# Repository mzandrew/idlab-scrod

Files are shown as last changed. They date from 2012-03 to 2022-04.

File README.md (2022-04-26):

# idlab-scrod
FPGA firmware + PC software to control and readout waveform sampling ASICs for high-energy physics experiments

This repository archives the firmware (etc) for an electronics module for Belle II bPID readout.
It consists of 128 channels of 2.7GSa/s @ 12bits per sample Wilkinson ADC readout (via 16 waveform sampling ASICs), controlled by FPGAs with data streaming out over a 2.544Gbit/s LC-LC duplex fiber optic link.
An array of 16-anode micro-channel plate photomultiplier tubes (MCP-PMTs) will be mounted to detect single photoelectrons, creating an image plane with a resolution of 64*16 pixels.
Four of these modules will be mated to a highly polished quartz bar and expansion volume.
The system is able to discern the difference between high momentum kaons and pions traveling through the bar (via a folded Cherenkov image projected on the PMTs).

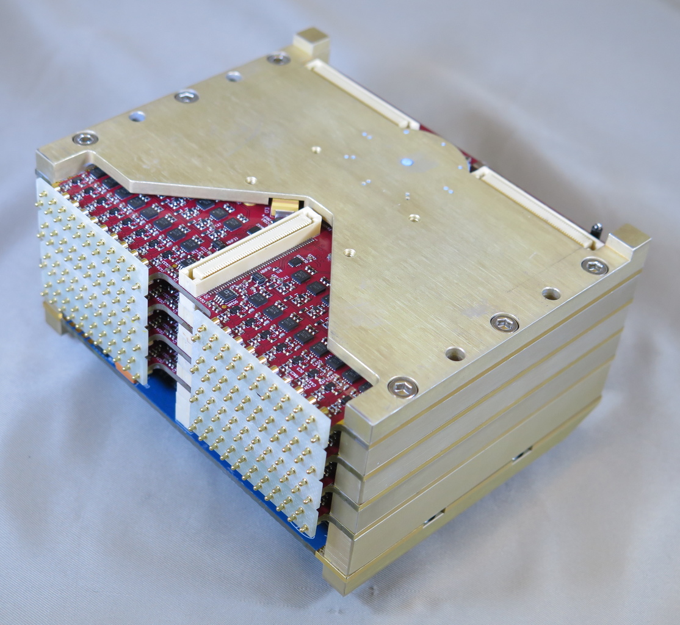
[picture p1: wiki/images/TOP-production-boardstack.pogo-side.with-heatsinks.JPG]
an electronics module for Belle II bPID readout


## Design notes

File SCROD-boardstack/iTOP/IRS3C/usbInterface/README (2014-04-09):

Installing USB interface (Linux only)

1) Install libusb:
Ubuntu: sudo apt-get install libusb-1.0-0-dev
Alternatively: 
-download stable version of libusb-1.0.x from http://www.libusb.org/ (currently libusb-1.0.9)
-follow installation instructions

2) Install ROOT:
-see http://root.cern.ch/ (tested with 5.34/03)

3) Compile code:
-go to usbInterface directory: cd usbInterface/
-compile: make

Using USB interface:

1) Attach USB cable before powering on frontend boards
-USB interface only tested with local clock, distributed FTSW clock should work but not tested

2) Check that the Cypress USB interface controller is detected:
-use lsusb to get a list of USB devices, should return: Bus ### Device ###: ID 04b4:1004 Cypress Semiconductor Corp.
-if Cypress device is not found try power cycling the board
-if Cypress firmware is not "04b4:1004", check that fw.hex file is present then reprogram firmware: 
Command: ./load_cypress_firmware
-alternatively, program the eeprom following the instructions here:
http://www.triplespark.net/elec/periph/USB-FX2/eeprom/
Software: http://www.triplespark.net/elec/periph/USB-FX2/eeprom/fxload-full-2008_10_13-ww3.tar.gz
Command: fxload -D /dev/bus/usb/002/016 -I fw.hex -c 0x01 -s Vend_Ax.hex -t fx2

3) Program FPGA (tested with bit file scrod_top_intermediatedIRS3C_20140401.bit included in top directory)

4) Initialize frontend + ASICs: ./bin/irs3BControl_initialize

5) Try reading a generial i/o register #0: ./bin/irs3BControl_readReg 0
-if there is a "Permission denied." error, give the USB interface the required permissions eg: sudo chmod a+rw /dev/bus/usb/<bus #>/<device #>

5) Try taking data: ./bin/irs3BControl_takeData
-hardcode to route calibration input to ASIC row 0 col 2 ch 2, does software triggered forced readouts on this channel
-this should display sampled waveforms one at a time

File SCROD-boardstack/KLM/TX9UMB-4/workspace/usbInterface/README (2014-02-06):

Installing USB interface (Linux only)

1) Install libusb:
Ubuntu: sudo apt-get install libusb-1.0-0-dev
Alternatively: 
-download stable version of libusb-1.0.x from http://www.libusb.org/ (currently libusb-1.0.9)
-follow installation instructions

2) Install ROOT:
-see http://root.cern.ch/ (tested with 5.34/03)

3) Compile code:
-go to usbInterface directory: cd usbInterface/
-compile: make

Using USB interface

1) Attach USB cable before powering on frontend boards
2) Program FPGA (tested on SPARTAN6 with bit file scrod_top.bit included in directory)
3) Check that the Cypress USB interface controller is detected:
-use lsusb to get a list of USB devices, should return: Bus ### Device ###: ID 04b4:1004 Cypress Semiconductor Corp.
-if Cypress device is not found try power cycling the board
-if Cypress firmware is not "04b4:1004", check that fw.hex file is present then reprogram firmware: ./load_cypress_firmware
4) Try reading a generial i/o register #0: ./bin/target6Control_readReg 0
-if there is a "Permission denied." error, give the USB interface the required permissions eg: sudo chmod a+rw /dev/bus/usb/002/005

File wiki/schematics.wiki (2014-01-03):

#summary schematics for front-end board stacks, including SCROD
#labels Deprecated

= Introduction =

This page has all the latest schematics, PCB layout files and gerbers for all front-end boards that the IDLAB has made.

== SCROD ==

[http://idlab-scrod.googlecode.com/files/2011-01-10.SCROD.revA.sch SCROD rev A schematic] ([http://idlab-scrod.googlecode.com/files/2011-01-10.SCROD.revA.schematic.pdf schematic pdf])

[http://idlab-scrod.googlecode.com/files/2011-01-10.SCROD.revA.pcb SCROD rev A batch 1 layout] ([http://idlab-scrod.googlecode.com/files/2011-01-10.SCROD.revA.layout.pdf rev A batch 1 layout pdf]) (rev A batch 1 gerbers)

[http://idlab-scrod.googlecode.com/files/2011-06-09.SCROD.revA.batch2.pcb SCROD rev A batch 2 layout] ([http://idlab-scrod.googlecode.com/files/2011-06-09.SCROD.revA.batch2.layout.pdf rev A batch 2 layout pdf]) ([http://idlab-scrod.googlecode.com/files/2011-06-09.SCROD.revA.batch2.gerbers.zip rev A batch 2 gerbers]) ([http://idlab-scrod.googlecode.com/files/2011-06-21.SCROD.revA-batch2.assembly-files.zip rev A batch 2 assembly files, including BOM])

note:  The batch 1 layout/gerbers are only different from the batch 2 layout/gerbers on the silkscreen layer.

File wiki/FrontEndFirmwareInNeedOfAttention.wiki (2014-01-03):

#summary A list of front-end firmware tasks that currently need attention:
#labels Deprecated

  * ASIC trigger width output feedback - ensure that the trigger bits out of the ASIC remain high for long enough for us to see them in the following two items.
  * Scaler rate monitors for all trigger bits - count the number of trigger edges seen.  Counter is reset by an external signal, probably a software command.
  * Trigger data stream implementation - a running "waveform" of trigger bits, see documentation page 12 ( http://www.phys.hawaii.edu/~kurtisn/documentation/bPID_electronics/2011-09-01.BelleII-bPID.electronics-documentation.pdf )
  * Merge Xiao-Wen's temperature sensor readout into main code
  * Merge Xiao-Wen's EEPROM code to set/get SCROD ID into main code.

2011-09-15 firmware block diagram (click image to download full size version):

[http://idlab-scrod.googlecode.com/files/2011-09-15.SCROD-beam-test-firmware-block-diagram.whiteboard.jpeg http://idlab-scrod.googlecode.com/files/2011-09-15.SCROD-beam-test-firmware-block-diagram.whiteboard.lowres.jpeg]

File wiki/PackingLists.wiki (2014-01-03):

#summary Items to bring to various integration tests
#labels Deprecated

The following are a list of items to bring for the following tests:

= 2011 December Fermilab beamtest =

== big things: ==

  * 350MHz scope
  * 8 cat6 cables
  * 80MHz signal generator
  * power supply (off the shelf)
  * power supply (Matt's)
  * 1 power cable bundle
  * cPCI crate + DSP_cPCI
  * SciFi (2 * eKLM_MB + 2 * budboxes)

travel toolkit with:
  * soldering irons
  * solder
  * soldering tools

== little things: ==

  * 4 * 15m fiber optic cables
  * 3 complete board stacks (1 Kurtis; 2 ??)
  * 3 populated SL10_HV rev A3 boards
  * NIM pocket pulser + spare batteries
  * voltmeter + ez-hook / sharp leads
  * loupe
  * FTSW (well packed)
  * CAMAC crate controller
  * "AMPs"
  * attenuators
  * SMA, BNC, LEMO adaptors kit
  * 2mm-SMA adaptor
  * "lots of blk & cu tape"
  * all IRS2_DC revB boards
  * tygon tubing
  * USB/cat5 cable adaptor

calibration sources:
  * 100MHz and 500 MHz oscillators
  * VCO

the following spare discrete components:
  * temperature sensors
  * IRS2_DC signal path components (AMPs, diodes, caps)
  * HV res/cap
  * 0 Ohm resistors

== things we are skipping ==
3GHz sine wave generator
fast pulser

= September 2011 - Second Nagoya Integration Trip =

  * Minimum of the following boards, debugged for shorts and opens:
    * 3x SCROD 
    * 3x Interconnect
    * 3x ASIC carrier level 0 (silkscreen not labeled with a number)
    * 4x ASIC carrier level 1 (silkscreen labeled "1")
      * (2x?) Extra temperature sensors 
    * 4x ASIC carrier level 2 (silkscreen labeled "2")
    * 4x ASIC carrier level 3 (silkscreen labeled "4")
    * 41x IRS2 Daughter cards, rev B
      * 1000x 0-ohm resistors to set DAC addresses (if not done before departure)
      * 100x Fair-rites
    * 5x Front-front boards
    * 4x Front-back boards
    * 5x HV boards
    * 1x Front-middle
  * 2x mini-USB cables
  * 2x Xilinx programmers
  * JTAG programmer with flying leads
  * 5x long (15 m) fiberoptic cables
  * Wifi router
  * HV panel (soldered to HV boards)
  * CAT-5 cable bundle
  * RJ45 crimp ends
  * RJ45 crimper
  * 32 HV cables (SHV - SHV)
  * 4x LV cables
  * Mechanical enclosure
  * Set screws
  * Screwdriver
  * Loc-tite
  * 4x fiberoptic transceivers
  * 1-2x USB hubs
  * SMA connectors
  * Vector board

= August 2011 - First Nagoya Integration Trip =

  * Mixed signal oscilloscope and probes(?)
  * Minimum of the following boards, debugged for shorts and opens:
    * 2x SCROD 
    * 2x Interconnect
    * 2x ASIC carrier level 0 (silkscreen not labeled with a number)
    * 2x ASIC carrier level 1 (silkscreen labeled "1")
    * 2x ASIC carrier level 2 (silkscreen labeled "2")
    * 2x ASIC carrier level 3 (silkscreen labeled "4")
    * 4x IRS2 Daughter cards (with or without all amplifiers TBD)
    * 1x IRS2 on BLAB3A daughter card ("golden child")
    * 2x Front-front boards
    * 2x Front-back boards
    * 2x HV boards
    * 1x Front-middle
    * 2x CLK_FIN (FIN_CLK)?
    * 1x cPCI_FIN
    * 1x FIN_USB
  * 2x mini-USB cables
  * 2x Xilinx programmers
  * JTAG programmer with flying leads
  * 1x cPCI crate
  * 2x DSP_cPCI
  * 4x short fiberoptic cables
  * 2x long fiberoptic cables
  * 1x cPCI CPU and hard drive cards
  * RJ-45 related:
    * Crimper
    * Cable (CAT-5 or CAT-6)
  * Wiener CAMAC controller
  * Power supplies??
  * High voltage supplies??

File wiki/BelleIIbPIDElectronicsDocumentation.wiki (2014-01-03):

#summary Documentation for (cosmic / beam test version as well as final version) of Belle II bPID Electronics
#labels Deprecated

=introduction=

The following is a revision history of documentation for the Belle II barrel particle identification system.  Information will change rapidly, so all documentation should be considered preliminary, unless otherwise noted.

=current version=

  * [http://www.phys.hawaii.edu/~kurtisn/doku.php?id=documentation 2012-09-24 preliminary documentation for final version of iTOP system documentation] - pre-final iTOP version

  * [http://idlab-scrod.googlecode.com/files/2011-10-16.BelleII-bPID.electronics-documentation.pdf 2011-10-16 Belle II bPID electronics documentation] - "beam-test" version - Minor development of some data packet formats.

=previous versions=

  * [http://idlab-scrod.googlecode.com/files/2011-09-10.BelleII-bPID.electronics-documentation.pdf 2011-09-10 Belle II bPID electronics documentation] - More development of raw waveform data packet format, as well as a new system block diagram.

  * [http://idlab-scrod.googlecode.com/files/2011-09-01.BelleII-bPID.electronics-documentation.pdf 2011-09-01 Belle II bPID electronics documentation] - Significant changes made to structure of document, as well as details on raw data formats.  This version is specifically about the cosmic / beam test version of the electronics with a deemphasized verbiage 

  * [http://idlab-scrod.googlecode.com/files/2011-07-08.BelleII-bPID.electronics-documentation.pdf 2011-07-08 Belle II bPID electronics documentation] - Changes to communication packet formats.

  * [http://idlab-scrod.googlecode.com/files/2011-06-03.BelleII-bPID.electronics-documentation.pdf 2011-06-03 - First version of Belle II bPID electronics documentation] - Includes overview information and descriptions of the front and back-end electronics, as well as the data format proposed for beam test later this year.  Sections on trigger and support electronics are currently empty, as well as the current schedule and milestones.

The original version of this page (now outdated) is located [http://www.phys.hawaii.edu/~kurtisn/documentation/bPID_electronics/ here].

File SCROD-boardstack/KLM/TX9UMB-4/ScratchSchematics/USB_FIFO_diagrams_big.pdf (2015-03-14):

# fifo_wr32_rd16

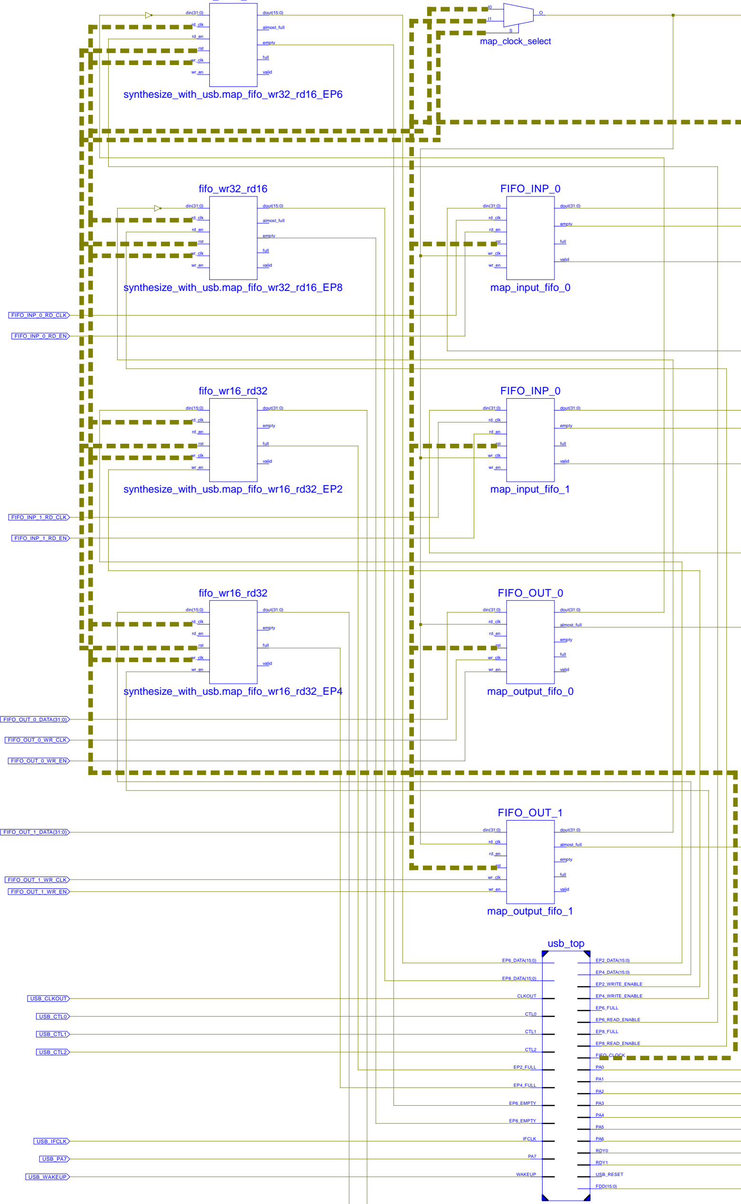
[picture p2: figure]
din(31:0); rd_clk; rd_en rst wr_clk wr_en; dout(15:0); almost_full; empty; full; valid; fifo_wr32_rd16; fifo_wr16_rd32; din(15:0); dout(31:0); map_clock_select; FIFO_INP_0; map_input_fifo_0; map_input_fifo_1; FIFO_OUT_0; map_output_fifo_0; FIFO_OUT_1; map_output_fifo_1; usb_top; EP6_DATA(15:0); EP8_DATA(15:0); CLKOUT; CTL0; CTL1; CTL2; EP2_FULL; EP4_FULL; EP6_EMPTY; EP8_EMPTY; IFCLK; PA7 WAKEUP; EP2_DATA(15:0) EP4_DATA(15:0) EP2_WRITE_ENABLE; EP4_WRITE_ENABLE; EP6_FULL EP6_READ_ENABLE; EP8_FULL EP8_READ_ENABLE; FIFO_CLOCK; FDD(15:0); FIFO_INP_0_RD_CLK; FIFO_INP_0_RD_EN; FIFO_INP_1_RD_CLK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

# synthesize_with_usb.map_fifo_wr32_rd16_EP6

# synthesize_with_usb.map_fifo_wr32_rd16_EP8

# synthesize_with_usb.map_fifo_wr16_rd32_EP2

# synthesize_with_usb.map_fifo_wr16_rd32_EP4

# bufgmux

# synthesize_with_usb.map_usb_interface

# PA0 PA1 PA2 PA3 PA4 PA5 PA6 RDY0 RDY1 USB_RESET

# lut2

# Mmux_internal_FIFO_INP_1_WRITE_DATA71

I0

I1 | O

# lut2

# Mmux_internal_FIFO_INP_0_WRITE_DATA121

I0

I1 | O

### FIBER_0_TXP

### USB_FIFO_CLOCK

### FIFO_INP_0_DATA(31:0)

### FIFO_INP_0_EMPTY

### FIFO_INP_0_VALID

### FIFO_INP_1_DATA(31:0)

### FIFO_INP_1_EMPTY

### FIFO_INP_1_VALID

### FIFO_OUT_0_FULL

### FIFO_OUT_1_FULL

# USB_PA0 USB_PA1 USB_PA2 USB_PA3 USB_PA4 USB_PA5 USB_PA6 USB_RDY0 USB_RDY1

### USB_FDD(15:0)

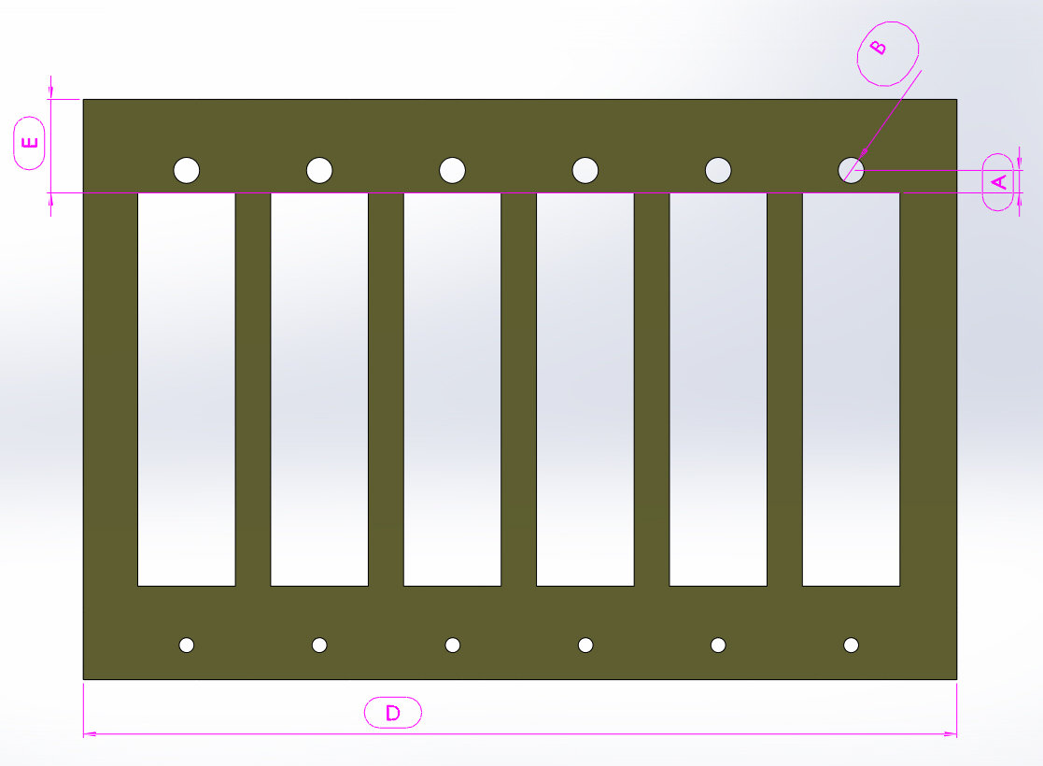
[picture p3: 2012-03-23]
mechanical-designs/board-stack/fDIRC/images/G10-frame.JPG

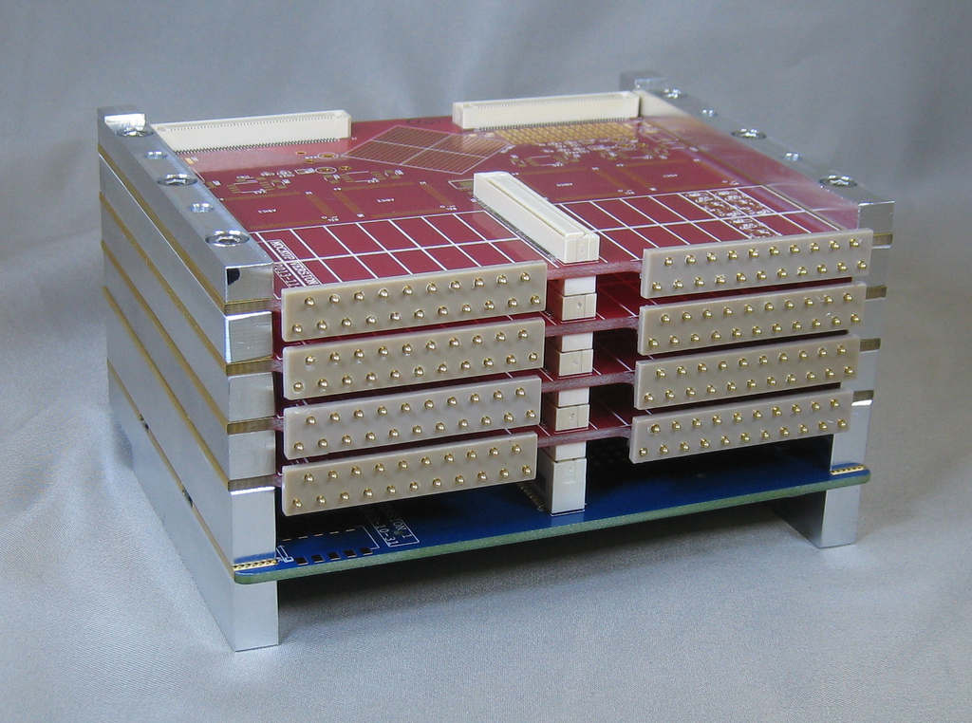
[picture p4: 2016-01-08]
wiki/images/2013-12-03.mechanical-mockup.JPG

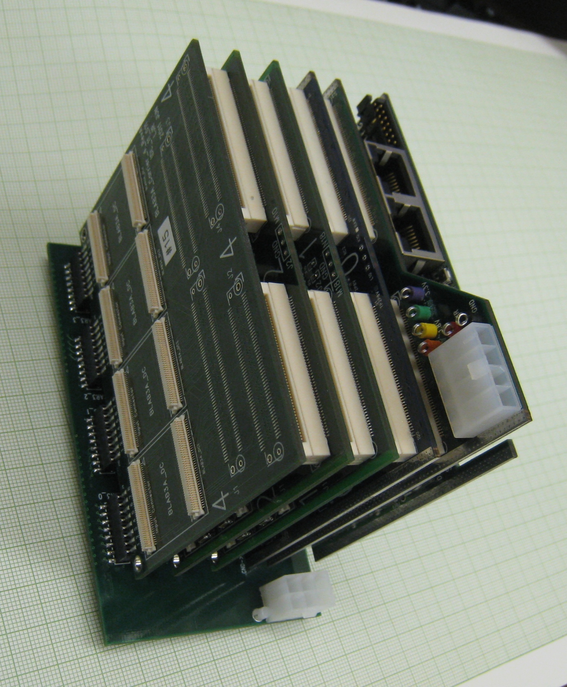
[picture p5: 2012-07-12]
mechanical-designs/board-stack/fDIRC/images/2012-06-04.fDIRC-module.jpeg

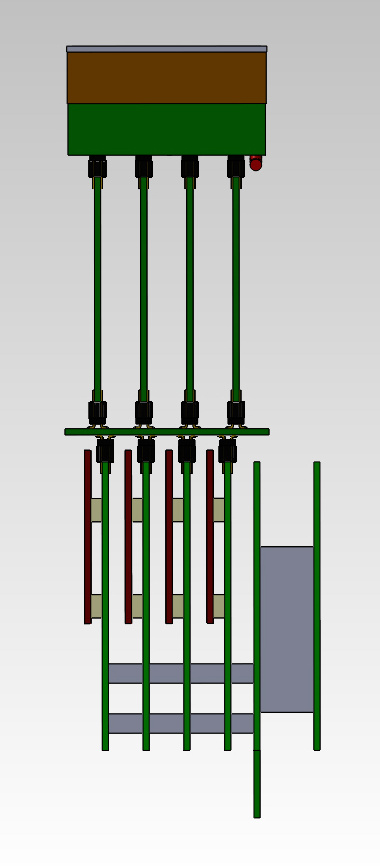
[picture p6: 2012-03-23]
mechanical-designs/board-stack/fDIRC/images/fDIRC.JPG

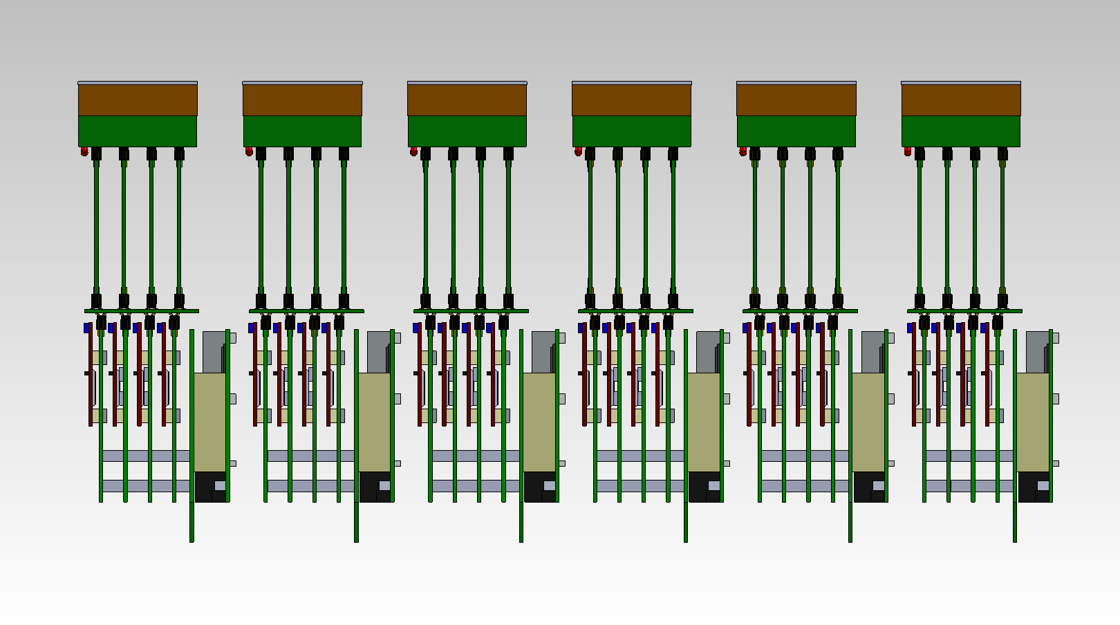
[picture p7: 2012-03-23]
mechanical-designs/board-stack/fDIRC/images/fDIRC-array.JPG

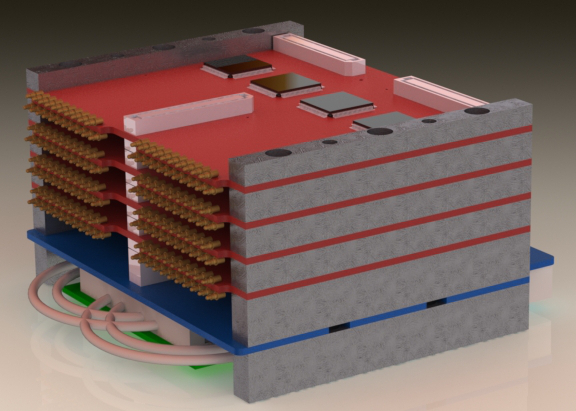
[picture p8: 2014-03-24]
mechanical-designs/board-stack/iTOP/export/SCROD-and-carriers-with-walls.rendered.JPG

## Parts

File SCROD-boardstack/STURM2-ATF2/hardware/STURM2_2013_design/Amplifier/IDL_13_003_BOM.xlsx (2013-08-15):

Item | Qty | Reference designators | Part Name | Value | Size / footprint | Part Description | manufacturer | Manufacturer part # | distributor | Distributor P/N | Assembly comments
1 | 1 | U1 | ABA-31563 | ABA-31563 | SOT-363 | IC AMP RFIC 3.5GHZ 3V SOT-363 | Avago Technologies US Inc. (http://digikey.com/Suppliers/us/Avago-Technologies.page?lang=en) | ABA-31563-TR1G | Digikey | 516-1490-1-ND
2 | 2 | U3-U4 | AMP_CONN |  |  | CONN HEADER 2MM VERT AU 4POS | Harwin Inc (http://digikey.com/Suppliers/us/Harwin.page?lang=en) | M22-2510405 | Digikey | 952-1313-ND | Trough hole. Must be aligned within 2 degrees
3 | 3 | C1-3 | C0201,1000pF | 1000pF | C0201 (0603 Metric) | CAP CER 1000PF 16V 10% X7R 0201 | TDK Corporation (http://digikey.com/Suppliers/us/TDK.page?lang=en) | C0603X7R1C102K | Digikey | 445-6844-1-ND
4 | 2 | C4-5 | CAP0603,1uF | 1uF | C0603 (1608 Metric) | CAP CER 1UF 25V Y5V 0603 | TDK Corporation (http://digikey.com/Suppliers/us/TDK.page?lang=en) | C1608Y5V1E105Z | Digikey | 445-3452-1-ND
5 | 1 | L1 | IND-MOLDED,620nH | 620nH | ind_1008 (2520 Metric) | MOLDED INDUCTOR, 0.5 PIN SPACING" | Abracon Corporation (http://digikey.com/Suppliers/us/Abracon.page?lang=en) | AISC-1008-R62J-T | Digikey | 535-10549-1-ND
6 | 1 | U2 | LAT-2 | LAT-2+ | MMM168 (http://www.minicircuits.com/case_styles/MMM168.pdf) | FXD ATTEN / SURF MT / RoHS | mini-circuits | LAT-2+ | mini-circuits | LAT-2+ (http://www.minicircuits.com/MCLStore/ModelPriceDisplay)
7 | 1 | N1 | STLQ015XX | STLQ015xx | SOT-666 | IC REG LDO 3V 0.15A SOT666 | STMicroelectronics (http://digikey.com/Suppliers/us/STMicroelectronics.page?lang=en) | STLQ015XG30R | Digikey | 497-10547-1-ND
8 | 2 | M1-2 | UMCC_RECEPTACLE | H11891TR |  | UMCC PCB RECEPTACLE STYLE A | Hirose Electric Co Ltd (http://digikey.com/Suppliers/us/Hirose-Electric.page?lang=en) | U.FL-R-SMT-1(10) | Digikey | H11891TR-ND

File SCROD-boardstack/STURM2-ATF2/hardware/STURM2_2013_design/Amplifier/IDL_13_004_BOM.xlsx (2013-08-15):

Item | Qty | Reference designators | Part Name | Value | size / footprint | Description | manufacturer | manufacturer part # | distributor | distributor part p/n | assembly comments
1 | 1 | AMP_5V | 6PIN_MOLEX |  |  | CONN HEADER 6POS MATE-N-LOK AU | TE Connectivity | 1586526-2 | digikey | 1586526-2-ND
2 | 48 | AMP1-48 | AMP_CONNECTOR2 |  |  | CONN RECEPT 2MM VERT AU 4POS | Harwin Inc | M22-7130442 | digikey | 952-1351-5-ND
3 | 16 | V1-16 | MCP1702 |  | SOT-23A-3 | IC REG LDO 4V 0.25A SOT89-3 | Microchip Technology (http://digikey.com/Suppliers/us/Microchip-Technology.page?lang=en) | MCP1702T-4002E/CB | digikey | MCP1702T-4002E/CBCT-ND
Number of boards / device
5

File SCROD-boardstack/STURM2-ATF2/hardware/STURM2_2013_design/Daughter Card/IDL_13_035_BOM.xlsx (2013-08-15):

Item | Qty | Reference designators | Part Name | value | size / footprint | part Description | manufacturer | manufacturer part # | distributor | distributor p /n | Assembly comments
1 | 3 | U1-3 | AD5324 | AD5324 | 10-MSOP (0.118", 3.00mm Width) | IC DAC 12BIT QUAD VOUT 10-MSOP | Analog Devices Inc | AD5324BRMZ | digikey | AD5324BRMZ-ND
2 | 12 | C2 C4 C6 C13-14 C16 C19-20 C23-24 C27 C29 | CAP0603,0.1uF | 0.1uF | C0603 | CAP CER 0.1UF 25V 10% X7R 0603 | TDK Corporation | C1608X7R1E104K080AA | digikey | 445-1316-1-ND
3 | 1 | C30 | CAP0603,150pF | 150pF | C0603 | CAP CER 150PF 50V 10% X7R 0603 | TDK Corporation | GRM188R71H102KA01D | digikey | 490-1494-1-ND
4 | 15 | C1 C3 C5 C7 C9 C11-12 C15 C17-18 C21-22 C25-26 C31 | CAP0603,10uF | 10uF | C0603 | CAP CER 10UF 6.3V 10% X5R 0603 | TDK Corporation | C1608X5R0J106K080AB | digikey | 445-7492-1-ND
5 | 3 | C8 C10 C32 | CAP1206,100uF | 100uF | C1206 | CAP CER 100UF 6.3V Y5V 1206 | TDK Corporation | GRM31CF50J107ZE01L | digikey | 490-4512-1-ND
6 | 1 | CP2_SOCKET | CP2_SOCKET |  |  | 3M™ CP2 PRESS-FIT SOCKET | TE Connectivity | 5352068-9 | digikey | 5352068-9-ND
7 | 1 | V3 | MCP1826S-2502E |  | TO-261AA | IC LDO REG 1A 2.5V SOT223-3 | Microchip Technology (http://digikey.com/Suppliers/us/Microchip-Technology.page?lang=en) | MCP1826S-2502E/DB | digikey | MCP1826S-2502E/DB-ND
8 | 2 | V1-2 | MCP1826T-ADJE |  | SOT-223-6 | IC LDO REG 1A ADJ-V SOT223-5 | Microchip Technology (http://digikey.com/Suppliers/us/Microchip-Technology.page?lang=en) | MCP1826T-ADJE/DC | digikey | MCP1826T-ADJE/DCCT-ND
9 | 1 | V4 | LMV321WG-7 |  | SOT25 | IC OPAMP R-R OUT 1MHZ SOT25 | Diodes Inc | LMV321WG-7 | digikey | LMV321WG-7DIDKR-ND
10 | 3 | R4-5 R9 | RES0603,10k | 10K | R0603 | RES 10K OHM 1/10W 5% 0603 | Stackpole Electronics Inc (http://digikey.com/Suppliers/us/Stackpole-Electronics.page?lang=en) | RMCF0603JT10K0 | digikey | RMCF0603JT10K0CT-ND
11 | 1 | R7 | RES0603,12k | 12K | R0603 | RES 12K OHM 1/10W 5% 0603 | Stackpole Electronics Inc (http://digikey.com/Suppliers/us/Stackpole-Electronics.page?lang=en) | RMCF0603JT12K0 | digikey | RMCF0603JT12K0CT-ND
12 | 1 | R8 | RES0603,18k | 18K | R0603 | RES 18K OHM 1/10W 1% 0603 | Stackpole Electronics Inc | RMCF0603FT14K3 | digikey | RMCF0603FT14K3CT-ND
13 | 1 | R2 | RES0603,200k | 200K | R0603 | RES 200K OHM 1/10W 5% 0603 | Stackpole Electronics Inc | RMCF0603JT200K | digikey | RMCF0603JT200KCT-ND
14 | 2 | R1 R3 | RES0603,20k | 20K | R0603 | RES 20K OHM 1/10W 5% 0603 | Stackpole Electronics Inc | RMCF0603JT20K0 | digikey | RMCF0603JT20K0CT-ND
15 | 1 | R6 | RES0603,23.2k | 23.2K | R0603 | RES 23.2K OHM 1/10W 1% 0603 | Stackpole Electronics Inc | RMCF0603FT23K2 | digikey | RMCF0603FT23K2CT-ND
16 | 2 | R10 R11 | RES0603,50 | 50 | R0603 | RES 50 OHM 125MW +/-5% 0603 SMD | Vishay Thin Film (http://digikey.com/Suppliers/us/Vishay-Thin-Film.page?lang=en) | FC0603E50R0JST1 | digikey | FC0603E50R0JST1-ND
17 | 1 | STURM2 | STURM2 | STURM2 | TQFP100 | STURM2 ASIC
18 | 4 | RAMP VPED GND TSA0 | TH_TESTPT |  | SIP-1P | TEST POINT | Keystone Electronics | 5008 | digikey | 5008K-ND
19 | 1 | U4 | TN2-5V |  | TN2-5V | RELAY SLIM VERT 1A 5VDC PC MNT | Panasonic Electric Works (http://digikey.com/Suppliers/us/Panasonic-Electric-Works.page?lang=en) | TN2-5V | digikey | 255-1022-5-ND
20 | 8 | RF1-8 | UMCC_RECEPTACLE | H11891TR | UMCC_RECEPTACLE | UMCC PCB RECEPTACLE STYLE A | Hirose Electric Co Ltd | U.FL-R-SMT-1(10) | digikey | H11891TR-ND
21 | 1 | Q1 | ZVN3306 |  | SOT-23-3 | MOSFET N-CH 60V 150MA SOT23-3 | Diodes Inc (http://digikey.com/Suppliers/us/Diodes.page?lang=en) | ZVN3306FTA | digikey | ZVN3306FCT-ND
22 | 1 | Q2 | ZVP3306F |  | SOT-23-3 | MOSFET P-CH 60V 90MA SOT23-3 | Diodes Inc (http://digikey.com/Suppliers/us/Diodes.page?lang=en) | ZVP3306FTA | digikey | ZVP3306FCT-ND
 |  | DO NOT INSTALL LIST |  | SMT | 60
 | 1 | CP2_SOCKET |  | Trought hole | 6
 | 4 | RAMP, VPED, GND, TSA0 |  | Total | 66
 | 5 | TOTAL DNI

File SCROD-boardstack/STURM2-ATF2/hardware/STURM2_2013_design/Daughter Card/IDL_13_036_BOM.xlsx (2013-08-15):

Item | Qty | Reference designators | Part Name | Value | Size / Footprint | Description | Manufacturer | Manufacturer part nro | Distributor | Distributor part nro | Assembly comments
1 | 1 | AMP_5V | 6PIN_MOLEX |  |  | CONN PLUG 6 POS MATE-N-LOK | TE Connectivity | 1-480270-0 | Digikey | A1413-ND | DNI
2 | 1 | SCROD_TEST1 | 8SIG_MON_1X4 |  |  |  |  |  | Digikey |  | DNI
3 | 1 | V3 | ADP3338AKCZ-2.5RL7 |  | SOT223 | IC REG LDO 1A PREC 2.5V SOT-223 | Analog Devices Inc | ADP3338AKCZ-2.5RL7 | Digikey | ADP3338AKCZ-2.5RL7CT-ND
4 | 1 | V2 | ADP3338AKCZ-3.3RL7 |  | SOT223 | IC REG LDO 1A PREC 3.3V SOT-223 | Analog Devices Inc | ADP3338AKCZ-3.3RL7 | Digikey | ADP3338AKCZ-3.3RL7CT-ND
5 | 2 | C5-6 | CAP0603,100uf | 100uF | 1206 | CAP CER 100UF 6.3V Y5V 1206 | TDK Corporation | GRM31CF50J107ZE01L | Digikey | 490-4512-1-ND
6 | 4 | C1-4 | CAP0603,1uF | 1uF | 603 | CAP CER 1UF 25V Y5V 0603 | TDK Corporation | C1608Y5V1E105Z | Digikey | 445-3452-1-ND
8 | 8 | STURM2_DC_1-8 | CP2_HEADER |  |  | CONN HEADER 154POS VERT 2MM | TE Connectivity | 5100668-1 | Digikey | A97847-ND | DNI
9 | 1 | V5 | AP1122EG-13 |  | SOT223 | IC REG LDO 1.2V 1A SOT223-3 | Diodes Inc | AP1122EG-13 | Digikey | AP1122EGDICT-ND
11 | 1 | SCROD1 | SCROD |  |  | SCROD |  |  | Digikey
12 | 4 | COMMON_CLOCK SMA1-3 | SMA |  |  | CONN JACK SMA 50 OHM EDGE MOUNT |  |  | Digikey |  | DNI
13 | 5 | GND PWR1-4 | TH_TESTPT |  | SIP-1P | TEST POINT PC COMPACT .063"D ORN | Keystone Electronics | 5008 | Digikey |  | DNI
 | Qty | DO NOT INSTALL LIST |  | SMT | 14
 | 1 | AMP_5V |  | Trought hole | 15
 | 1 | SCROD_TEST1 |  | Total | 29
 | 8 | STURM2_DC_1-8
 | 1 | COMMON_CLOCK
 | 3 | SMA1-3
 | 5 | TH_TESTPT
 | 19 | TOTAL DNI

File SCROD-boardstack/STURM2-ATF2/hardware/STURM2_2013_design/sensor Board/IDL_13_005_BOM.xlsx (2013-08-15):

Item | Qty | RefDes | Part Name | Manufacturer | Description | Digikey part nro
1 | 1 | C2 | CAP0603,1.6pF | TDK Corporation | CAP CER 1.6PF 25V NP0 0201 | 445-7050-1-ND
2 | 12 | M1-12 | MOUNTING-HOLE-6-32 |  | MOUNTING-HOLE-6-32
3 | 1 | CPG18020 | PGA_SOCKET_15X15 | Aries Electronics | ZIF PGA SOCKET 225 PIN 15 X 15 | A315-ND
4 | 1 | R67 | RES0603,1k | TE Connectivity. | RES 1.00K OHM 1/10W 1% 0603 | A106049CT-ND
5 | 64 | R1-64 | RES0603,50 | TE Connectivity. | RES 50 OHM 1/10W 1% 0603 | FC0603E50R0JST1-ND
6 | 2 | DOWNBONDS VPED | SMA | Emerson Network Power Connectivity Johnson | CONN JACK SMA 50 OHM EDGE MOUNT | J502-ND
7 | 64 | U1-64 | UMCC_RECEPTACLE | Hirose Electric Co Ltd | CONN UMC JACK STR 50 OHM SMD | H11891TR-ND

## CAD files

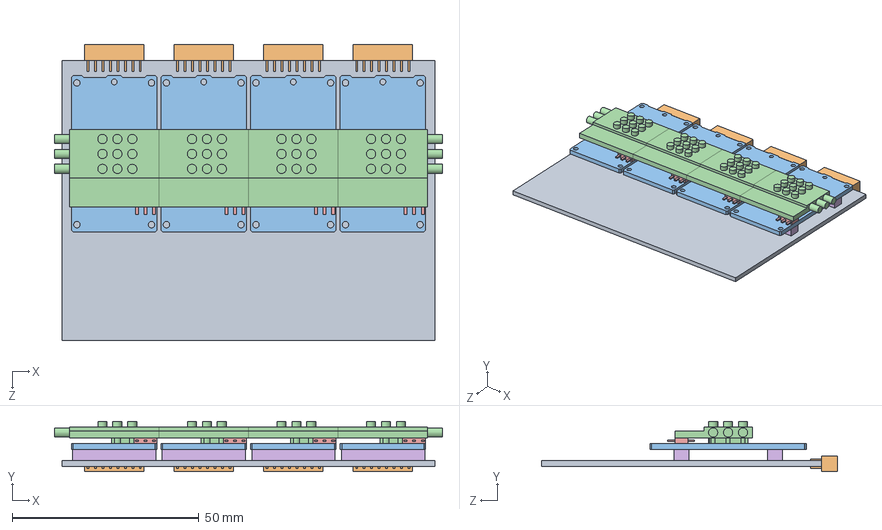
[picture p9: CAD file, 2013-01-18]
mechanical-designs/board-stack/carriers/carrier.common.SLDASM
104.0 x 13.5 x 79.2 mm
carrier.common
connector.2mm.16-pin.female x 4
IRS2_DC.revB2 x 4
IRS2_DC.revB2.heatsink x 4
SOT-223 x 4
80-pin-connectors x 4

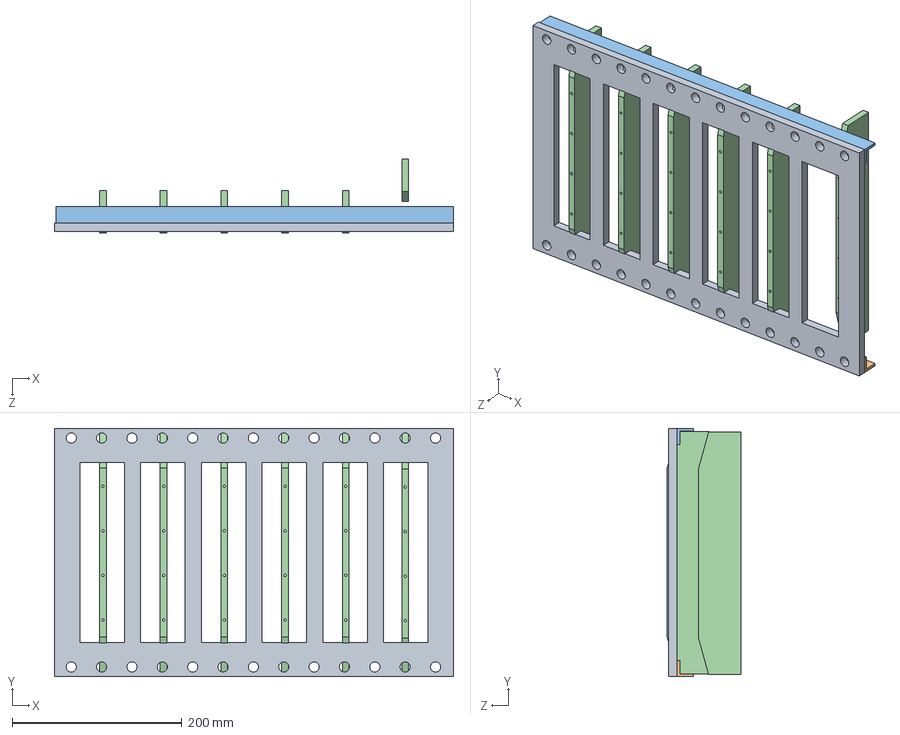
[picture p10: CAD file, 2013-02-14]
mechanical-designs/board-stack/fDIRC/existing-support-structure/fDIRC-frame.SLDASM
469.9 x 292.1 x 86.9 mm
G10-frame
angle-aluminum-with-holes.bottom
angle-aluminum-with-holes.top
G10-PMT-support x 6

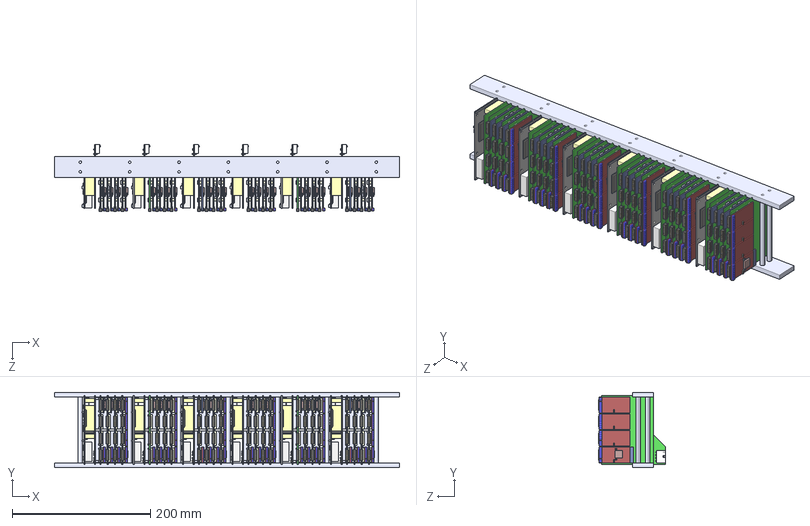
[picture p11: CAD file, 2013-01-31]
mechanical-designs/board-stack/fDIRC/export/fDIRC-assembly.STEP
500.0 x 108.7 x 96.8 mm
carrier.common x 24
IRS2_DC.revB x 42
IRS3_DC.revA x 42
IRS3_DC.heatsink x 42
1206.inductor x 84
connector.2mm.16-pin.female x 96
carrier04-capacitors x 12
board-interconnects.100-and-120-pin.9mm x 18
carrier12-capacitors x 12
interconnect.revB x 6
board-interconnects.100-and-120-pin.6mm x 6
mini-fit-jr.right-angle.4-position x 6
SCROD.revA2 x 6
SCROD.components x 6
top_strip
bottom_strip
mount-dowels

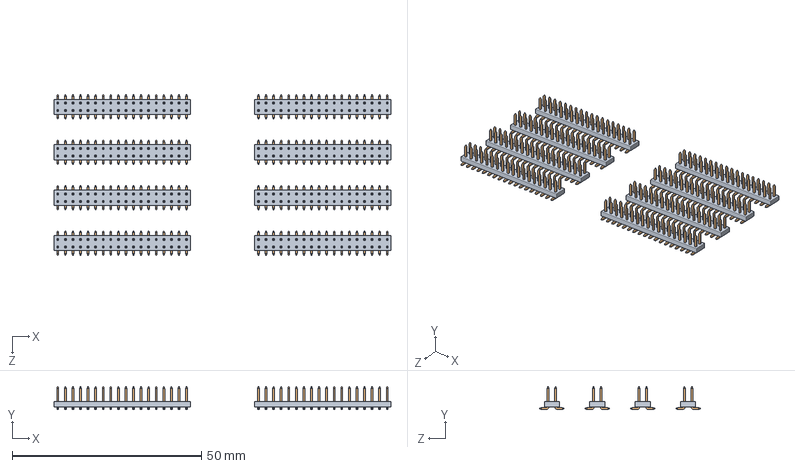
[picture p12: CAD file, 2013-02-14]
mechanical-designs/board-stack/fDIRC/H8500-front.components-front.SLDASM
89.0 x 6.10 x 42.5 mm
connector.2mm.36-pin.male x 8
2mm-connector-male-pin-surface-mount.pair.2 x 144

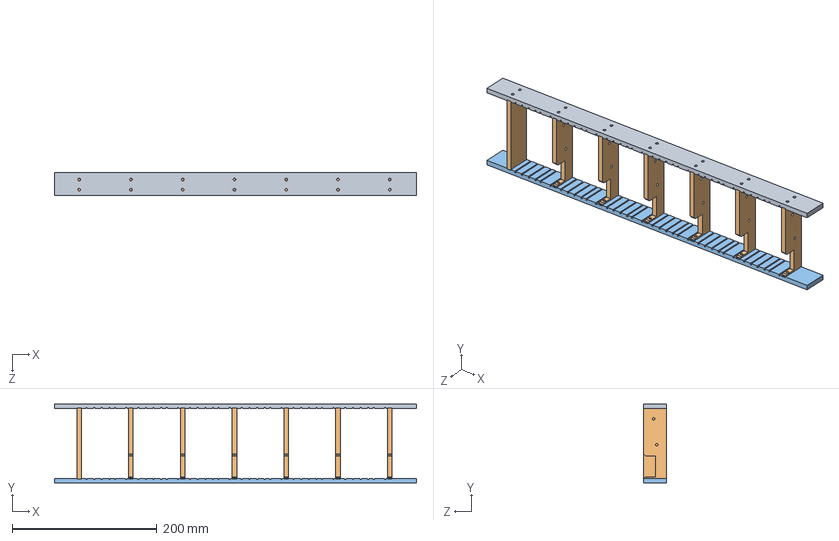
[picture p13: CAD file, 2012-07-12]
mechanical-designs/board-stack/fDIRC/mechanical-mount-for-6-boardstacks/mount.sldasm
500.0 x 108.7 x 31.8 mm
top_strip
mount-slats
bottom_strip

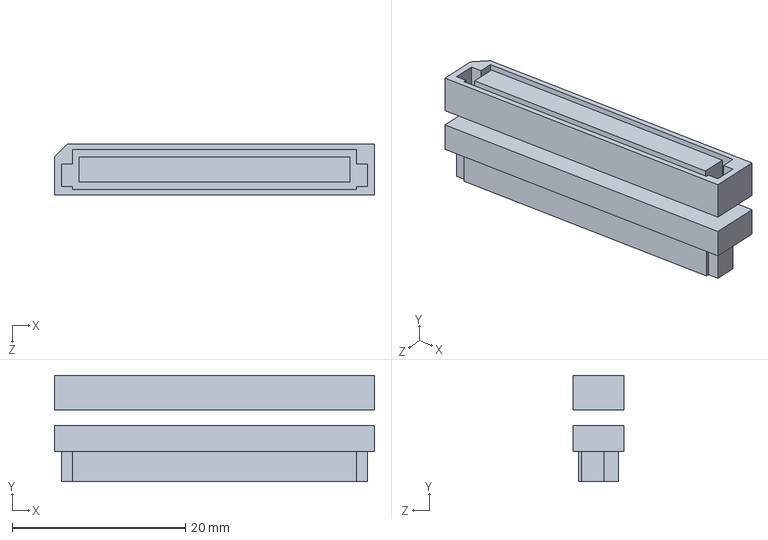
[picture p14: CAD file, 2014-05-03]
mechanical-designs/board-stack/FX8C-board-to-board-interconnects.SLDASM
36.9 x 12.3 x 5.90 mm

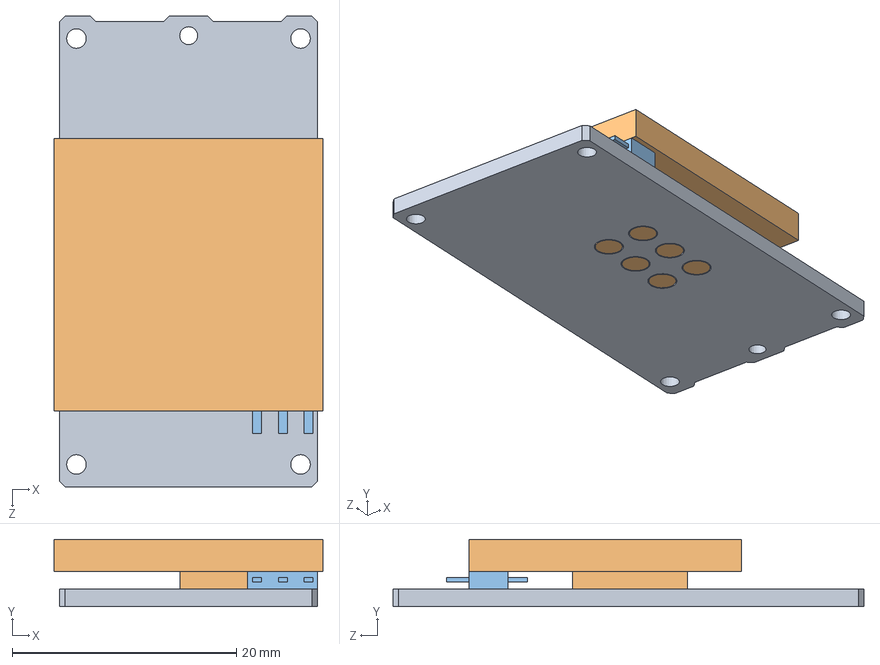
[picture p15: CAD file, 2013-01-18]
mechanical-designs/board-stack/IRS2_DC.revB2/IRS2_DC.revB2.SLDASM
24.0 x 6.00 x 42.0 mm
IRS2_DC.revB2
IRS2_DC.revB2.heatsink
SOT-223

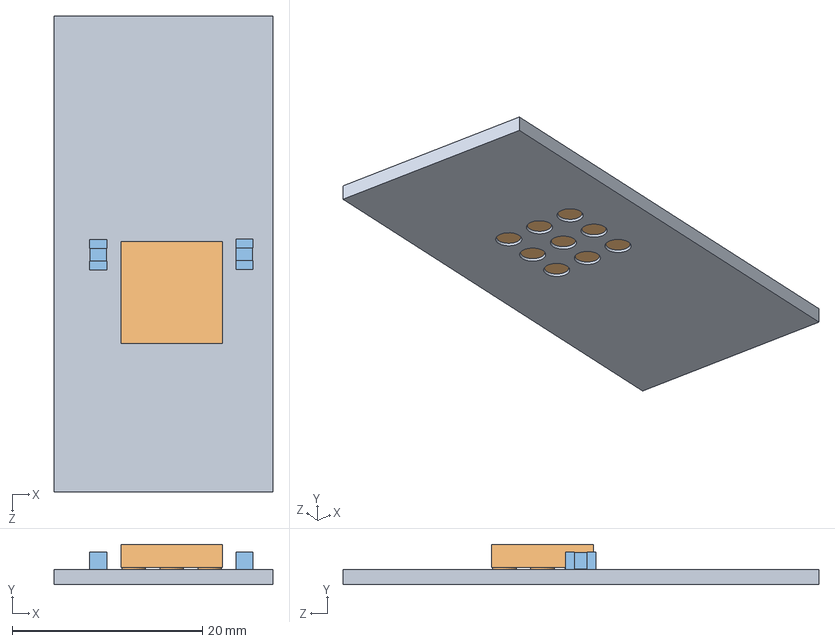
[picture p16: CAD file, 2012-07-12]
mechanical-designs/board-stack/IRS3_DC.revA/IRS3_DC.SLDASM
23.0 x 4.24 x 50.0 mm
IRS3_DC.revA
IRS3_DC.heatsink
1206.inductor x 2

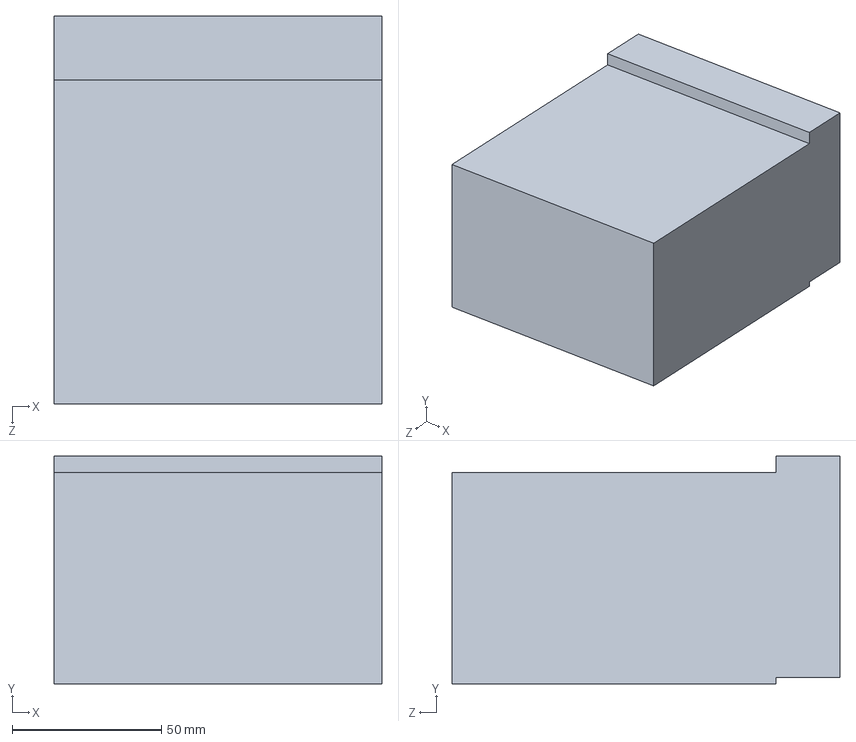
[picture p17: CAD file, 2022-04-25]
mechanical-designs/board-stack/iTOP/bounding-box-for-SCROD-and-carriers-with-walls-and-HV-and-front-PMT-PEEK-assembly.sldprt
110.0 x 76.4 x 130.1 mm

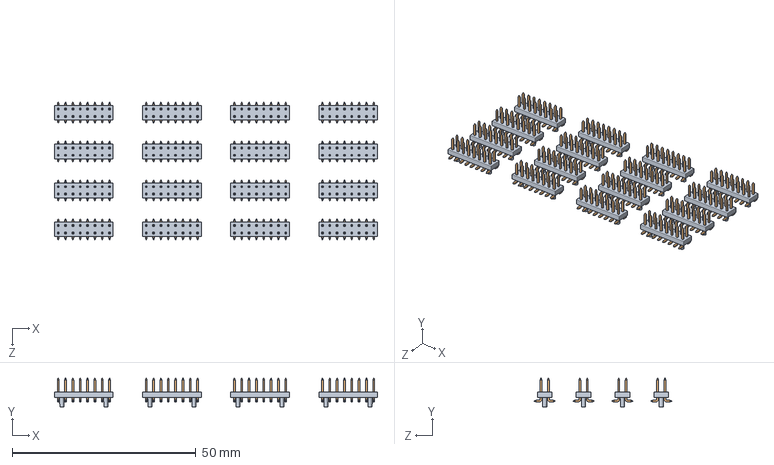
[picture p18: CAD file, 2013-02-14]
mechanical-designs/board-stack/mTC/front.components-back.SLDASM
88.0 x 7.84 x 37.5 mm
connector.2mm.16-pin.male x 16
2mm-connector-male-pin-surface-mount.pair.1 x 128

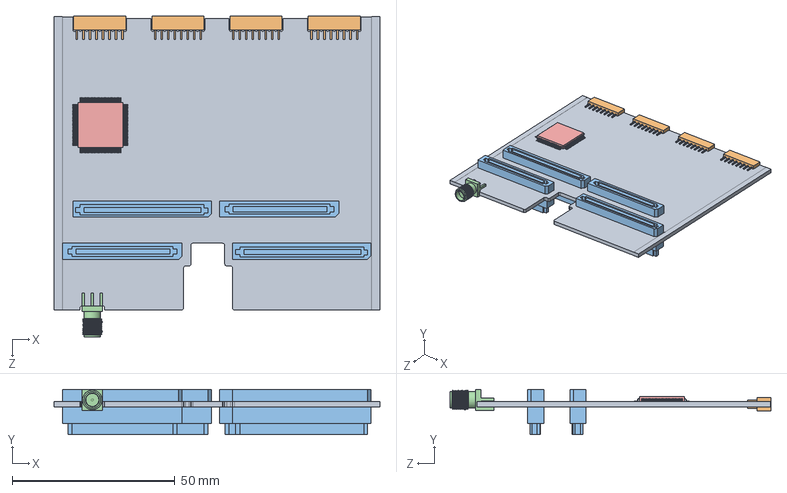
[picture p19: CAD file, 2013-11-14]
mechanical-designs/tags/r282.iTOP-module-used-at-LEPS-SPRING8/board-stack/carriers/carrier13.revB.SLDASM
100.1 x 13.9 x 98.5 mm
carrier13.revB.PCB
connector.2mm.16-pin.female x 4
board-interconnects.100-and-120-pin.bottom-SV4.top-SV.carrier13
SMA.PC-edge-mount.short
TQFP-128

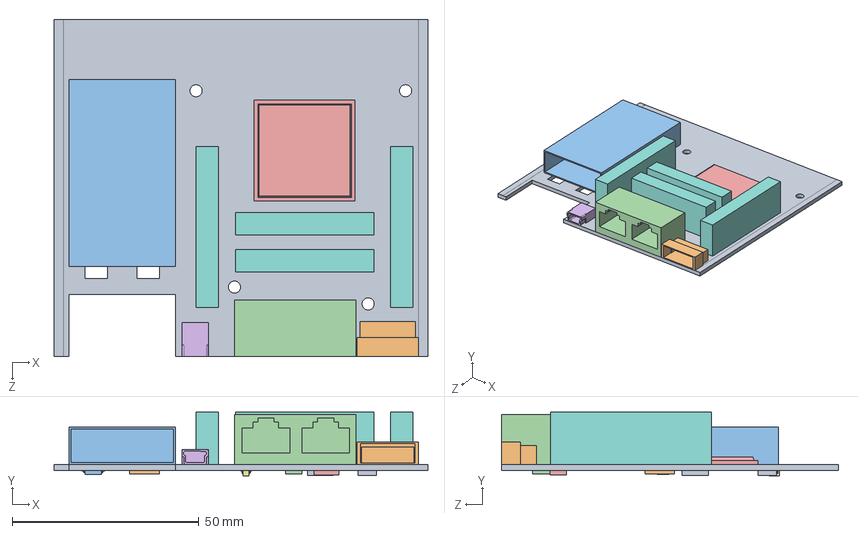
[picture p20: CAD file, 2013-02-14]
mechanical-designs/tags/r282.iTOP-module-used-at-LEPS-SPRING8/board-stack/concepts/SCROD.revB.SLDASM
100.0 x 17.1 x 90.0 mm
SCROD.revB
14-pin.2mm.jtag-header.right-angle
fiber-cage.double-wide
RJ45.surface-mount.double-wide
spartan6.676-FGG
USB-mini
SOT23-5
board-to-board-interconnects.SCROD-pattern
5mm-by-7mm.oscillator x 2
8mm-by-8mm.cypress
TSSOP-8
TSSOP-16
TSSOP-20

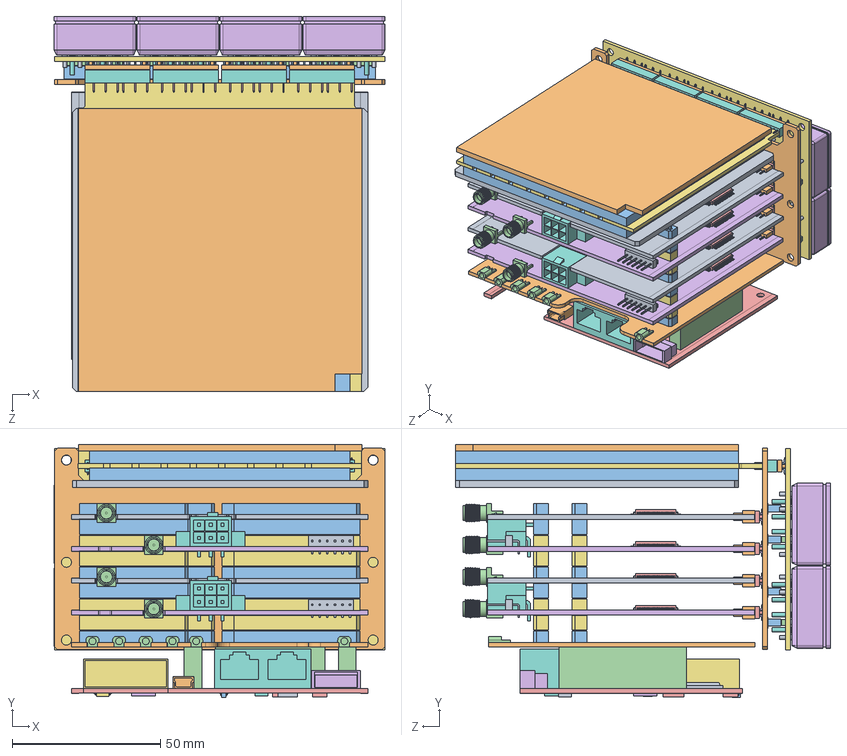
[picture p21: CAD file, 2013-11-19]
mechanical-designs/tags/r282.iTOP-module-used-at-LEPS-SPRING8/board-stack/iTOP/iTOP.SLDASM
111.7 x 85.5 x 126.6 mm
carrier13.revB.PCB x 2
connector.2mm.16-pin.female x 16
board-interconnects.100-and-120-pin.bottom-SV4.top-SV.carrier13 x 2
SMA.PC-edge-mount.short x 4
TQFP-128 x 16
carrier02.revB.PCB x 2
board-interconnects.100-and-120-pin.bottom-SV4.top-SV.carrier02 x 2
molex-mini-fit-jr-6-pin-right-angle.simplified x 2
6-pin-0.1-inch-right-angle x 2
interconnect.revC
board-interconnects.100-and-120-pin.bottom-SV4.top-SV.interconnect
MMCX-board-edge-cutout x 6
SCROD.revA2
14-pin.2mm.jtag-header.right-angle
fiber-cage.double-wide
RJ45.surface-mount.double-wide
spartan6.676-FGG
USB-mini
SOT23-5
board-to-board-interconnects.SCROD-pattern
5mm-by-7mm.oscillator x 2
8mm-by-8mm.cypress
TSSOP-8
TSSOP-16
TSSOP-20
front-back.revC
connector.2mm.09-pin.male.2 x 16
surface-mount-2mm-pin-socket-tab x 144
connector.2mm.16-pin.male x 16
2mm-connector-male-pin-surface-mount.pair.1 x 128
front-front.revC
pin-socket.ED5008 x 128
pin-socket.ED5044 x 64
connector.2mm.22-pin.male x 4
2mm-connector-male-pin-surface-mount.3 x 48
connector.2mm.09-pin.male.1 x 16
2mm-connector-male-pin-through-hole.chopped-off.3 x 192
SL10.4x4 x 8
SL10-HV-module.revA.IU.PCB
connector.2mm.22-pin.female x 4
SL10-HV-module.revA.IU.bottom-plate
SL10-HV-module.revA.IU.top-plate
SL10-HV-module.revA.IU.gap-pad x 2

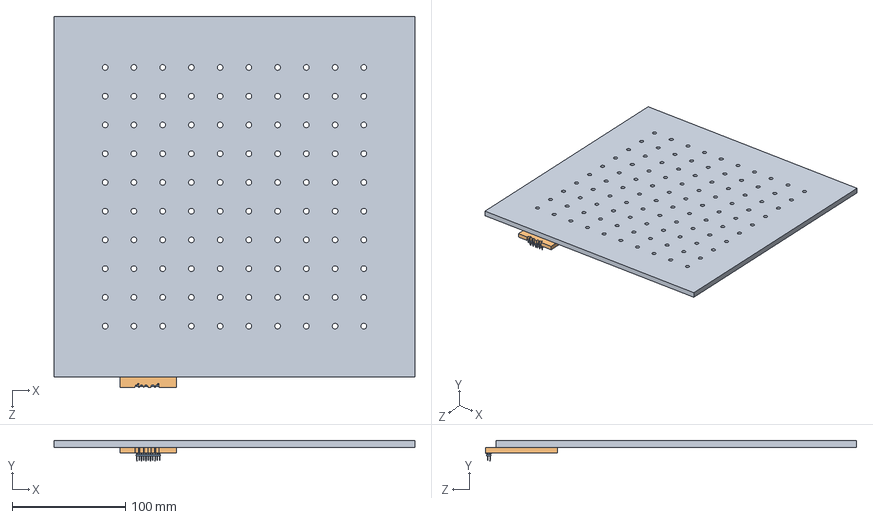
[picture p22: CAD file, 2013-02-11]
mechanical-designs/tags/r282.iTOP-module-used-at-LEPS-SPRING8/common-components/jigs/22pin-2mm-pin-puller.SLDASM
318.6 x 17.8 x 327.8 mm
optical-table
22pin-2mm-pin-puller
connector.2mm.22-pin.male
2mm-connector-male-pin-surface-mount.3 x 12

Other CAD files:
mechanical-designs/board-stack/fDIRC/existing-support-structure/G10-frame.SLDASM
mechanical-designs/board-stack/fDIRC/H8500-amp.revB.SLDASM
mechanical-designs/board-stack/iTOP/contrib/front-board.SLDASM
SCROD-boardstack/KLM/TX9UMB-4/src/picoblaze/command_interpreter/command_interpreter.psm
SCROD-boardstack/iTOP/IRS3C/src/picoblaze/command_interpreter/command_interpreter.psm
mechanical-designs/COPPER/COPPER-CRATE.SLDPRT
mechanical-designs/COPPER/COPPER-CRATE.with-COPPER-PCB-and-RTM.SLDASM
mechanical-designs/COPPER/COPPER-PCB.9U-VME.SLDPRT
mechanical-designs/COPPER/COPPER-RTM.SLDPRT
mechanical-designs/board-stack/IRS2_DC.revB/IRS2_DC.revB.SLDPRT
mechanical-designs/board-stack/IRS2_DC.revB2/IRS2_DC.revB2.4.SLDASM
mechanical-designs/board-stack/IRS2_DC.revB2/IRS2_DC.revB2.SLDPRT
mechanical-designs/board-stack/IRS2_DC.revB2/IRS2_DC.revB2.heatsink.SLDPRT
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

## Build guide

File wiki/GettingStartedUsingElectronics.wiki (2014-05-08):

#summary A quick how-to for getting started running the electronics
#labels Featured

<wiki:toc max_depth="2" />

=prerequisites=

==a boardstack==
A "front-end" module.

==a power supply==
You need to provide DC3V, DC4V and DC5V to the boardstack.

For the carrier02 revD version of the boardstack (one SCROD, one interconnect, one carrier02), the power-on current requirements are as follows:
  * 2.90V@0.241A
  * 3.85V@0.029A (with 0 fiber transceivers installed)
  * 5.60V@0.616A
After FPGA configuration, the current draw should become:
  * 2.90V@0.836A
  * 3.85V@0.059A (with 0 fiber transceivers installed)
  * 5.60V@0.006A
After running the initialization scripts, the current draw should change to (preliminary!):
  * 2.90V@1.250A
  * 3.85V@0.216A (with 1 fiber transceiver installed)
  * 5.60V@0.616A

[https://www.phys.hawaii.edu/elog/iTOP-IRS3/172 elog entry #172 detailing one measurement of these currents for a full boardstack]

==a computer==
Either with USB or fiber optics (SFP).

==an JTAG programmer==
Both the xilinx "platform cable usb II" and the digilent "HS1" have been used successfully.

==an FTSW (optional)==
This clock/trigger distribution module is optional.  Local clocking and software triggers can be used instead.

==a COPPER crate and COPPER board with processor board (optional)==
These are optional.  USB can be used instead of this.

=get and compile the code=
{{{
svn checkout http://idlab-scrod.googlecode.com/svn/SCROD-boardstack/iTOP
}}}

==firmware==
The firmware is located in the "IRS3B_CRT" subdirectory of the above repository.  Xilinx ISE 13.2 has been used to successfully compile the firmware.  You will have to "regenerate cores" for each of the xco files in the ip_cores directory.  Alternately, there is a bitfile in the "usbInterfaces" subfolder along with the readout software.

==software==
The usb software is located in the "usbInterface" subdirectory of the above repository.  The fiber optic readout software is on the UH belleII repository (username required).  Both can compile and run under linux.  There is a README file in the root of the software repository to help you set up your build environment and compile the software.

=testing=
There are many things to test.  This section will be updated with more details and a pointer to some preliminary code.

=more details=
  * [http://www.phys.hawaii.edu/~kurtisn/doku.php?id=itop:documentation:data_format details on data packet format from front-end to back-end (for DAQwriters)]
  * [http://www.phys.hawaii.edu/~mza/PCB/index.html schematics, layouts and gerber files for all PCBs]

=previous versions of documentation=
Only a subset of this is still relevant:
  * [HowToUseFrontEndElectronics Fermilab-era version of this documentation that corresponds to the 2011 boardstack]
  * [http://idlab-scrod.googlecode.com/files/2011-10-16.BelleII-bPID.electronics-documentation.pdf pdf with more detail on the Fermilab-era boardstack]
  * [http://code.google.com/p/idlab-daq/wiki/HowToUseDAQSystem instructions on using the data acquisition system from 2011]

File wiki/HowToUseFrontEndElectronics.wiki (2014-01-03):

#summary How to use the 2011 cosmic / beam test bPID/iTOP electronics
#labels Deprecated

=Introduction=

A thorough description of the electronics and system for 2011 cosmic / beam test is available here:  [http://code.google.com/p/idlab-scrod/wiki/BelleIIbPIDElectronicsDocumentation Belle II bPID electronics documentation]

=Hardware=

A hardware setup guide is now available here: [http://idlab-scrod.googlecode.com/files/bPID_Electronics_Setup.pdf Hardware Setup Guide]

===board stack===

A board stack consists of a SCROD, an interconnect board, four ASIC carrier boards, 16 ASIC daughtercards, a front-back board, a front-front board and an SL10_HV board.

===SCROD===

SCROD is the controller of the board stack.  It has an FPGA and connectors for communication to other boards.

===ASIC daughtercards===

The ASIC that will be used for the 2011 cosmic / beam test is the IRS2.  The daughtercards on which the ASICs sit is called the IRS2_DC revB.  That board has 8 amplifiers (one for each ASIC input channel) and 16 DAC channels to control various aspects of the ASICs' functionality.

===power===

A fully populated board stack requires 4V @ 6A through a 4 pin molex connector.

=FPGA firmware=

===subversion repository===

If you want to keep up-to-date on the firmware or build it yourself, you need to checkout a copy of the subversion repository.  The following are command-line instructions on how to do so:

{{{
mkdir idlab-scrod
cd idlab-scrod
svn checkout http://idlab-scrod.googlecode.com/svn/iTOP-BLAB3A-boardstack/branches
}}}

The main .xise project file is in "idlab-scrod/branches/beam_test_or_bust/ise-project/" and is called, "beam_test_or_bust.xise".

Some .xco files must be re-added to the project after opening it in Xilinx ISE (they are in "idlab-scrod/branches/beam_test_or_bust/ise-project/ipcore_dir/" and "idlab-scrod/branches/pseudo-data_by_fiber/ise-project/ipcore_dir/"), and "ip cores" must be regenerated or the compilation will fail.

All current code (for 2011 beam-test) lies in "branches/beam_test_or_bust" and "branches/pseudo-data_by_fiber".

To keep up-to-date with the latest changes, run the following from the "idlab-scrod/branches" directory:
{{{
svn update
}}}

After running "svn update", you must recompile the project (although .xco files need not be re-added and ip cores need not be regenerated).

===JTAG programmer===

A JTAG programmer is used to send a program to the FPGA on SCROD.  Before this is done, the FPGA does not perform any useful functions.

===IMPACT===

IMPACT is a Xilinx ISE / Xilinx Labtools program to send a .bit file to an FPGA.

===Chipscope===

Chipscope is a Xilinx ISE / Xilinx Labtools program to allow communication with the internal workings of the FPGA in real-time while the FPGA program is active.

=DAQ=

See [http://code.google.com/p/idlab-daq/wiki/HowToUseDAQSystem HowToUseDAQSystem] for information on how to gather data from a front-end electronics module.

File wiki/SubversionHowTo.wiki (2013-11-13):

#summary A short how-to for svn access from the command-line
#labels Featured

=basic usage=

===adding files===
To add a file to the repository, type the following:
{{{
svn add src/my_new_file.vhdl
}}}
Then make sure it hasn't added anything crazy (like a bunch of unwanted output files) with:
{{{
svn status
}}}
Which should output a line that's:
{{{
A src/my_new_file.vhdl
}}}
among a bunch of
{{{
? blah1
? blah2
}}}
lines that indicate you haven't told it what to do with those other files yet (which is fine).

===committing files (the most common command)===
Once you're happy with the content of a file you want to put in the repository (whether you've committed that file before or not), commit the change with the following:
{{{
svn commit -m "initial add of some vhdl that counts pulses coming out of the zargblaster ASIC"
}}}
with whatever comment text you like (-m is for comment), even if it's an empty string.  It might ask you for your googlecode.com password at this point if you haven't entered it before.  Note that you must perform the "svn add" command on that file before it will allow you to commit it.

===trunk checkout===
If you want to checkout the latest and greatest copy of the code (the so-called "trunk" version), this is the command to use:
{{{
svn checkout https://idlab-scrod.googlecode.com/svn/iTOP-BLAB3A-boardstack/trunk/ idlab-scrod --username username@gmail.com
}}}
replacing the given username with your own.  More instructions are at http://code.google.com/p/idlab-scrod/source/checkout (including how to get your google code password, which only seems necessary once and only when you first try to commit something to the repository).

=advanced usage=

===exporting===
If you just want a copy of the files to zip up and put on the blog or email to someone, this is the way to do it:
{{{
svn export https://idlab-scrod.googlecode.com/svn/iTOP-BLAB3A-boardstack/trunk/ idlab-scrod
}}}
Which will make a dir in the current dir called "idlab-scrod" or whatever you put at the end there and then you can do what you like with it (with the benefit being you don't have to post/transfer 70MB zip files anymore).

===trunk on the web===
You can see the latest version of the code that's in the repository here on the web with a cutsie interface:
http://code.google.com/p/idlab-scrod/source/browse/iTOP-BLAB3A-boardstack/trunk
There are links at the top to get elsewhere in the repository (like other subprojects or the wiki files).

===branches===
To be distinguished from the "trunk" version are "branches."  These are for allowing experimental or partially working code to be committed without disturbing the other users of the repository.  Examples would be the "USB tester" version that User#1 made, the "blinkenlights" version that User#2 made or the "16x ASICs" version that User#3 made.  After those versions compile and nominally work or the test / side-project is completed, the code from those branches can be "merged" with the main "trunk" line of development if desired.

===whole repository checkout===
To get the whole repository (including the wiki, the trunk, all branches and tags), give this command:
{{{
svn checkout https://idlab-scrod.googlecode.com/svn/ idlab-scrod --username username@gmail.com
}}}
replacing "username" with your own google username.  Note that this is just the regular "trunk" checkout command, but with a slightly shorter URL because it's a parent of a parent directory.

==="downloads" on the web===
I uploaded useful bit files that have been generated for this project into the "downloads" section of the website:
http://code.google.com/p/idlab-scrod/downloads/list
so that they don't clutter up the repository.

===ignoring files===
For the files that don't belong in the repository that show up with an annoying "? filename" anytime you do a svn commit or svn status command, you can tell it to ignore them in the future with the following command:
{{{
svn propset svn:ignore "*" ise-project/
}}}
Which ignore all files not specifically added to the repository in that directory (it acts recursively).
To add specific files/directories, they must be listed one file or filespec per line (on the command-line, do this with ctrl-enter):
{{{
svn propset svn:ignore "work
bin
mypackets
logdir
" .
}}}

===copying files===
To resurrect a "dead" file from an earlier version of the repository, do the following:
{{{
svn copy -r 344 boardstack-v2-with-SCROD-revA2.ucf .
}}}
It can also be from a different location in the current revision of the repo.

===making a tag===
To make a reference to a useful previous state of the repository (called a "tag"), use the svn copy function:
{{{
svn mkdir tags
cd tags
svn mkdir r282.iTOP-module-used-at-LEPS-SPRING8/
cd r282.iTOP-module-used-at-LEPS-SPRING8/
svn copy -r 282 ../../board-stack/ ../../common-components/ .
}}}

===changing permissions===
To remove the executable permission from a file in the repository, do this:
{{{
svn propdel svn:executable src/read_CAMAC.c 
}}}

To set the executable permission on a script that you want to run, do this:
{{{
svn propset svn:executable yes irs3b-dac-defaults-2714.py
}}}

===reintegrating a branch into the trunk===

Once you have something you like in a branch of the svn, you can reintegrate it into the trunk as follows:
  # First do a dry run to make sure that it's going to do what you expect:
{{{
svn merge --reintegrate --dry-run https://idlab-scrod.googlecode.com/svn/iTOP-BLAB3A-boardstack/branches/one-shot-4windows
}}}
  # Then do the reintegration on your local machine:
{{{
svn merge --reintegrate https://idlab-scrod.googlecode.com/svn/iTOP-BLAB3A-boardstack/branches/one-shot-4windows
}}}
  # Then commit it with the usual command:
{{{
svn commit -m "Changed the trunk to reflect the current \"best\" version."
}}}
  # Assuming that's all been successful, you can delete the branch you were working on:
{{{
svn delete https://idlab-scrod.googlecode.com/svn/iTOP-BLAB3A-boardstack/branches/one-shot-4windows -m "Deleted one-shot 4 windows version since it has been merged into trunk."
}}}

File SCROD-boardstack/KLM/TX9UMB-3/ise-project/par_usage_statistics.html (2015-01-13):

Par Statistics

Total Non-vccgnd Signals=21095

Total Non-vccgnd Design Pins=63866

Total Non-vccgnd Conns=63866

Total Non-vccgnd Timing Constrained Conns=59349

Phase 1 CPU=22.4 sec

Phase 2 CPU=31.3 sec

Phase 3 CPU=109.1 sec

Phase 4 CPU=118.8 sec

Phase 5 CPU=234.3 sec

Phase 6 CPU=234.3 sec

Phase 7 CPU=234.3 sec

Phase 8 CPU=234.3 sec

Phase 9 CPU=235.9 sec

Phase 10 CPU=240.3 sec

AvgWirelenPerPin Fanout 1=4.0

AvgWirelenPerPin Fanout 2=3.5

AvgWirelenPerPin Fanout 3=9.0

AvgWirelenPerPin Fanout 4=5.5

AvgWirelenPerPin Fanout 10=5.4

AvgWirelenPerPin Fanout 50=5.8

AvgWirelenPerPin Fanout 100=16.4

AvgWirelenPerPin Fanout 500=10.7

AvgWirelenPerPin Fanout 5000=7.5

AvgWirelenPerPin Fanout 20000=0.0

AvgWirelenPerPin Fanout 50000=0.0

AvgWirelenPerPin Fanout 100000=0.0

IRR Gamma=2.8157

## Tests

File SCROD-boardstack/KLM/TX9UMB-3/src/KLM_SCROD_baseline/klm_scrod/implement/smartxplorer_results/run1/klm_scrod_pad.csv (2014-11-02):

#Release 14.6 - par P.68d (nt64)
#Copyright (c) 1995-2013 Xilinx | Inc. All rights reserved.
#Sun Oct 12 20:32:02 2014
#
## NOTE: This file is designed to be imported into a spreadsheet program
# such as Microsoft Excel for viewing | printing and sorting. The
# character is used as the data field separator. This file is also designed
# to support parsing.
#
#INPUT FILE: klm_scrod_map.ncd
#OUTPUT FILE: klm_scrod_pad.csv
#PART TYPE: xc6slx150t
#SPEED GRADE: -3
#PACKAGE: fgg676
#
# Pinout by Pin Number:
#
# ----- | ----- | ----- | ----- | ----- | ----- | ----- | ----- | ----- | ----- | ----- | ----- | ----- | ----- | -----
Pin Number | Signal Name | Pin Usage | Pin Name | Direction | IO Standard | IO Bank Number | Drive (mA) | Slew Rate | Termination | IOB Delay | Voltage | Constraint | IO Register | Signal Integrity
A1 |  |  | GND
A2 |  | IOBS | IO_L14N_0 | UNUSED |  | 0
A3 |  | IOBM | IO_L14P_0 | UNUSED |  | 0
A4 |  | IOBS | IO_L22N_0 | UNUSED |  | 0
A5 | mgttxfault<2> | IOB | IO_L24N_0 | INPUT | LVCMOS33 | 0 |  |  |  | NONE |  | LOCATED | YES | NONE
A6 | mgttxn | OPAD | MGTTXN0_101 | OUTPUT |  |  |  |  |  |  |  | UNLOCATED | NO | NONE
A7 |  |  | MGTAVTTTX_101
A8 |  | OPAD | MGTTXN1_101 | UNUSED
A9 |  |  | GND
A10 |  | IPAD | MGTREFCLK0N_101 | UNUSED
A11 |  |  | GND
A12 |  | IOBS | IO_L36N_GCLK14_0 | UNUSED |  | 0
A13 | mgtmod0<1> | IOB | IO_L35N_GCLK16_0 | INPUT | LVCMOS33 | 0 |  |  |  | NONE |  | LOCATED | YES | NONE
A14 | mgtmod2<2> | IOB | IO_L37N_GCLK12_0 | OUTPUT | LVCMOS33 | 0 | 12 | SLOW |  |  |  | LOCATED | NO | NONE
A15 |  |  | GND
A16 |  | IPAD | MGTREFCLK1N_123 | UNUSED
A17 |  |  | GND
A18 |  | OPAD | MGTTXN0_123 | UNUSED
A19 |  |  | MGTAVTTTX_123
A20 |  | OPAD | MGTTXN1_123 | UNUSED
A21 |  |  | GND
A22 |  | IOBS | IO_L63N_SCP6_0 | UNUSED |  | 0
A23 |  | IOBS | IO_L65N_SCP2_0 | UNUSED |  | 0
A24 |  |  | TCK
A25 |  | IOBS | IO_L2N_M5A14_5 | UNUSED |  | 5
A26 |  |  | GND
AA1 |  | IOBS | IO_L36N_M3DQ9_3 | UNUSED |  | 3
AA2 |  | IOBM | IO_L36P_M3DQ8_3 | UNUSED |  | 3
AA3 |  | IOBS | IO_L2N_3 | UNUSED |  | 3
AA4 |  | IOBM | IO_L2P_3 | UNUSED |  | 3
AA5 |  |  | VCCAUX |  |  |  |  |  |  |  | 2.5
AA6 | target_tb<3><2> | IOB | IO_L64N_D9_2 | INPUT | LVCMOS25* | 2 |  |  |  | NONE |  | LOCATED | NO | NONE
AA7 | target_tb<4><2> | IOB | IO_L64P_D8_2 | INPUT | LVCMOS25* | 2 |  |  |  | NONE |  | LOCATED | NO | NONE
AA8 |  | IOBS | IO_L52N_2 | UNUSED |  | 2
AA9 |  | IOBM | IO_L47P_2 | UNUSED |  | 2
AA10 |  | IOBM | IO_L48P_D7_2 | UNUSED |  | 2
AA11 |  | IOBS | IO_L41N_VREF_2 | UNUSED |  | 2
AA12 | target_tb<3><1> | IOB | IO_L33N_2 | INPUT | LVCMOS25* | 2 |  |  |  | NONE |  | LOCATED | NO | NONE
AA13 |  | IOBS | IO_L36N_2 | UNUSED |  | 2
AA14 |  |  | VCCO_2 |  |  | 2 |  |  |  |  | 2.50
AA15 | target_tb16<7> | IOB | IO_L28P_2 | INPUT | LVCMOS25* | 2 |  |  |  | NONE |  | LOCATED | NO | NONE
AA16 |  | IOBS | IO_L24N_VREF_2 | UNUSED |  | 2
AA17 | target_tb<8><5> | IOB | IO_L16N_VREF_2 | INPUT | LVCMOS25* | 2 |  |  |  | NONE |  | LOCATED | NO | NONE
AA18 |  | IOBM | IO_L20P_2 | UNUSED |  | 2
AA19 |  | IOBM | IO_L18P_2 | UNUSED |  | 2
AA20 |  |  | VCCO_2 |  |  | 2 |  |  |  |  | 2.50
AA21 |  | IOBM | IO_L15P_2 | UNUSED |  | 2
AA22 | target_tb<8><1> | IOB | IO_L2N_CMPMOSI_2 | INPUT | LVCMOS25* | 2 |  |  |  | NONE |  | LOCATED | NO | NONE
AA23 |  | IOBM | IO_L67P_1 | UNUSED |  | 1
AA24 |  | IOBS | IO_L67N_1 | UNUSED |  | 1
AA25 |  | IOBM | IO_L47P_FWE_B_M1DQ0_1 | UNUSED |  | 1
AA26 |  | IOBS | IO_L47N_LDC_M1DQ1_1 | UNUSED |  | 1
AB1 |  | IOBS | IO_L32N_M3DQ15_3 | UNUSED |  | 3
AB2 |  |  | GND
AB3 |  | IOBM | IO_L32P_M3DQ14_3 | UNUSED |  | 3
AB4 |  | IOBM | IO_L8P_3 | UNUSED |  | 3
AB5 |  | IOBM | IO_L1P_3 | UNUSED |  | 3
AB6 |  |  | VCCO_2 |  |  | 2 |  |  |  |  | 2.50
AB7 |  | IOBM | IO_L53P_2 | UNUSED |  | 2
AB8 |  |  | VCCAUX |  |  |  |  |  |  |  | 2.5
AB9 |  | IOBS | IO_L47N_2 | UNUSED |  | 2
AB10 |  |  | MGTRREF_245
AB11 |  | IOBS | IO_L48N_RDWR_B_VREF_2 | UNUSED |  | 2
AB12 |  |  | MGTAVTTRCAL_245
AB13 |  | IOBM | IO_L36P_2 | UNUSED |  | 2
AB14 | ttdtrgp | IOB | IO_L30P_GCLK1_D13_2 | INPUT | LVDS_25 | 2 |  |  |  | NONE |  | LOCATED | YES | DIFF_TERM
AB15 |  | IOBS | IO_L28N_2 | UNUSED |  | 2
AB16 |  |  | GND
AB17 |  | IOBS | IO_L20N_2 | UNUSED |  | 2
AB18 |  |  | VCCAUX |  |  |  |  |  |  |  | 2.5
AB19 |  | IOBS | IO_L18N_2 | UNUSED |  | 2
AB20 |  |  | GND
AB21 | target_tb16<8> | IOB | IO_L15N_2 | INPUT | LVCMOS25* | 2 |  |  |  | NONE |  | LOCATED | NO | NONE
AB22 |  | IOBM | IO_L5P_2 | UNUSED |  | 2
AB23 |  |  | VCCO_1 |  |  | 1 |  |  |  |  | any******
AB24 |  | IOBM | IO_L49P_M1DQ10_1 | UNUSED |  | 1
AB25 |  |  | GND
AB26 |  | IOBS | IO_L49N_M1DQ11_1 | UNUSED |  | 1
AC1 |  | IOBS | IO_L34N_M3UDQSN_3 | UNUSED |  | 3
AC2 |  | IOBM | IO_L34P_M3UDQS_3 | UNUSED |  | 3
AC3 |  | IOBS | IO_L8N_3 | UNUSED |  | 3
AC4 |  | IOBS | IO_L1N_VREF_3 | UNUSED |  | 3
AC5 |  | IOBM | IO_L61P_2 | UNUSED |  | 2
AC6 |  | IOBS | IO_L53N_2 | UNUSED |  | 2
AC7 |  |  | VCCAUX |  |  |  |  |  |  |  | 2.5
AC8 |  | IPAD | MGTRXP0_245 | UNUSED
AC9 |  |  | MGTAVTTRX_245
AC10 |  | IPAD | MGTRXP1_245 | UNUSED
AC11 |  |  | GND
AC12 |  | IPAD | MGTREFCLK1P_245 | UNUSED
AC13 |  |  | GND
AC14 | ttdtrgn | IOB | IO_L30N_GCLK0_USERCCLK_2 |  | LVDS_25 | 2 |  |  |  |  |  | LOCATED | NO | DIFF_TERM
AC15 |  |  | GND
AC16 |  | IPAD | MGTREFCLK0P_267 | UNUSED
AC17 |  |  | GND
AC18 |  | IPAD | MGTRXP0_267 | UNUSED
AC19 |  |  | MGTAVTTRX_267
AC20 |  | IPAD | MGTRXP1_267 | UNUSED
AC21 |  |  | VCCAUX |  |  |  |  |  |  |  | 2.5
AC22 | target_tb<8><3> | IOB | IO_L5N_2 | INPUT | LVCMOS25* | 2 |  |  |  | NONE |  | LOCATED | NO | NONE
AC23 |  | IOBM | IO_L74P_AWAKE_1 | UNUSED |  | 1
AC24 |  | IOBS | IO_L74N_DOUT_BUSY_1 | UNUSED |  | 1
AC25 |  | IOBM | IO_L50P_M1UDQS_1 | UNUSED |  | 1
AC26 | target_tb<6><5> | IOB | IO_L50N_M1UDQSN_1 | INPUT | LVCMOS25* | 1 |  |  |  | NONE |  | LOCATED | NO | NONE
AD1 |  | IOBS | IO_L33N_M3DQ13_3 | UNUSED |  | 3
AD2 |  |  | VCCO_3 |  |  | 3 |  |  |  |  | any******
AD3 |  | IOBM | IO_L33P_M3DQ12_3 | UNUSED |  | 3
AD4 | target_tb16<2> | IOB | IO_L63P_2 | INPUT | LVCMOS25* | 2 |  |  |  | NONE |  | LOCATED | NO | NONE
AD5 |  | IOBS | IO_L61N_VREF_2 | UNUSED |  | 2
AD6 |  | IOBM | IO_L49P_D3_2 | UNUSED |  | 2
AD7 |  |  | GND
AD8 |  | IPAD | MGTRXN0_245 | UNUSED
AD9 |  |  | GND
AD10 |  | IPAD | MGTRXN1_245 | UNUSED
AD11 |  |  | MGTAVCC_245
AD12 |  | IPAD | MGTREFCLK1N_245 | UNUSED
AD13 |  |  | MGTAVCCPLL1_245
AD14 | ttdackp | IOBM | IO_L32P_GCLK29_2 | TRISTATE | LVDS_25 | 2 |  |  |  |  |  | LOCATED | YES | NONE
AD15 |  |  | MGTAVCCPLL0_267
AD16 |  | IPAD | MGTREFCLK0N_267 | UNUSED
AD17 |  |  | MGTAVCC_267
AD18 |  | IPAD | MGTRXN0_267 | UNUSED
AD19 |  |  | GND
AD20 |  | IPAD | MGTRXN1_267 | UNUSED
AD21 |  |  | GND
AD22 |  | IOBM | IO_L13P_M1_2 | UNUSED |  | 2
AD23 |  | IOBM | IO_L3P_D0_DIN_MISO_MISO1_2 | UNUSED |  | 2
AD24 |  | IOBM | IO_L48P_HDC_M1DQ8_1 | UNUSED |  | 1
AD25 |  |  | VCCO_1 |  |  | 1 |  |  |  |  | any******
AD26 | target_tb16<6> | IOB | IO_L48N_M1DQ9_1 | INPUT | LVCMOS25* | 1 |  |  |  | NONE |  | LOCATED | NO | NONE
AE1 |  | IOBS | IO_L35N_M3DQ11_3 | UNUSED |  | 3
AE2 |  | IOBM | IO_L35P_M3DQ10_3 | UNUSED |  | 3
AE3 |  | IOBM | IO_L65P_INIT_B_2 | UNUSED |  | 2
AE4 |  |  | VCCO_2 |  |  | 2 |  |  |  |  | 2.50
AE5 |  | IOBM | IO_L51P_2 | UNUSED |  | 2
AE6 |  |  | GND
AE7 |  | OPAD | MGTTXP0_245 | UNUSED
AE8 |  |  | GND
AE9 |  | OPAD | MGTTXP1_245 | UNUSED
AE10 |  |  | GND
AE11 |  | IPAD | MGTREFCLK0P_245 | UNUSED
AE12 |  |  | MGTAVCCPLL0_245
AE13 | ttdclkp | IOB | IO_L31P_GCLK31_D14_2 | INPUT | LVDS_25 | 2 |  |  |  | NONE |  | LOCATED | NO | DIFF_TERM
AE14 |  |  | VCCO_2 |  |  | 2 |  |  |  |  | 2.50
AE15 | ttdrsvp | IOB | IO_L29P_GCLK3_2 | OUTPUT | LVCMOS25* | 2 | 12 | SLOW |  |  |  | LOCATED | NO | NONE
AE16 |  |  | MGTAVCCPLL1_267
AE17 |  | IPAD | MGTREFCLK1P_267 | UNUSED
AE18 |  |  | GND
AE19 |  | OPAD | MGTTXP0_267 | UNUSED
AE20 |  |  | GND
AE21 |  | OPAD | MGTTXP1_267 | UNUSED
AE22 |  |  | GND
AE23 |  |  | VCCO_2 |  |  | 2 |  |  |  |  | 2.50
AE24 |  | IOBM | IO_L1P_CCLK_2 | UNUSED |  | 2
AE25 | target_tb<6><3> | IOB | IO_L52P_M1DQ14_1 | INPUT | LVCMOS25* | 1 |  |  |  | NONE |  | LOCATED | NO | NONE
AE26 | target_tb<6><4> | IOB | IO_L52N_M1DQ15_1 | INPUT | LVCMOS25* | 1 |  |  |  | NONE |  | LOCATED | NO | NONE
AF1 |  |  | GND
AF2 |  |  | PROGRAM_B_2
AF3 |  | IOBS | IO_L65N_CSO_B_2 | UNUSED |  | 2
AF4 |  | IOBS | IO_L63N_2 | UNUSED |  | 2
AF5 |  | IOBS | IO_L51N_2 | UNUSED |  | 2
AF6 |  | IOBS | IO_L49N_D4_2 | UNUSED |  | 2
AF7 |  | OPAD | MGTTXN0_245 | UNUSED
AF8 |  |  | MGTAVTTTX_245
AF9 |  | OPAD | MGTTXN1_245 | UNUSED
AF10 |  |  | GND
AF11 |  | IPAD | MGTREFCLK0N_245 | UNUSED
AF12 |  |  | GND
AF13 | ttdclkn | IOB | IO_L31N_GCLK30_D15_2 |  | LVDS_25 | 2 |  |  |  |  |  | LOCATED | NO | DIFF_TERM
AF14 | ttdackn | IOBS | IO_L32N_GCLK28_2 |  | LVDS_25 | 2 |  |  |  |  |  | LOCATED | NO
AF15 | ttdrsvn | IOB | IO_L29N_GCLK2_2 | OUTPUT | LVCMOS25* | 2 | 12 | SLOW |  |  |  | LOCATED | NO | NONE
AF16 |  |  | GND
AF17 |  | IPAD | MGTREFCLK1N_267 | UNUSED
AF18 |  |  | GND
AF19 |  | OPAD | MGTTXN0_267 | UNUSED
AF20 |  |  | MGTAVTTTX_267
AF21 |  | OPAD | MGTTXN1_267 | UNUSED
AF22 |  | IOBS | IO_L13N_D10_2 | UNUSED |  | 2
AF23 |  | IOBS | IO_L3N_MOSI_CSI_B_MISO0_2 | UNUSED |  | 2
AF24 |  | IOBS | IO_L1N_M0_CMPMISO_2 | UNUSED |  | 2
AF25 |  |  | DONE_2
AF26 |  |  | GND
B1 |  | IOBS | IO_L75N_M4BA1_4 | UNUSED |  | 4
B2 |  | IOBM | IO_L75P_M4BA0_4 | UNUSED |  | 4
B3 |  | IOBS | IO_L4N_0 | UNUSED |  | 0
B4 |  | IOBM | IO_L22P_0 | UNUSED |  | 0
B5 | mgtlos<1> | IOB | IO_L24P_0 | INPUT | LVCMOS33 | 0 |  |  |  | NONE |  | LOCATED | YES | NONE
B6 | mgttxp | OPAD | MGTTXP0_101 | OUTPUT |  |  |  |  |  |  |  | UNLOCATED | NO | NONE
B7 |  |  | GND
B8 |  | OPAD | MGTTXP1_101 | UNUSED
B9 |  |  | GND
B10 |  | IPAD | MGTREFCLK0P_101 | UNUSED
B11 |  |  | MGTAVCCPLL0_101
B12 |  | IOBM | IO_L36P_GCLK15_0 | UNUSED |  | 0
B13 |  |  | VCCO_0 |  |  | 0 |  |  |  |  | 3.30
B14 |  | IOBM | IO_L37P_GCLK13_0 | UNUSED |  | 0
B15 |  |  | MGTAVCCPLL1_123
B16 |  | IPAD | MGTREFCLK1P_123 | UNUSED
B17 |  |  | GND
B18 |  | OPAD | MGTTXP0_123 | UNUSED
B19 |  |  | GND
B20 |  | OPAD | MGTTXP1_123 | UNUSED
B21 |  | IOBS | IO_L59N_0 | UNUSED |  | 0
B22 |  | IOBM | IO_L63P_SCP7_0 | UNUSED |  | 0
B23 |  | IOBM | IO_L65P_SCP3_0 | UNUSED |  | 0
B24 |  | IOBM | IO_L2P_M5A13_5 | UNUSED |  | 5
B25 |  | IOBM | IO_L11P_M5CLK_5 | UNUSED |  | 5
B26 |  | IOBS | IO_L11N_M5CLKN_5 | UNUSED |  | 5
C1 | target_tb<2><2> | IOB | IO_L79N_M4A9_4 | INPUT | LVCMOS25* | 4 |  |  |  | NONE |  | LOCATED | NO | NONE
C2 | target_tb<2><1> | IOB | IO_L79P_M4A8_4 | INPUT | LVCMOS25* | 4 |  |  |  | NONE |  | LOCATED | NO | NONE
C3 |  | IOBM | IO_L4P_0 | UNUSED |  | 0
C4 |  |  | VCCO_0 |  |  | 0 |  |  |  |  | 3.30
C5 |  | IOBS | IO_L16N_0 | UNUSED |  | 0
C6 |  |  | GND
C7 | mgtrxn | IPAD | MGTRXN0_101 | INPUT |  |  |  |  |  | NONE |  | UNLOCATED | NO | NONE
C8 |  |  | GND
C9 |  | IPAD | MGTRXN1_101 | UNUSED
C10 |  |  | MGTAVCC_101
C11 |  | IPAD | MGTREFCLK1N_101 | UNUSED
C12 |  |  | MGTAVCCPLL1_101
C13 | mgtmod1<1> | IOB | IO_L35P_GCLK17_0 | OUTPUT | LVCMOS33 | 0 | 12 | SLOW |  |  |  | LOCATED | NO | NONE
C14 |  |  | MGTAVCCPLL0_123
C15 |  | IPAD | MGTREFCLK0N_123 | UNUSED
C16 |  |  | MGTAVCC_123
C17 |  | IPAD | MGTRXN0_123 | UNUSED
C18 |  |  | GND
C19 |  | IPAD | MGTRXN1_123 | UNUSED
C20 |  |  | GND
C21 |  | IOBM | IO_L59P_0 | UNUSED |  | 0
C22 |  |  | VCCO_0 |  |  | 0 |  |  |  |  | 3.30
C23 |  |  | TDI
C24 | target_tb<6><2> | IOB | IO_L4N_M5A12_5 | INPUT | LVCMOS25* | 5 |  |  |  | NONE |  | LOCATED | NO | NONE
C25 |  | IOBM | IO_L10P_M5A0_5 | UNUSED |  | 5
C26 |  | IOBS | IO_L10N_M5A1_5 | UNUSED |  | 5
D1 |  | IOBS | IO_L68N_M4DQ5_4 | UNUSED |  | 4
D2 |  |  | VCCO_4 |  |  | 4 |  |  |  |  | any******
D3 |  | IOBM | IO_L68P_M4DQ4_4 | UNUSED |  | 4
D4 |  |  | GND
D5 |  | IOBM | IO_L16P_0 | UNUSED |  | 0
D6 |  |  | VCCAUX |  |  |  |  |  |  |  | 2.5
D7 | mgtrxp | IPAD | MGTRXP0_101 | INPUT |  |  |  |  |  | NONE |  | UNLOCATED | NO | NONE
D8 |  |  | MGTAVTTRX_101
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

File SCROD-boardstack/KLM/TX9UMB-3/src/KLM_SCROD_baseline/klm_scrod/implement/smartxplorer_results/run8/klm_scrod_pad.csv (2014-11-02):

#Release 14.6 - par P.68d (nt64)
#Copyright (c) 1995-2013 Xilinx | Inc. All rights reserved.
#Sun Oct 12 20:35:14 2014
#
## NOTE: This file is designed to be imported into a spreadsheet program
# such as Microsoft Excel for viewing | printing and sorting. The
# character is used as the data field separator. This file is also designed
# to support parsing.
#
#INPUT FILE: klm_scrod_map.ncd
#OUTPUT FILE: klm_scrod_pad.csv
#PART TYPE: xc6slx150t
#SPEED GRADE: -3
#PACKAGE: fgg676
#
# Pinout by Pin Number:
#
# ----- | ----- | ----- | ----- | ----- | ----- | ----- | ----- | ----- | ----- | ----- | ----- | ----- | ----- | -----
Pin Number | Signal Name | Pin Usage | Pin Name | Direction | IO Standard | IO Bank Number | Drive (mA) | Slew Rate | Termination | IOB Delay | Voltage | Constraint | IO Register | Signal Integrity
A1 |  |  | GND
A2 |  | IOBS | IO_L14N_0 | UNUSED |  | 0
A3 |  | IOBM | IO_L14P_0 | UNUSED |  | 0
A4 |  | IOBS | IO_L22N_0 | UNUSED |  | 0
A5 | mgttxfault<2> | IOB | IO_L24N_0 | INPUT | LVCMOS33 | 0 |  |  |  | NONE |  | LOCATED | YES | NONE
A6 | mgttxn | OPAD | MGTTXN0_101 | OUTPUT |  |  |  |  |  |  |  | UNLOCATED | NO | NONE
A7 |  |  | MGTAVTTTX_101
A8 |  | OPAD | MGTTXN1_101 | UNUSED
A9 |  |  | GND
A10 |  | IPAD | MGTREFCLK0N_101 | UNUSED
A11 |  |  | GND
A12 |  | IOBS | IO_L36N_GCLK14_0 | UNUSED |  | 0
A13 | mgtmod0<1> | IOB | IO_L35N_GCLK16_0 | INPUT | LVCMOS33 | 0 |  |  |  | NONE |  | LOCATED | YES | NONE
A14 | mgtmod2<2> | IOB | IO_L37N_GCLK12_0 | OUTPUT | LVCMOS33 | 0 | 12 | SLOW |  |  |  | LOCATED | NO | NONE
A15 |  |  | GND
A16 |  | IPAD | MGTREFCLK1N_123 | UNUSED
A17 |  |  | GND
A18 |  | OPAD | MGTTXN0_123 | UNUSED
A19 |  |  | MGTAVTTTX_123
A20 |  | OPAD | MGTTXN1_123 | UNUSED
A21 |  |  | GND
A22 |  | IOBS | IO_L63N_SCP6_0 | UNUSED |  | 0
A23 |  | IOBS | IO_L65N_SCP2_0 | UNUSED |  | 0
A24 |  |  | TCK
A25 |  | IOBS | IO_L2N_M5A14_5 | UNUSED |  | 5
A26 |  |  | GND
AA1 |  | IOBS | IO_L36N_M3DQ9_3 | UNUSED |  | 3
AA2 |  | IOBM | IO_L36P_M3DQ8_3 | UNUSED |  | 3
AA3 |  | IOBS | IO_L2N_3 | UNUSED |  | 3
AA4 |  | IOBM | IO_L2P_3 | UNUSED |  | 3
AA5 |  |  | VCCAUX |  |  |  |  |  |  |  | 2.5
AA6 | target_tb<3><2> | IOB | IO_L64N_D9_2 | INPUT | LVCMOS25* | 2 |  |  |  | NONE |  | LOCATED | NO | NONE
AA7 | target_tb<4><2> | IOB | IO_L64P_D8_2 | INPUT | LVCMOS25* | 2 |  |  |  | NONE |  | LOCATED | NO | NONE
AA8 |  | IOBS | IO_L52N_2 | UNUSED |  | 2
AA9 |  | IOBM | IO_L47P_2 | UNUSED |  | 2
AA10 |  | IOBM | IO_L48P_D7_2 | UNUSED |  | 2
AA11 |  | IOBS | IO_L41N_VREF_2 | UNUSED |  | 2
AA12 | target_tb<3><1> | IOB | IO_L33N_2 | INPUT | LVCMOS25* | 2 |  |  |  | NONE |  | LOCATED | NO | NONE
AA13 |  | IOBS | IO_L36N_2 | UNUSED |  | 2
AA14 |  |  | VCCO_2 |  |  | 2 |  |  |  |  | 2.50
AA15 | target_tb16<7> | IOB | IO_L28P_2 | INPUT | LVCMOS25* | 2 |  |  |  | NONE |  | LOCATED | NO | NONE
AA16 |  | IOBS | IO_L24N_VREF_2 | UNUSED |  | 2
AA17 | target_tb<8><5> | IOB | IO_L16N_VREF_2 | INPUT | LVCMOS25* | 2 |  |  |  | NONE |  | LOCATED | NO | NONE
AA18 |  | IOBM | IO_L20P_2 | UNUSED |  | 2
AA19 |  | IOBM | IO_L18P_2 | UNUSED |  | 2
AA20 |  |  | VCCO_2 |  |  | 2 |  |  |  |  | 2.50
AA21 |  | IOBM | IO_L15P_2 | UNUSED |  | 2
AA22 | target_tb<8><1> | IOB | IO_L2N_CMPMOSI_2 | INPUT | LVCMOS25* | 2 |  |  |  | NONE |  | LOCATED | NO | NONE
AA23 |  | IOBM | IO_L67P_1 | UNUSED |  | 1
AA24 |  | IOBS | IO_L67N_1 | UNUSED |  | 1
AA25 |  | IOBM | IO_L47P_FWE_B_M1DQ0_1 | UNUSED |  | 1
AA26 |  | IOBS | IO_L47N_LDC_M1DQ1_1 | UNUSED |  | 1
AB1 |  | IOBS | IO_L32N_M3DQ15_3 | UNUSED |  | 3
AB2 |  |  | GND
AB3 |  | IOBM | IO_L32P_M3DQ14_3 | UNUSED |  | 3
AB4 |  | IOBM | IO_L8P_3 | UNUSED |  | 3
AB5 |  | IOBM | IO_L1P_3 | UNUSED |  | 3
AB6 |  |  | VCCO_2 |  |  | 2 |  |  |  |  | 2.50
AB7 |  | IOBM | IO_L53P_2 | UNUSED |  | 2
AB8 |  |  | VCCAUX |  |  |  |  |  |  |  | 2.5
AB9 |  | IOBS | IO_L47N_2 | UNUSED |  | 2
AB10 |  |  | MGTRREF_245
AB11 |  | IOBS | IO_L48N_RDWR_B_VREF_2 | UNUSED |  | 2
AB12 |  |  | MGTAVTTRCAL_245
AB13 |  | IOBM | IO_L36P_2 | UNUSED |  | 2
AB14 | ttdtrgp | IOB | IO_L30P_GCLK1_D13_2 | INPUT | LVDS_25 | 2 |  |  |  | NONE |  | LOCATED | YES | DIFF_TERM
AB15 |  | IOBS | IO_L28N_2 | UNUSED |  | 2
AB16 |  |  | GND
AB17 |  | IOBS | IO_L20N_2 | UNUSED |  | 2
AB18 |  |  | VCCAUX |  |  |  |  |  |  |  | 2.5
AB19 |  | IOBS | IO_L18N_2 | UNUSED |  | 2
AB20 |  |  | GND
AB21 | target_tb16<8> | IOB | IO_L15N_2 | INPUT | LVCMOS25* | 2 |  |  |  | NONE |  | LOCATED | NO | NONE
AB22 |  | IOBM | IO_L5P_2 | UNUSED |  | 2
AB23 |  |  | VCCO_1 |  |  | 1 |  |  |  |  | any******
AB24 |  | IOBM | IO_L49P_M1DQ10_1 | UNUSED |  | 1
AB25 |  |  | GND
AB26 |  | IOBS | IO_L49N_M1DQ11_1 | UNUSED |  | 1
AC1 |  | IOBS | IO_L34N_M3UDQSN_3 | UNUSED |  | 3
AC2 |  | IOBM | IO_L34P_M3UDQS_3 | UNUSED |  | 3
AC3 |  | IOBS | IO_L8N_3 | UNUSED |  | 3
AC4 |  | IOBS | IO_L1N_VREF_3 | UNUSED |  | 3
AC5 |  | IOBM | IO_L61P_2 | UNUSED |  | 2
AC6 |  | IOBS | IO_L53N_2 | UNUSED |  | 2
AC7 |  |  | VCCAUX |  |  |  |  |  |  |  | 2.5
AC8 |  | IPAD | MGTRXP0_245 | UNUSED
AC9 |  |  | MGTAVTTRX_245
AC10 |  | IPAD | MGTRXP1_245 | UNUSED
AC11 |  |  | GND
AC12 |  | IPAD | MGTREFCLK1P_245 | UNUSED
AC13 |  |  | GND
AC14 | ttdtrgn | IOB | IO_L30N_GCLK0_USERCCLK_2 |  | LVDS_25 | 2 |  |  |  |  |  | LOCATED | NO | DIFF_TERM
AC15 |  |  | GND
AC16 |  | IPAD | MGTREFCLK0P_267 | UNUSED
AC17 |  |  | GND
AC18 |  | IPAD | MGTRXP0_267 | UNUSED
AC19 |  |  | MGTAVTTRX_267
AC20 |  | IPAD | MGTRXP1_267 | UNUSED
AC21 |  |  | VCCAUX |  |  |  |  |  |  |  | 2.5
AC22 | target_tb<8><3> | IOB | IO_L5N_2 | INPUT | LVCMOS25* | 2 |  |  |  | NONE |  | LOCATED | NO | NONE
AC23 |  | IOBM | IO_L74P_AWAKE_1 | UNUSED |  | 1
AC24 |  | IOBS | IO_L74N_DOUT_BUSY_1 | UNUSED |  | 1
AC25 |  | IOBM | IO_L50P_M1UDQS_1 | UNUSED |  | 1
AC26 | target_tb<6><5> | IOB | IO_L50N_M1UDQSN_1 | INPUT | LVCMOS25* | 1 |  |  |  | NONE |  | LOCATED | NO | NONE
AD1 |  | IOBS | IO_L33N_M3DQ13_3 | UNUSED |  | 3
AD2 |  |  | VCCO_3 |  |  | 3 |  |  |  |  | any******
AD3 |  | IOBM | IO_L33P_M3DQ12_3 | UNUSED |  | 3
AD4 | target_tb16<2> | IOB | IO_L63P_2 | INPUT | LVCMOS25* | 2 |  |  |  | NONE |  | LOCATED | NO | NONE
AD5 |  | IOBS | IO_L61N_VREF_2 | UNUSED |  | 2
AD6 |  | IOBM | IO_L49P_D3_2 | UNUSED |  | 2
AD7 |  |  | GND
AD8 |  | IPAD | MGTRXN0_245 | UNUSED
AD9 |  |  | GND
AD10 |  | IPAD | MGTRXN1_245 | UNUSED
AD11 |  |  | MGTAVCC_245
AD12 |  | IPAD | MGTREFCLK1N_245 | UNUSED
AD13 |  |  | MGTAVCCPLL1_245
AD14 | ttdackp | IOBM | IO_L32P_GCLK29_2 | TRISTATE | LVDS_25 | 2 |  |  |  |  |  | LOCATED | YES | NONE
AD15 |  |  | MGTAVCCPLL0_267
AD16 |  | IPAD | MGTREFCLK0N_267 | UNUSED
AD17 |  |  | MGTAVCC_267
AD18 |  | IPAD | MGTRXN0_267 | UNUSED
AD19 |  |  | GND
AD20 |  | IPAD | MGTRXN1_267 | UNUSED
AD21 |  |  | GND
AD22 |  | IOBM | IO_L13P_M1_2 | UNUSED |  | 2
AD23 |  | IOBM | IO_L3P_D0_DIN_MISO_MISO1_2 | UNUSED |  | 2
AD24 |  | IOBM | IO_L48P_HDC_M1DQ8_1 | UNUSED |  | 1
AD25 |  |  | VCCO_1 |  |  | 1 |  |  |  |  | any******
AD26 | target_tb16<6> | IOB | IO_L48N_M1DQ9_1 | INPUT | LVCMOS25* | 1 |  |  |  | NONE |  | LOCATED | NO | NONE
AE1 |  | IOBS | IO_L35N_M3DQ11_3 | UNUSED |  | 3
AE2 |  | IOBM | IO_L35P_M3DQ10_3 | UNUSED |  | 3
AE3 |  | IOBM | IO_L65P_INIT_B_2 | UNUSED |  | 2
AE4 |  |  | VCCO_2 |  |  | 2 |  |  |  |  | 2.50
AE5 |  | IOBM | IO_L51P_2 | UNUSED |  | 2
AE6 |  |  | GND
AE7 |  | OPAD | MGTTXP0_245 | UNUSED
AE8 |  |  | GND
AE9 |  | OPAD | MGTTXP1_245 | UNUSED
AE10 |  |  | GND
AE11 |  | IPAD | MGTREFCLK0P_245 | UNUSED
AE12 |  |  | MGTAVCCPLL0_245
AE13 | ttdclkp | IOB | IO_L31P_GCLK31_D14_2 | INPUT | LVDS_25 | 2 |  |  |  | NONE |  | LOCATED | NO | DIFF_TERM
AE14 |  |  | VCCO_2 |  |  | 2 |  |  |  |  | 2.50
AE15 | ttdrsvp | IOB | IO_L29P_GCLK3_2 | OUTPUT | LVCMOS25* | 2 | 12 | SLOW |  |  |  | LOCATED | NO | NONE
AE16 |  |  | MGTAVCCPLL1_267
AE17 |  | IPAD | MGTREFCLK1P_267 | UNUSED
AE18 |  |  | GND
AE19 |  | OPAD | MGTTXP0_267 | UNUSED
AE20 |  |  | GND
AE21 |  | OPAD | MGTTXP1_267 | UNUSED
AE22 |  |  | GND
AE23 |  |  | VCCO_2 |  |  | 2 |  |  |  |  | 2.50
AE24 |  | IOBM | IO_L1P_CCLK_2 | UNUSED |  | 2
AE25 | target_tb<6><3> | IOB | IO_L52P_M1DQ14_1 | INPUT | LVCMOS25* | 1 |  |  |  | NONE |  | LOCATED | NO | NONE
AE26 | target_tb<6><4> | IOB | IO_L52N_M1DQ15_1 | INPUT | LVCMOS25* | 1 |  |  |  | NONE |  | LOCATED | NO | NONE
AF1 |  |  | GND
AF2 |  |  | PROGRAM_B_2
AF3 |  | IOBS | IO_L65N_CSO_B_2 | UNUSED |  | 2
AF4 |  | IOBS | IO_L63N_2 | UNUSED |  | 2
AF5 |  | IOBS | IO_L51N_2 | UNUSED |  | 2
AF6 |  | IOBS | IO_L49N_D4_2 | UNUSED |  | 2
AF7 |  | OPAD | MGTTXN0_245 | UNUSED
AF8 |  |  | MGTAVTTTX_245
AF9 |  | OPAD | MGTTXN1_245 | UNUSED
AF10 |  |  | GND
AF11 |  | IPAD | MGTREFCLK0N_245 | UNUSED
AF12 |  |  | GND
AF13 | ttdclkn | IOB | IO_L31N_GCLK30_D15_2 |  | LVDS_25 | 2 |  |  |  |  |  | LOCATED | NO | DIFF_TERM
AF14 | ttdackn | IOBS | IO_L32N_GCLK28_2 |  | LVDS_25 | 2 |  |  |  |  |  | LOCATED | NO
AF15 | ttdrsvn | IOB | IO_L29N_GCLK2_2 | OUTPUT | LVCMOS25* | 2 | 12 | SLOW |  |  |  | LOCATED | NO | NONE
AF16 |  |  | GND
AF17 |  | IPAD | MGTREFCLK1N_267 | UNUSED
AF18 |  |  | GND
AF19 |  | OPAD | MGTTXN0_267 | UNUSED
AF20 |  |  | MGTAVTTTX_267
AF21 |  | OPAD | MGTTXN1_267 | UNUSED
AF22 |  | IOBS | IO_L13N_D10_2 | UNUSED |  | 2
AF23 |  | IOBS | IO_L3N_MOSI_CSI_B_MISO0_2 | UNUSED |  | 2
AF24 |  | IOBS | IO_L1N_M0_CMPMISO_2 | UNUSED |  | 2
AF25 |  |  | DONE_2
AF26 |  |  | GND
B1 |  | IOBS | IO_L75N_M4BA1_4 | UNUSED |  | 4
B2 |  | IOBM | IO_L75P_M4BA0_4 | UNUSED |  | 4
B3 |  | IOBS | IO_L4N_0 | UNUSED |  | 0
B4 |  | IOBM | IO_L22P_0 | UNUSED |  | 0
B5 | mgtlos<1> | IOB | IO_L24P_0 | INPUT | LVCMOS33 | 0 |  |  |  | NONE |  | LOCATED | YES | NONE
B6 | mgttxp | OPAD | MGTTXP0_101 | OUTPUT |  |  |  |  |  |  |  | UNLOCATED | NO | NONE
B7 |  |  | GND
B8 |  | OPAD | MGTTXP1_101 | UNUSED
B9 |  |  | GND
B10 |  | IPAD | MGTREFCLK0P_101 | UNUSED
B11 |  |  | MGTAVCCPLL0_101
B12 |  | IOBM | IO_L36P_GCLK15_0 | UNUSED |  | 0
B13 |  |  | VCCO_0 |  |  | 0 |  |  |  |  | 3.30
B14 |  | IOBM | IO_L37P_GCLK13_0 | UNUSED |  | 0
B15 |  |  | MGTAVCCPLL1_123
B16 |  | IPAD | MGTREFCLK1P_123 | UNUSED
B17 |  |  | GND
B18 |  | OPAD | MGTTXP0_123 | UNUSED
B19 |  |  | GND
B20 |  | OPAD | MGTTXP1_123 | UNUSED
B21 |  | IOBS | IO_L59N_0 | UNUSED |  | 0
B22 |  | IOBM | IO_L63P_SCP7_0 | UNUSED |  | 0
B23 |  | IOBM | IO_L65P_SCP3_0 | UNUSED |  | 0
B24 |  | IOBM | IO_L2P_M5A13_5 | UNUSED |  | 5
B25 |  | IOBM | IO_L11P_M5CLK_5 | UNUSED |  | 5
B26 |  | IOBS | IO_L11N_M5CLKN_5 | UNUSED |  | 5
C1 | target_tb<2><2> | IOB | IO_L79N_M4A9_4 | INPUT | LVCMOS25* | 4 |  |  |  | NONE |  | LOCATED | NO | NONE
C2 | target_tb<2><1> | IOB | IO_L79P_M4A8_4 | INPUT | LVCMOS25* | 4 |  |  |  | NONE |  | LOCATED | NO | NONE
C3 |  | IOBM | IO_L4P_0 | UNUSED |  | 0
C4 |  |  | VCCO_0 |  |  | 0 |  |  |  |  | 3.30
C5 |  | IOBS | IO_L16N_0 | UNUSED |  | 0
C6 |  |  | GND
C7 | mgtrxn | IPAD | MGTRXN0_101 | INPUT |  |  |  |  |  | NONE |  | UNLOCATED | NO | NONE
C8 |  |  | GND
C9 |  | IPAD | MGTRXN1_101 | UNUSED
C10 |  |  | MGTAVCC_101
C11 |  | IPAD | MGTREFCLK1N_101 | UNUSED
C12 |  |  | MGTAVCCPLL1_101
C13 | mgtmod1<1> | IOB | IO_L35P_GCLK17_0 | OUTPUT | LVCMOS33 | 0 | 12 | SLOW |  |  |  | LOCATED | NO | NONE
C14 |  |  | MGTAVCCPLL0_123
C15 |  | IPAD | MGTREFCLK0N_123 | UNUSED
C16 |  |  | MGTAVCC_123
C17 |  | IPAD | MGTRXN0_123 | UNUSED
C18 |  |  | GND
C19 |  | IPAD | MGTRXN1_123 | UNUSED
C20 |  |  | GND
C21 |  | IOBM | IO_L59P_0 | UNUSED |  | 0
C22 |  |  | VCCO_0 |  |  | 0 |  |  |  |  | 3.30
C23 |  |  | TDI
C24 | target_tb<6><2> | IOB | IO_L4N_M5A12_5 | INPUT | LVCMOS25* | 5 |  |  |  | NONE |  | LOCATED | NO | NONE
C25 |  | IOBM | IO_L10P_M5A0_5 | UNUSED |  | 5
C26 |  | IOBS | IO_L10N_M5A1_5 | UNUSED |  | 5
D1 |  | IOBS | IO_L68N_M4DQ5_4 | UNUSED |  | 4
D2 |  |  | VCCO_4 |  |  | 4 |  |  |  |  | any******
D3 |  | IOBM | IO_L68P_M4DQ4_4 | UNUSED |  | 4
D4 |  |  | GND
D5 |  | IOBM | IO_L16P_0 | UNUSED |  | 0
D6 |  |  | VCCAUX |  |  |  |  |  |  |  | 2.5
D7 | mgtrxp | IPAD | MGTRXP0_101 | INPUT |  |  |  |  |  | NONE |  | UNLOCATED | NO | NONE
D8 |  |  | MGTAVTTRX_101
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

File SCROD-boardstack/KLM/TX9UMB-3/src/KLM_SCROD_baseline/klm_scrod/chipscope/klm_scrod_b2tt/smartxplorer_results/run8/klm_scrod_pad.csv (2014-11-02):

#Release 14.6 - par P.68d (nt64)
#Copyright (c) 1995-2013 Xilinx | Inc. All rights reserved.
#Tue Oct 14 12:53:12 2014
#
## NOTE: This file is designed to be imported into a spreadsheet program
# such as Microsoft Excel for viewing | printing and sorting. The
# character is used as the data field separator. This file is also designed
# to support parsing.
#
#INPUT FILE: klm_scrod_map.ncd
#OUTPUT FILE: klm_scrod_pad.csv
#PART TYPE: xc6slx150t
#SPEED GRADE: -3
#PACKAGE: fgg676
#
# Pinout by Pin Number:
#
# ----- | ----- | ----- | ----- | ----- | ----- | ----- | ----- | ----- | ----- | ----- | ----- | ----- | ----- | -----
Pin Number | Signal Name | Pin Usage | Pin Name | Direction | IO Standard | IO Bank Number | Drive (mA) | Slew Rate | Termination | IOB Delay | Voltage | Constraint | IO Register | Signal Integrity
A1 |  |  | GND
A2 |  | IOBS | IO_L14N_0 | UNUSED |  | 0
A3 |  | IOBM | IO_L14P_0 | UNUSED |  | 0
A4 |  | IOBS | IO_L22N_0 | UNUSED |  | 0
A5 | mgttxfault<2> | IOB | IO_L24N_0 | INPUT | LVCMOS33 | 0 |  |  |  | NONE |  | LOCATED | YES | NONE
A6 | mgttxn | OPAD | MGTTXN0_101 | OUTPUT |  |  |  |  |  |  |  | UNLOCATED | NO | NONE
A7 |  |  | MGTAVTTTX_101
A8 |  | OPAD | MGTTXN1_101 | UNUSED
A9 |  |  | GND
A10 |  | IPAD | MGTREFCLK0N_101 | UNUSED
A11 |  |  | GND
A12 |  | IOBS | IO_L36N_GCLK14_0 | UNUSED |  | 0
A13 | mgtmod0<1> | IOB | IO_L35N_GCLK16_0 | INPUT | LVCMOS33 | 0 |  |  |  | NONE |  | LOCATED | YES | NONE
A14 | mgtmod2<2> | IOB | IO_L37N_GCLK12_0 | OUTPUT | LVCMOS33 | 0 | 12 | SLOW |  |  |  | LOCATED | NO | NONE
A15 |  |  | GND
A16 |  | IPAD | MGTREFCLK1N_123 | UNUSED
A17 |  |  | GND
A18 |  | OPAD | MGTTXN0_123 | UNUSED
A19 |  |  | MGTAVTTTX_123
A20 |  | OPAD | MGTTXN1_123 | UNUSED
A21 |  |  | GND
A22 |  | IOBS | IO_L63N_SCP6_0 | UNUSED |  | 0
A23 |  | IOBS | IO_L65N_SCP2_0 | UNUSED |  | 0
A24 |  |  | TCK
A25 |  | IOBS | IO_L2N_M5A14_5 | UNUSED |  | 5
A26 |  |  | GND
AA1 |  | IOBS | IO_L36N_M3DQ9_3 | UNUSED |  | 3
AA2 |  | IOBM | IO_L36P_M3DQ8_3 | UNUSED |  | 3
AA3 |  | IOBS | IO_L2N_3 | UNUSED |  | 3
AA4 |  | IOBM | IO_L2P_3 | UNUSED |  | 3
AA5 |  |  | VCCAUX |  |  |  |  |  |  |  | 2.5
AA6 | target_tb<3><2> | IOB | IO_L64N_D9_2 | INPUT | LVCMOS25* | 2 |  |  |  | NONE |  | LOCATED | NO | NONE
AA7 | target_tb<4><2> | IOB | IO_L64P_D8_2 | INPUT | LVCMOS25* | 2 |  |  |  | NONE |  | LOCATED | NO | NONE
AA8 |  | IOBS | IO_L52N_2 | UNUSED |  | 2
AA9 |  | IOBM | IO_L47P_2 | UNUSED |  | 2
AA10 |  | IOBM | IO_L48P_D7_2 | UNUSED |  | 2
AA11 |  | IOBS | IO_L41N_VREF_2 | UNUSED |  | 2
AA12 | target_tb<3><1> | IOB | IO_L33N_2 | INPUT | LVCMOS25* | 2 |  |  |  | NONE |  | LOCATED | NO | NONE
AA13 |  | IOBS | IO_L36N_2 | UNUSED |  | 2
AA14 |  |  | VCCO_2 |  |  | 2 |  |  |  |  | 2.50
AA15 | target_tb16<7> | IOB | IO_L28P_2 | INPUT | LVCMOS25* | 2 |  |  |  | NONE |  | LOCATED | NO | NONE
AA16 |  | IOBS | IO_L24N_VREF_2 | UNUSED |  | 2
AA17 | target_tb<8><5> | IOB | IO_L16N_VREF_2 | INPUT | LVCMOS25* | 2 |  |  |  | NONE |  | LOCATED | NO | NONE
AA18 |  | IOBM | IO_L20P_2 | UNUSED |  | 2
AA19 |  | IOBM | IO_L18P_2 | UNUSED |  | 2
AA20 |  |  | VCCO_2 |  |  | 2 |  |  |  |  | 2.50
AA21 |  | IOBM | IO_L15P_2 | UNUSED |  | 2
AA22 | target_tb<8><1> | IOB | IO_L2N_CMPMOSI_2 | INPUT | LVCMOS25* | 2 |  |  |  | NONE |  | LOCATED | NO | NONE
AA23 |  | IOBM | IO_L67P_1 | UNUSED |  | 1
AA24 |  | IOBS | IO_L67N_1 | UNUSED |  | 1
AA25 |  | IOBM | IO_L47P_FWE_B_M1DQ0_1 | UNUSED |  | 1
AA26 |  | IOBS | IO_L47N_LDC_M1DQ1_1 | UNUSED |  | 1
AB1 |  | IOBS | IO_L32N_M3DQ15_3 | UNUSED |  | 3
AB2 |  |  | GND
AB3 |  | IOBM | IO_L32P_M3DQ14_3 | UNUSED |  | 3
AB4 |  | IOBM | IO_L8P_3 | UNUSED |  | 3
AB5 |  | IOBM | IO_L1P_3 | UNUSED |  | 3
AB6 |  |  | VCCO_2 |  |  | 2 |  |  |  |  | 2.50
AB7 |  | IOBM | IO_L53P_2 | UNUSED |  | 2
AB8 |  |  | VCCAUX |  |  |  |  |  |  |  | 2.5
AB9 |  | IOBS | IO_L47N_2 | UNUSED |  | 2
AB10 |  |  | MGTRREF_245
AB11 |  | IOBS | IO_L48N_RDWR_B_VREF_2 | UNUSED |  | 2
AB12 |  |  | MGTAVTTRCAL_245
AB13 |  | IOBM | IO_L36P_2 | UNUSED |  | 2
AB14 | ttdtrgp | IOB | IO_L30P_GCLK1_D13_2 | INPUT | LVDS_25 | 2 |  |  |  | NONE |  | LOCATED | YES | DIFF_TERM
AB15 |  | IOBS | IO_L28N_2 | UNUSED |  | 2
AB16 |  |  | GND
AB17 |  | IOBS | IO_L20N_2 | UNUSED |  | 2
AB18 |  |  | VCCAUX |  |  |  |  |  |  |  | 2.5
AB19 |  | IOBS | IO_L18N_2 | UNUSED |  | 2
AB20 |  |  | GND
AB21 | target_tb16<8> | IOB | IO_L15N_2 | INPUT | LVCMOS25* | 2 |  |  |  | NONE |  | LOCATED | NO | NONE
AB22 |  | IOBM | IO_L5P_2 | UNUSED |  | 2
AB23 |  |  | VCCO_1 |  |  | 1 |  |  |  |  | any******
AB24 |  | IOBM | IO_L49P_M1DQ10_1 | UNUSED |  | 1
AB25 |  |  | GND
AB26 |  | IOBS | IO_L49N_M1DQ11_1 | UNUSED |  | 1
AC1 |  | IOBS | IO_L34N_M3UDQSN_3 | UNUSED |  | 3
AC2 |  | IOBM | IO_L34P_M3UDQS_3 | UNUSED |  | 3
AC3 |  | IOBS | IO_L8N_3 | UNUSED |  | 3
AC4 |  | IOBS | IO_L1N_VREF_3 | UNUSED |  | 3
AC5 |  | IOBM | IO_L61P_2 | UNUSED |  | 2
AC6 |  | IOBS | IO_L53N_2 | UNUSED |  | 2
AC7 |  |  | VCCAUX |  |  |  |  |  |  |  | 2.5
AC8 |  | IPAD | MGTRXP0_245 | UNUSED
AC9 |  |  | MGTAVTTRX_245
AC10 |  | IPAD | MGTRXP1_245 | UNUSED
AC11 |  |  | GND
AC12 |  | IPAD | MGTREFCLK1P_245 | UNUSED
AC13 |  |  | GND
AC14 | ttdtrgn | IOB | IO_L30N_GCLK0_USERCCLK_2 |  | LVDS_25 | 2 |  |  |  |  |  | LOCATED | NO | DIFF_TERM
AC15 |  |  | GND
AC16 |  | IPAD | MGTREFCLK0P_267 | UNUSED
AC17 |  |  | GND
AC18 |  | IPAD | MGTRXP0_267 | UNUSED
AC19 |  |  | MGTAVTTRX_267
AC20 |  | IPAD | MGTRXP1_267 | UNUSED
AC21 |  |  | VCCAUX |  |  |  |  |  |  |  | 2.5
AC22 | target_tb<8><3> | IOB | IO_L5N_2 | INPUT | LVCMOS25* | 2 |  |  |  | NONE |  | LOCATED | NO | NONE
AC23 |  | IOBM | IO_L74P_AWAKE_1 | UNUSED |  | 1
AC24 |  | IOBS | IO_L74N_DOUT_BUSY_1 | UNUSED |  | 1
AC25 |  | IOBM | IO_L50P_M1UDQS_1 | UNUSED |  | 1
AC26 | target_tb<6><5> | IOB | IO_L50N_M1UDQSN_1 | INPUT | LVCMOS25* | 1 |  |  |  | NONE |  | LOCATED | NO | NONE
AD1 |  | IOBS | IO_L33N_M3DQ13_3 | UNUSED |  | 3
AD2 |  |  | VCCO_3 |  |  | 3 |  |  |  |  | any******
AD3 |  | IOBM | IO_L33P_M3DQ12_3 | UNUSED |  | 3
AD4 | target_tb16<2> | IOB | IO_L63P_2 | INPUT | LVCMOS25* | 2 |  |  |  | NONE |  | LOCATED | NO | NONE
AD5 |  | IOBS | IO_L61N_VREF_2 | UNUSED |  | 2
AD6 |  | IOBM | IO_L49P_D3_2 | UNUSED |  | 2
AD7 |  |  | GND
AD8 |  | IPAD | MGTRXN0_245 | UNUSED
AD9 |  |  | GND
AD10 |  | IPAD | MGTRXN1_245 | UNUSED
AD11 |  |  | MGTAVCC_245
AD12 |  | IPAD | MGTREFCLK1N_245 | UNUSED
AD13 |  |  | MGTAVCCPLL1_245
AD14 | ttdackp | IOBM | IO_L32P_GCLK29_2 | TRISTATE | LVDS_25 | 2 |  |  |  |  |  | LOCATED | YES | NONE
AD15 |  |  | MGTAVCCPLL0_267
AD16 |  | IPAD | MGTREFCLK0N_267 | UNUSED
AD17 |  |  | MGTAVCC_267
AD18 |  | IPAD | MGTRXN0_267 | UNUSED
AD19 |  |  | GND
AD20 |  | IPAD | MGTRXN1_267 | UNUSED
AD21 |  |  | GND
AD22 |  | IOBM | IO_L13P_M1_2 | UNUSED |  | 2
AD23 |  | IOBM | IO_L3P_D0_DIN_MISO_MISO1_2 | UNUSED |  | 2
AD24 |  | IOBM | IO_L48P_HDC_M1DQ8_1 | UNUSED |  | 1
AD25 |  |  | VCCO_1 |  |  | 1 |  |  |  |  | any******
AD26 | target_tb16<6> | IOB | IO_L48N_M1DQ9_1 | INPUT | LVCMOS25* | 1 |  |  |  | NONE |  | LOCATED | NO | NONE
AE1 |  | IOBS | IO_L35N_M3DQ11_3 | UNUSED |  | 3
AE2 |  | IOBM | IO_L35P_M3DQ10_3 | UNUSED |  | 3
AE3 |  | IOBM | IO_L65P_INIT_B_2 | UNUSED |  | 2
AE4 |  |  | VCCO_2 |  |  | 2 |  |  |  |  | 2.50
AE5 |  | IOBM | IO_L51P_2 | UNUSED |  | 2
AE6 |  |  | GND
AE7 |  | OPAD | MGTTXP0_245 | UNUSED
AE8 |  |  | GND
AE9 |  | OPAD | MGTTXP1_245 | UNUSED
AE10 |  |  | GND
AE11 |  | IPAD | MGTREFCLK0P_245 | UNUSED
AE12 |  |  | MGTAVCCPLL0_245
AE13 | ttdclkp | IOB | IO_L31P_GCLK31_D14_2 | INPUT | LVDS_25 | 2 |  |  |  | NONE |  | LOCATED | NO | DIFF_TERM
AE14 |  |  | VCCO_2 |  |  | 2 |  |  |  |  | 2.50
AE15 | ttdrsvp | IOB | IO_L29P_GCLK3_2 | OUTPUT | LVCMOS25* | 2 | 12 | SLOW |  |  |  | LOCATED | NO | NONE
AE16 |  |  | MGTAVCCPLL1_267
AE17 |  | IPAD | MGTREFCLK1P_267 | UNUSED
AE18 |  |  | GND
AE19 |  | OPAD | MGTTXP0_267 | UNUSED
AE20 |  |  | GND
AE21 |  | OPAD | MGTTXP1_267 | UNUSED
AE22 |  |  | GND
AE23 |  |  | VCCO_2 |  |  | 2 |  |  |  |  | 2.50
AE24 |  | IOBM | IO_L1P_CCLK_2 | UNUSED |  | 2
AE25 | target_tb<6><3> | IOB | IO_L52P_M1DQ14_1 | INPUT | LVCMOS25* | 1 |  |  |  | NONE |  | LOCATED | NO | NONE
AE26 | target_tb<6><4> | IOB | IO_L52N_M1DQ15_1 | INPUT | LVCMOS25* | 1 |  |  |  | NONE |  | LOCATED | NO | NONE
AF1 |  |  | GND
AF2 |  |  | PROGRAM_B_2
AF3 |  | IOBS | IO_L65N_CSO_B_2 | UNUSED |  | 2
AF4 |  | IOBS | IO_L63N_2 | UNUSED |  | 2
AF5 |  | IOBS | IO_L51N_2 | UNUSED |  | 2
AF6 |  | IOBS | IO_L49N_D4_2 | UNUSED |  | 2
AF7 |  | OPAD | MGTTXN0_245 | UNUSED
AF8 |  |  | MGTAVTTTX_245
AF9 |  | OPAD | MGTTXN1_245 | UNUSED
AF10 |  |  | GND
AF11 |  | IPAD | MGTREFCLK0N_245 | UNUSED
AF12 |  |  | GND
AF13 | ttdclkn | IOB | IO_L31N_GCLK30_D15_2 |  | LVDS_25 | 2 |  |  |  |  |  | LOCATED | NO | DIFF_TERM
AF14 | ttdackn | IOBS | IO_L32N_GCLK28_2 |  | LVDS_25 | 2 |  |  |  |  |  | LOCATED | NO
AF15 | ttdrsvn | IOB | IO_L29N_GCLK2_2 | OUTPUT | LVCMOS25* | 2 | 12 | SLOW |  |  |  | LOCATED | NO | NONE
AF16 |  |  | GND
AF17 |  | IPAD | MGTREFCLK1N_267 | UNUSED
AF18 |  |  | GND
AF19 |  | OPAD | MGTTXN0_267 | UNUSED
AF20 |  |  | MGTAVTTTX_267
AF21 |  | OPAD | MGTTXN1_267 | UNUSED
AF22 |  | IOBS | IO_L13N_D10_2 | UNUSED |  | 2
AF23 |  | IOBS | IO_L3N_MOSI_CSI_B_MISO0_2 | UNUSED |  | 2
AF24 |  | IOBS | IO_L1N_M0_CMPMISO_2 | UNUSED |  | 2
AF25 |  |  | DONE_2
AF26 |  |  | GND
B1 |  | IOBS | IO_L75N_M4BA1_4 | UNUSED |  | 4
B2 |  | IOBM | IO_L75P_M4BA0_4 | UNUSED |  | 4
B3 |  | IOBS | IO_L4N_0 | UNUSED |  | 0
B4 |  | IOBM | IO_L22P_0 | UNUSED |  | 0
B5 | mgtlos<1> | IOB | IO_L24P_0 | INPUT | LVCMOS33 | 0 |  |  |  | NONE |  | LOCATED | YES | NONE
B6 | mgttxp | OPAD | MGTTXP0_101 | OUTPUT |  |  |  |  |  |  |  | UNLOCATED | NO | NONE
B7 |  |  | GND
B8 |  | OPAD | MGTTXP1_101 | UNUSED
B9 |  |  | GND
B10 |  | IPAD | MGTREFCLK0P_101 | UNUSED
B11 |  |  | MGTAVCCPLL0_101
B12 |  | IOBM | IO_L36P_GCLK15_0 | UNUSED |  | 0
B13 |  |  | VCCO_0 |  |  | 0 |  |  |  |  | 3.30
B14 |  | IOBM | IO_L37P_GCLK13_0 | UNUSED |  | 0
B15 |  |  | MGTAVCCPLL1_123
B16 |  | IPAD | MGTREFCLK1P_123 | UNUSED
B17 |  |  | GND
B18 |  | OPAD | MGTTXP0_123 | UNUSED
B19 |  |  | GND
B20 |  | OPAD | MGTTXP1_123 | UNUSED
B21 |  | IOBS | IO_L59N_0 | UNUSED |  | 0
B22 |  | IOBM | IO_L63P_SCP7_0 | UNUSED |  | 0
B23 |  | IOBM | IO_L65P_SCP3_0 | UNUSED |  | 0
B24 |  | IOBM | IO_L2P_M5A13_5 | UNUSED |  | 5
B25 |  | IOBM | IO_L11P_M5CLK_5 | UNUSED |  | 5
B26 |  | IOBS | IO_L11N_M5CLKN_5 | UNUSED |  | 5
C1 | target_tb<2><2> | IOB | IO_L79N_M4A9_4 | INPUT | LVCMOS25* | 4 |  |  |  | NONE |  | LOCATED | NO | NONE
C2 | target_tb<2><1> | IOB | IO_L79P_M4A8_4 | INPUT | LVCMOS25* | 4 |  |  |  | NONE |  | LOCATED | NO | NONE
C3 |  | IOBM | IO_L4P_0 | UNUSED |  | 0
C4 |  |  | VCCO_0 |  |  | 0 |  |  |  |  | 3.30
C5 |  | IOBS | IO_L16N_0 | UNUSED |  | 0
C6 |  |  | GND
C7 | mgtrxn | IPAD | MGTRXN0_101 | INPUT |  |  |  |  |  | NONE |  | UNLOCATED | NO | NONE
C8 |  |  | GND
C9 |  | IPAD | MGTRXN1_101 | UNUSED
C10 |  |  | MGTAVCC_101
C11 |  | IPAD | MGTREFCLK1N_101 | UNUSED
C12 |  |  | MGTAVCCPLL1_101
C13 | mgtmod1<1> | IOB | IO_L35P_GCLK17_0 | OUTPUT | LVCMOS33 | 0 | 12 | SLOW |  |  |  | LOCATED | NO | NONE
C14 |  |  | MGTAVCCPLL0_123
C15 |  | IPAD | MGTREFCLK0N_123 | UNUSED
C16 |  |  | MGTAVCC_123
C17 |  | IPAD | MGTRXN0_123 | UNUSED
C18 |  |  | GND
C19 |  | IPAD | MGTRXN1_123 | UNUSED
C20 |  |  | GND
C21 |  | IOBM | IO_L59P_0 | UNUSED |  | 0
C22 |  |  | VCCO_0 |  |  | 0 |  |  |  |  | 3.30
C23 |  |  | TDI
C24 | target_tb<6><2> | IOB | IO_L4N_M5A12_5 | INPUT | LVCMOS25* | 5 |  |  |  | NONE |  | LOCATED | NO | NONE
C25 |  | IOBM | IO_L10P_M5A0_5 | UNUSED |  | 5
C26 |  | IOBS | IO_L10N_M5A1_5 | UNUSED |  | 5
D1 |  | IOBS | IO_L68N_M4DQ5_4 | UNUSED |  | 4
D2 |  |  | VCCO_4 |  |  | 4 |  |  |  |  | any******
D3 |  | IOBM | IO_L68P_M4DQ4_4 | UNUSED |  | 4
D4 |  |  | GND
D5 |  | IOBM | IO_L16P_0 | UNUSED |  | 0
D6 |  |  | VCCAUX |  |  |  |  |  |  |  | 2.5
D7 | mgtrxp | IPAD | MGTRXP0_101 | INPUT |  |  |  |  |  | NONE |  | UNLOCATED | NO | NONE
D8 |  |  | MGTAVTTRX_101
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

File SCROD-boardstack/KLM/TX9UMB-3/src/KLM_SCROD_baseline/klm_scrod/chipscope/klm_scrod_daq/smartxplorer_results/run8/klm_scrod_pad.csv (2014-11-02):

#Release 14.6 - par P.68d (nt64)
#Copyright (c) 1995-2013 Xilinx | Inc. All rights reserved.
#Tue Oct 14 17:07:18 2014
#
## NOTE: This file is designed to be imported into a spreadsheet program
# such as Microsoft Excel for viewing | printing and sorting. The
# character is used as the data field separator. This file is also designed
# to support parsing.
#
#INPUT FILE: klm_scrod_map.ncd
#OUTPUT FILE: klm_scrod_pad.csv
#PART TYPE: xc6slx150t
#SPEED GRADE: -3
#PACKAGE: fgg676
#
# Pinout by Pin Number:
#
# ----- | ----- | ----- | ----- | ----- | ----- | ----- | ----- | ----- | ----- | ----- | ----- | ----- | ----- | -----
Pin Number | Signal Name | Pin Usage | Pin Name | Direction | IO Standard | IO Bank Number | Drive (mA) | Slew Rate | Termination | IOB Delay | Voltage | Constraint | IO Register | Signal Integrity
A1 |  |  | GND
A2 |  | IOBS | IO_L14N_0 | UNUSED |  | 0
A3 |  | IOBM | IO_L14P_0 | UNUSED |  | 0
A4 |  | IOBS | IO_L22N_0 | UNUSED |  | 0
A5 | mgttxfault<2> | IOB | IO_L24N_0 | INPUT | LVCMOS33 | 0 |  |  |  | NONE |  | LOCATED | YES | NONE
A6 | mgttxn | OPAD | MGTTXN0_101 | OUTPUT |  |  |  |  |  |  |  | UNLOCATED | NO | NONE
A7 |  |  | MGTAVTTTX_101
A8 |  | OPAD | MGTTXN1_101 | UNUSED
A9 |  |  | GND
A10 |  | IPAD | MGTREFCLK0N_101 | UNUSED
A11 |  |  | GND
A12 |  | IOBS | IO_L36N_GCLK14_0 | UNUSED |  | 0
A13 | mgtmod0<1> | IOB | IO_L35N_GCLK16_0 | INPUT | LVCMOS33 | 0 |  |  |  | NONE |  | LOCATED | YES | NONE
A14 | mgtmod2<2> | IOB | IO_L37N_GCLK12_0 | OUTPUT | LVCMOS33 | 0 | 12 | SLOW |  |  |  | LOCATED | NO | NONE
A15 |  |  | GND
A16 |  | IPAD | MGTREFCLK1N_123 | UNUSED
A17 |  |  | GND
A18 |  | OPAD | MGTTXN0_123 | UNUSED
A19 |  |  | MGTAVTTTX_123
A20 |  | OPAD | MGTTXN1_123 | UNUSED
A21 |  |  | GND
A22 |  | IOBS | IO_L63N_SCP6_0 | UNUSED |  | 0
A23 |  | IOBS | IO_L65N_SCP2_0 | UNUSED |  | 0
A24 |  |  | TCK
A25 |  | IOBS | IO_L2N_M5A14_5 | UNUSED |  | 5
A26 |  |  | GND
AA1 |  | IOBS | IO_L36N_M3DQ9_3 | UNUSED |  | 3
AA2 |  | IOBM | IO_L36P_M3DQ8_3 | UNUSED |  | 3
AA3 |  | IOBS | IO_L2N_3 | UNUSED |  | 3
AA4 |  | IOBM | IO_L2P_3 | UNUSED |  | 3
AA5 |  |  | VCCAUX |  |  |  |  |  |  |  | 2.5
AA6 | target_tb<3><2> | IOB | IO_L64N_D9_2 | INPUT | LVCMOS25* | 2 |  |  |  | NONE |  | LOCATED | NO | NONE
AA7 | target_tb<4><2> | IOB | IO_L64P_D8_2 | INPUT | LVCMOS25* | 2 |  |  |  | NONE |  | LOCATED | NO | NONE
AA8 |  | IOBS | IO_L52N_2 | UNUSED |  | 2
AA9 |  | IOBM | IO_L47P_2 | UNUSED |  | 2
AA10 |  | IOBM | IO_L48P_D7_2 | UNUSED |  | 2
AA11 |  | IOBS | IO_L41N_VREF_2 | UNUSED |  | 2
AA12 | target_tb<3><1> | IOB | IO_L33N_2 | INPUT | LVCMOS25* | 2 |  |  |  | NONE |  | LOCATED | NO | NONE
AA13 |  | IOBS | IO_L36N_2 | UNUSED |  | 2
AA14 |  |  | VCCO_2 |  |  | 2 |  |  |  |  | 2.50
AA15 | target_tb16<7> | IOB | IO_L28P_2 | INPUT | LVCMOS25* | 2 |  |  |  | NONE |  | LOCATED | NO | NONE
AA16 |  | IOBS | IO_L24N_VREF_2 | UNUSED |  | 2
AA17 | target_tb<8><5> | IOB | IO_L16N_VREF_2 | INPUT | LVCMOS25* | 2 |  |  |  | NONE |  | LOCATED | NO | NONE
AA18 |  | IOBM | IO_L20P_2 | UNUSED |  | 2
AA19 |  | IOBM | IO_L18P_2 | UNUSED |  | 2
AA20 |  |  | VCCO_2 |  |  | 2 |  |  |  |  | 2.50
AA21 |  | IOBM | IO_L15P_2 | UNUSED |  | 2
AA22 | target_tb<8><1> | IOB | IO_L2N_CMPMOSI_2 | INPUT | LVCMOS25* | 2 |  |  |  | NONE |  | LOCATED | NO | NONE
AA23 |  | IOBM | IO_L67P_1 | UNUSED |  | 1
AA24 |  | IOBS | IO_L67N_1 | UNUSED |  | 1
AA25 |  | IOBM | IO_L47P_FWE_B_M1DQ0_1 | UNUSED |  | 1
AA26 |  | IOBS | IO_L47N_LDC_M1DQ1_1 | UNUSED |  | 1
AB1 |  | IOBS | IO_L32N_M3DQ15_3 | UNUSED |  | 3
AB2 |  |  | GND
AB3 |  | IOBM | IO_L32P_M3DQ14_3 | UNUSED |  | 3
AB4 |  | IOBM | IO_L8P_3 | UNUSED |  | 3
AB5 |  | IOBM | IO_L1P_3 | UNUSED |  | 3
AB6 |  |  | VCCO_2 |  |  | 2 |  |  |  |  | 2.50
AB7 |  | IOBM | IO_L53P_2 | UNUSED |  | 2
AB8 |  |  | VCCAUX |  |  |  |  |  |  |  | 2.5
AB9 |  | IOBS | IO_L47N_2 | UNUSED |  | 2
AB10 |  |  | MGTRREF_245
AB11 |  | IOBS | IO_L48N_RDWR_B_VREF_2 | UNUSED |  | 2
AB12 |  |  | MGTAVTTRCAL_245
AB13 |  | IOBM | IO_L36P_2 | UNUSED |  | 2
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

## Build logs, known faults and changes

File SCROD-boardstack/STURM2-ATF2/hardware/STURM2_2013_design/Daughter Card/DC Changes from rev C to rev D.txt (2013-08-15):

STURM2 DC board major changes from REV C to REV D

- Cal+ and Cal- changed to differential pair, Schematic updated
- Regulator V4 ( unnecessary VPED regulator ) removed along with is other components ( R11,R12,C3,C4)
- All DAC output capacitors removed
- Added testpoint for VPED, TSA0 and GND
- Changed DAC (AD3524) another input capacitor from 0.1uf to 10uf as shown on the component datasheet. 
- Added buffer amplifier (LMV321WG-7) to DAC 3 PED_SCAN output

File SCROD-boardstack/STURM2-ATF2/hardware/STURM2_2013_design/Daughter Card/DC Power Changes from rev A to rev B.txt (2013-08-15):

STURM2 DC Power board major changes from REV A to REV B

- Changed 1.2 Volt regulator to AP1122EG-13
- Fixed power issue with SCROD J4 connector
- CAl+ and CAL- traces changed to differential pair for all DC board connectors
- Testpoints added for GND, 1.2V, 2.5V, 3.3V, 5V 
- New routing with less vias

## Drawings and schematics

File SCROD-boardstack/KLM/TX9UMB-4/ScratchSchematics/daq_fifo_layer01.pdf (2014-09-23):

# internal_EVT_INP_FIFO_READ_ENABLE_pre<7>_imp

# internal_EVT_INP_FIFO_READ_ENABLE_pre<7>_imp

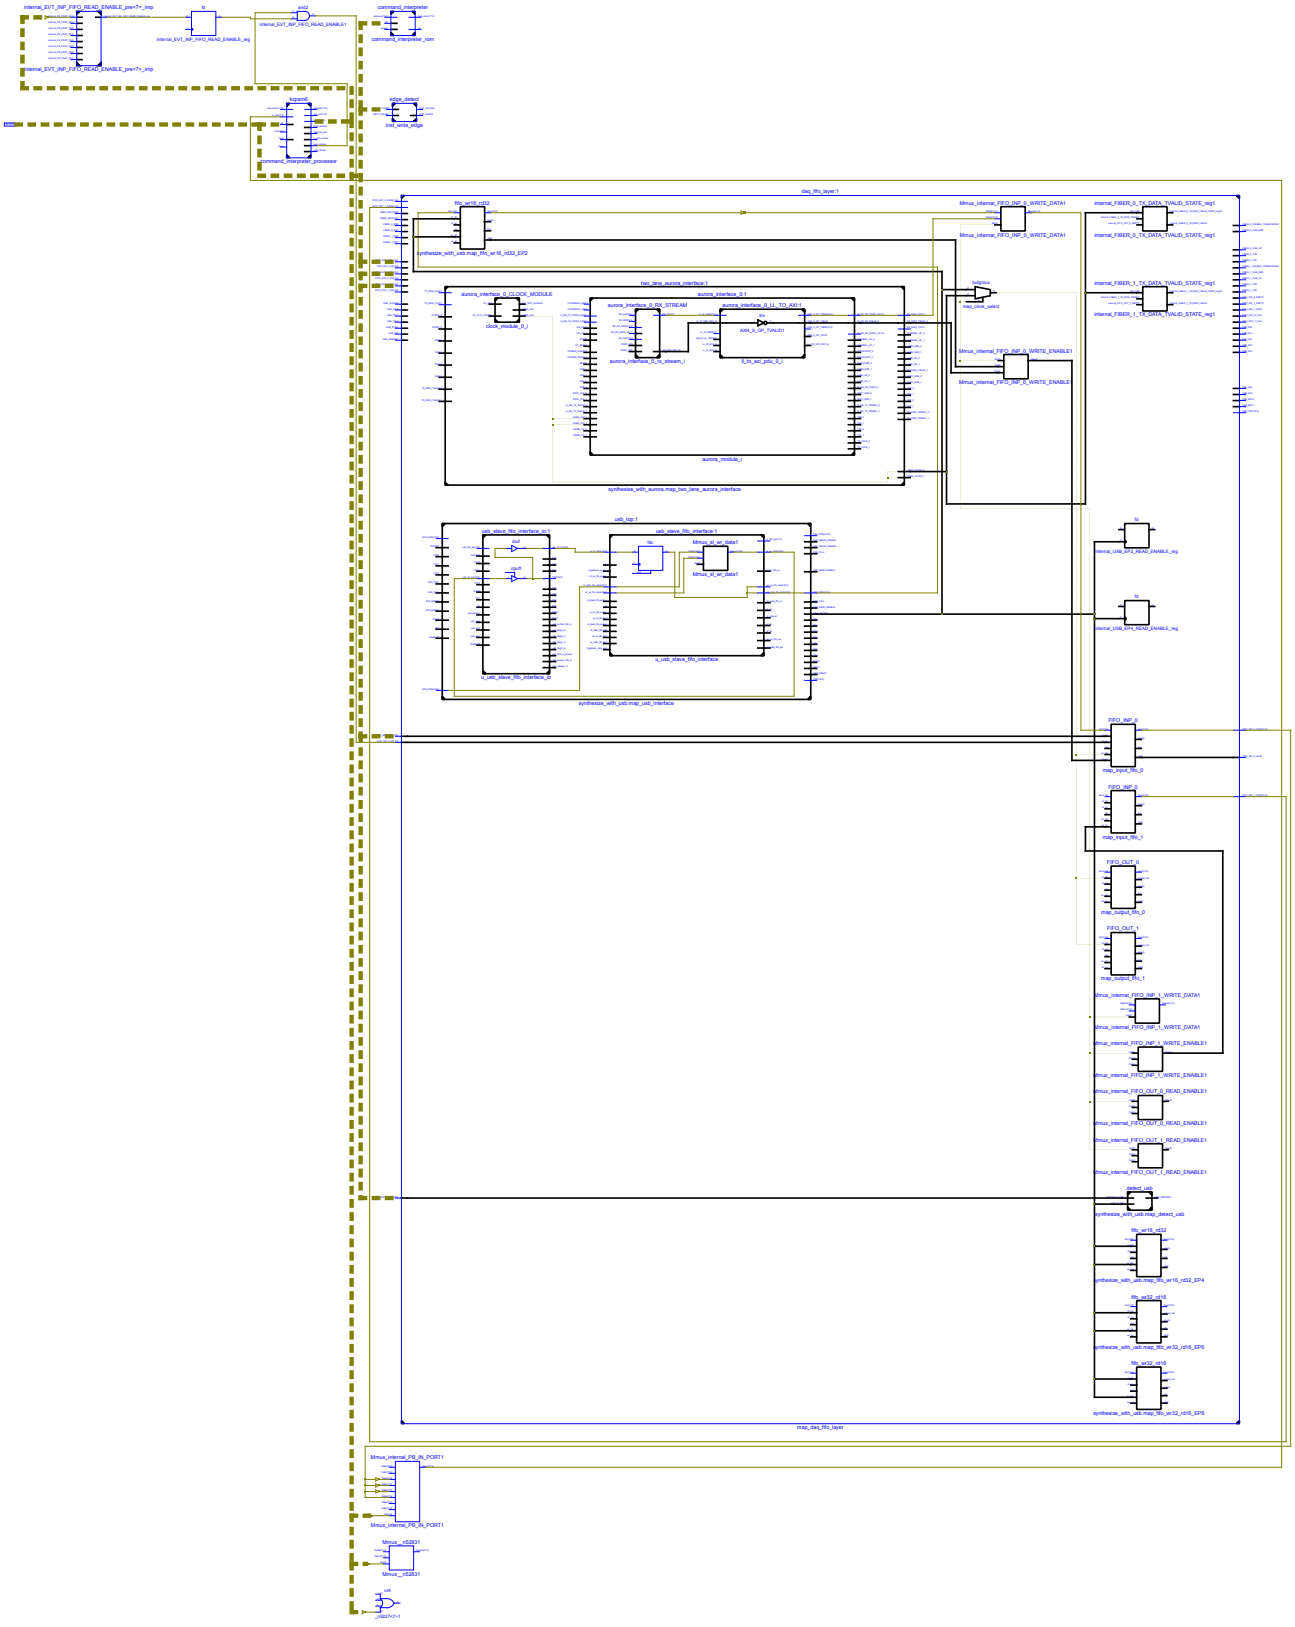
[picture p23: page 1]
internal_PB_PORT_ID(0); internal_PB_PORT_ID(1); internal_PB_PORT_ID(2); internal_PB_PORT_ID(3); internal_PB_PORT_ID(4); internal_PB_PORT_ID(5); internal_PB_PORT_ID(6); internal_PB_PORT_ID(7); internal_EVT_INP_FIFO_READ_ENABLE_pre; internal_EVT_INP_FIFO_READ_ENABLE_reg; and2; internal_EVT_INP_FIFO_READ_ENABLE1; kcpsm6; command_interpreter_processor; instruction(17:0); address(11:0) out_port(7:0) port_id(7:0) bram_enable; interrupt_ack; k_write_strobe; read_strobe write_strobe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

address(11:0) clk enable

in_port(7:0) clk
interrupt reset sleep

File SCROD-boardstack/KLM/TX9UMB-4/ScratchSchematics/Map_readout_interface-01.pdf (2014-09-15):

# edge_detect

# inst_write_edge

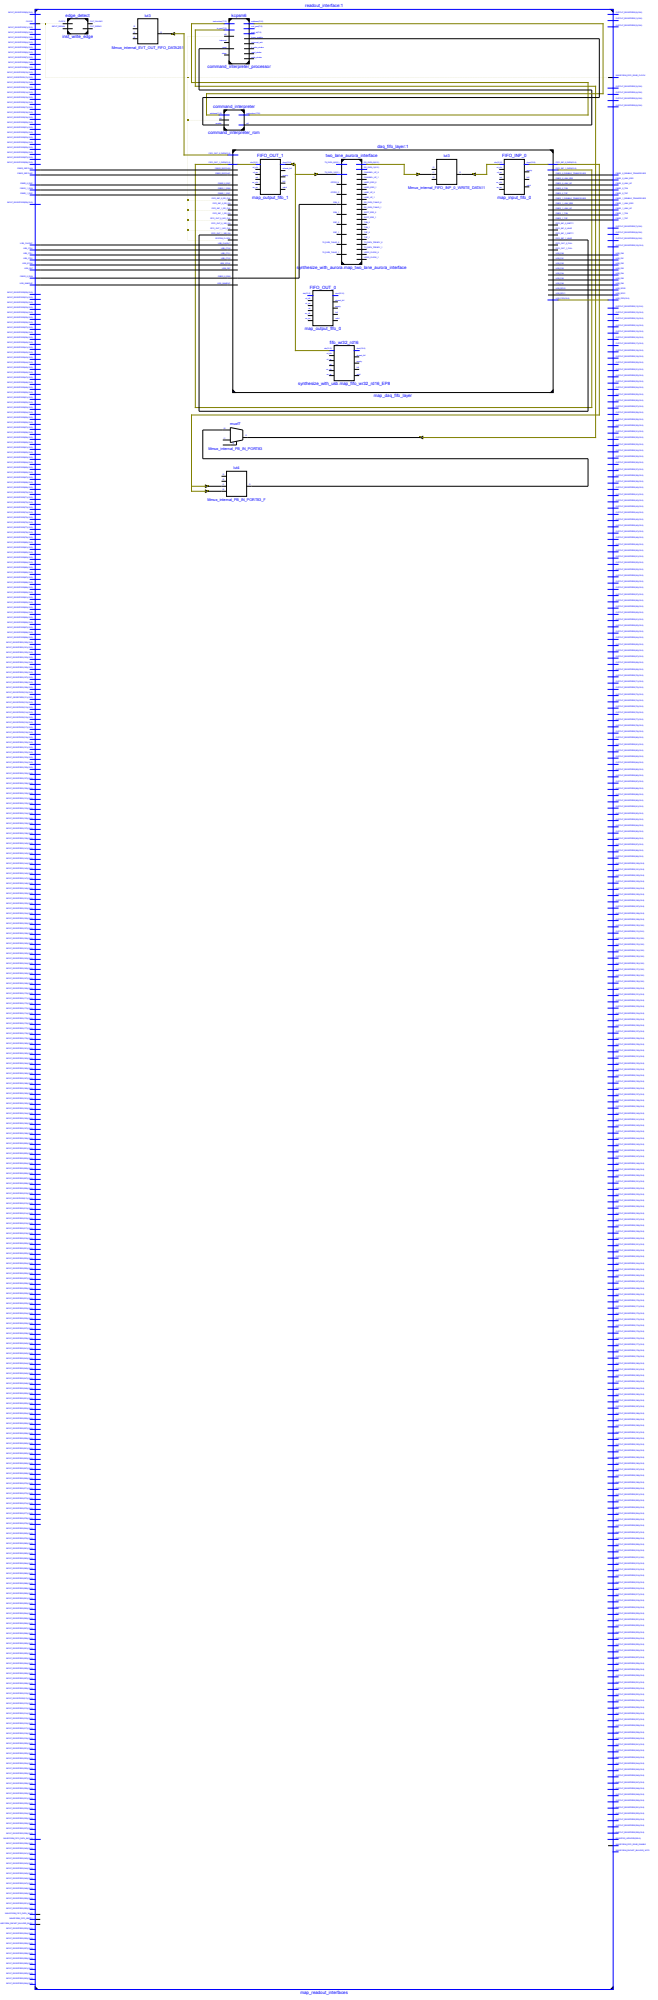
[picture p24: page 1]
CLOCK; INPUT_SIGNAL; OUT_FALLING; OUT_RISING; lut3; Mmux_internal_EVT_OUT_FIFO_DATA251; kcpsm6; command_interpreter_processor; instruction(17:0); in_port(7:0); clk; interrupt; reset; sleep; address(11:0); out_port(7:0); port_id(7:0); bram_enable; interrupt_ack; k_write_strobe; read_strobe; write_strobe; command_interpreter; command_interpreter_rom; enable; rdl; FIFO_OUT_1; map_output_fifo_1; din(31:0); rd_clk; rst; wr_clk; dout(31:0); almost_full; empty; full; valid; two_lane_aurora_interface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

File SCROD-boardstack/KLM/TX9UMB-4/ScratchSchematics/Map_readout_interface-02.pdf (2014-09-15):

# edge_detect

# inst_write_edge

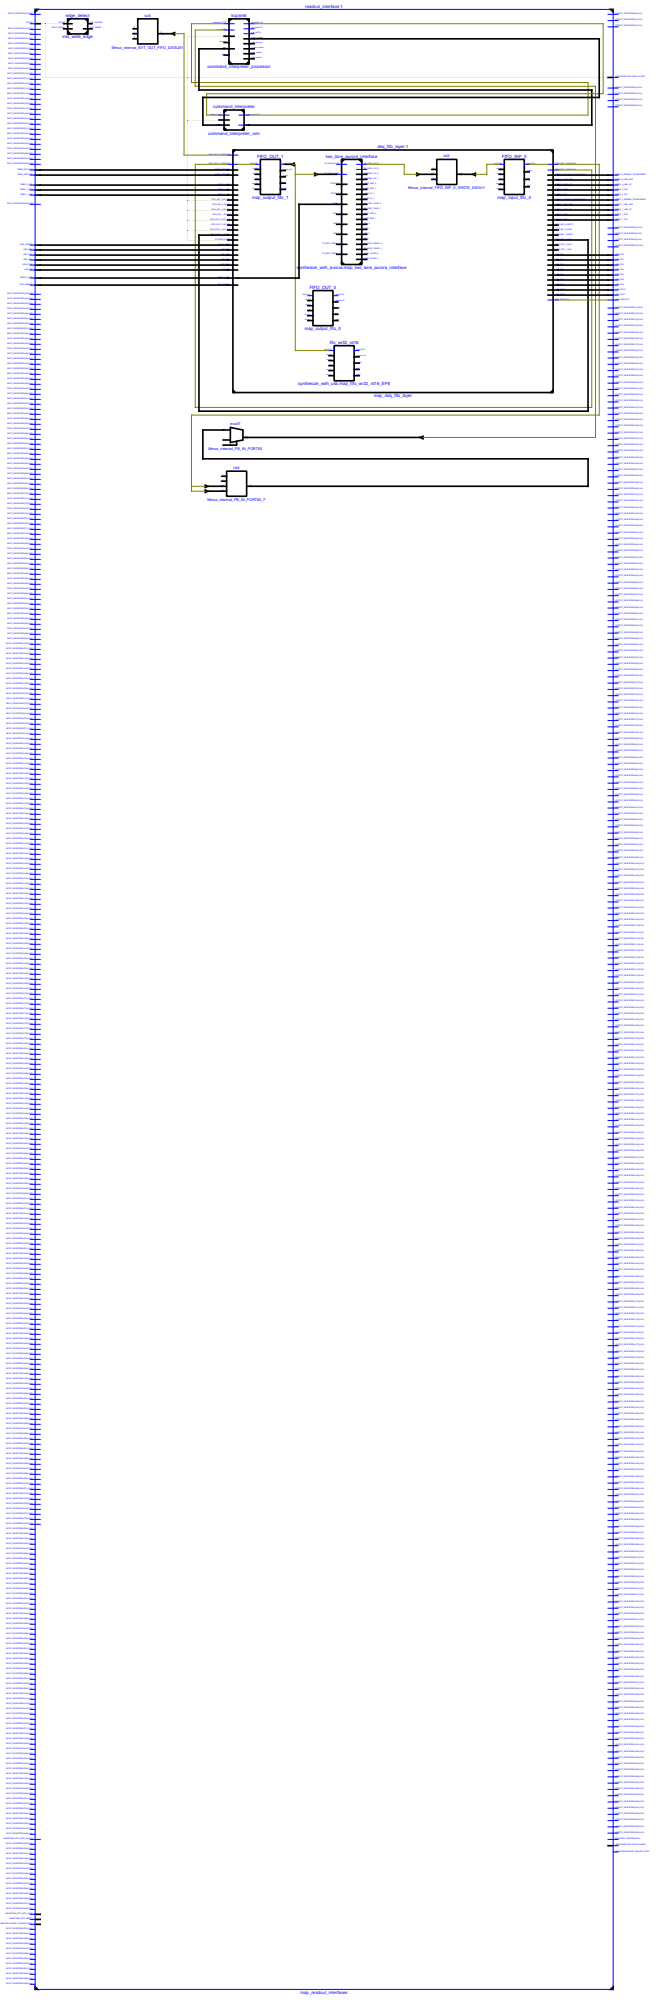
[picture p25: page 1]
CLOCK; INPUT_SIGNAL; OUT_FALLING; OUT_RISING; lut3 Mmux_internal_EVT_OUT_FIFO_DATA251; kcpsm6; command_interpreter_processor; instruction(17:0); address(11:0) out_port(7:0) port_id(7:0) bram_enable; interrupt_ack; k_write_strobe; read_strobe write_strobe; command_interpreter command_interpreter_rom; rdl; FIFO_OUT_1 map_output_fifo_1; din(31:0); rd_clk; rd_en rst wr_clk wr_en; dout(31:0) almost_full empty; full valid; two_lane_aurora_interface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

in_port(7:0) clk
interrupt reset sleep

address(11:0) clk enable

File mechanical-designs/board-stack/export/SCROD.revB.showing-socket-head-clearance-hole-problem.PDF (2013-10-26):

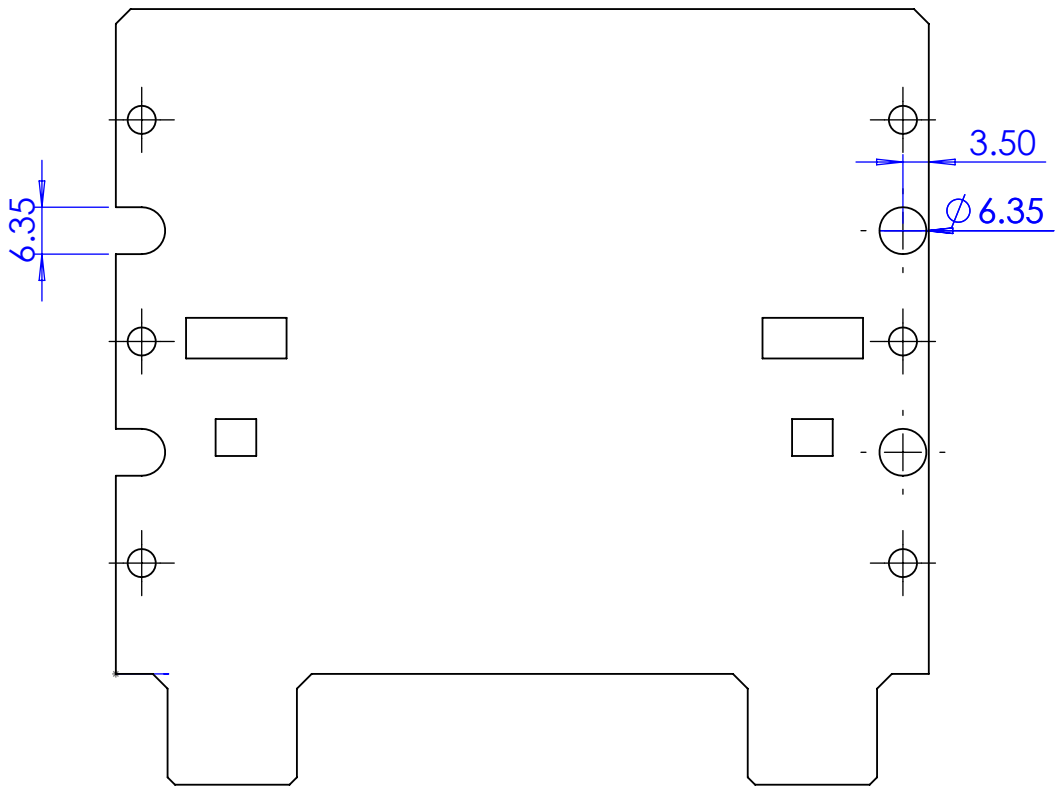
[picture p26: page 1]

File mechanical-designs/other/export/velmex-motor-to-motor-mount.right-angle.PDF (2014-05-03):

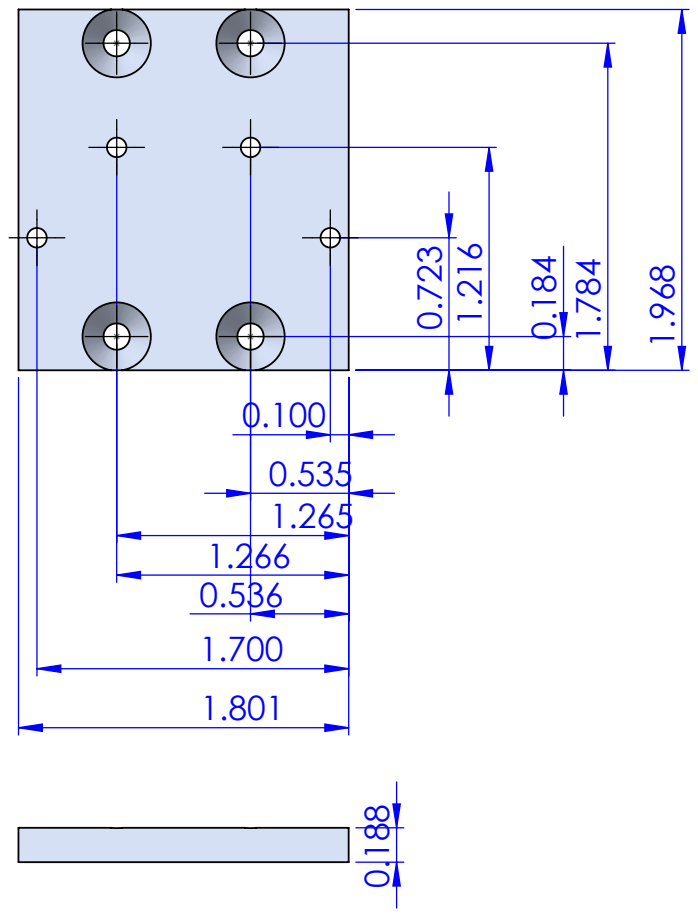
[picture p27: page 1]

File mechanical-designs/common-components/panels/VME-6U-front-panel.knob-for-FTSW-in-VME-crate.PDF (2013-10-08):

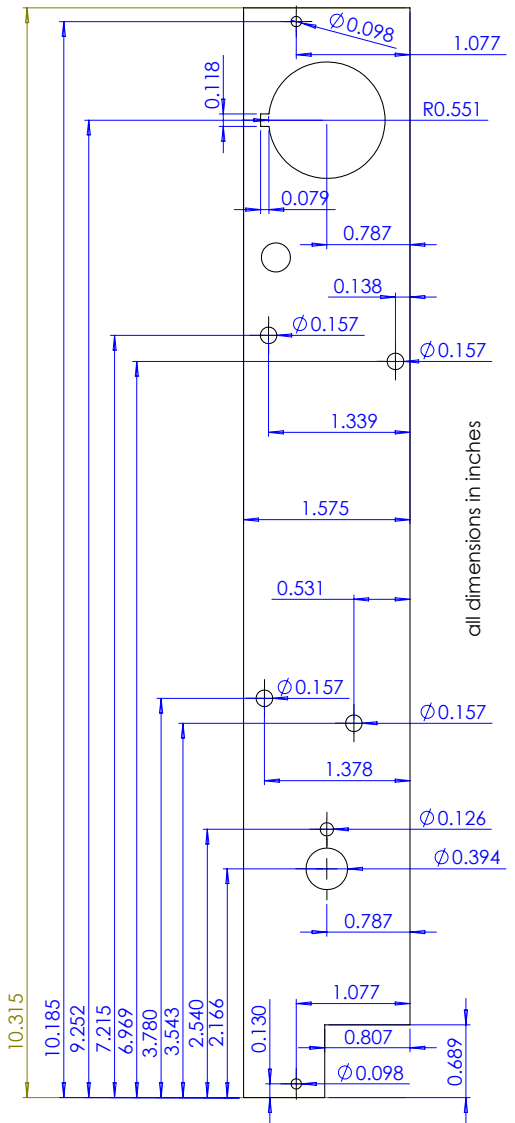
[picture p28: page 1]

all dimensions in inches

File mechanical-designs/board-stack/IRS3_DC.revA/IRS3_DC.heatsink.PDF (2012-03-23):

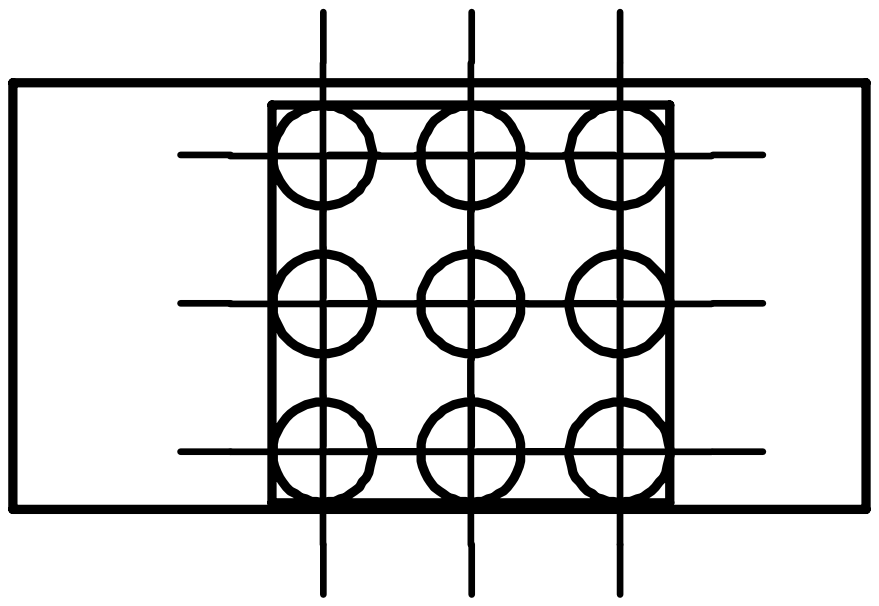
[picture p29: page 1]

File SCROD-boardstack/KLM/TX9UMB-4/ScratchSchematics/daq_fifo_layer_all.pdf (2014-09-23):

# and2

# internal_EVT_INP_FIFO_READ_ENABLE1

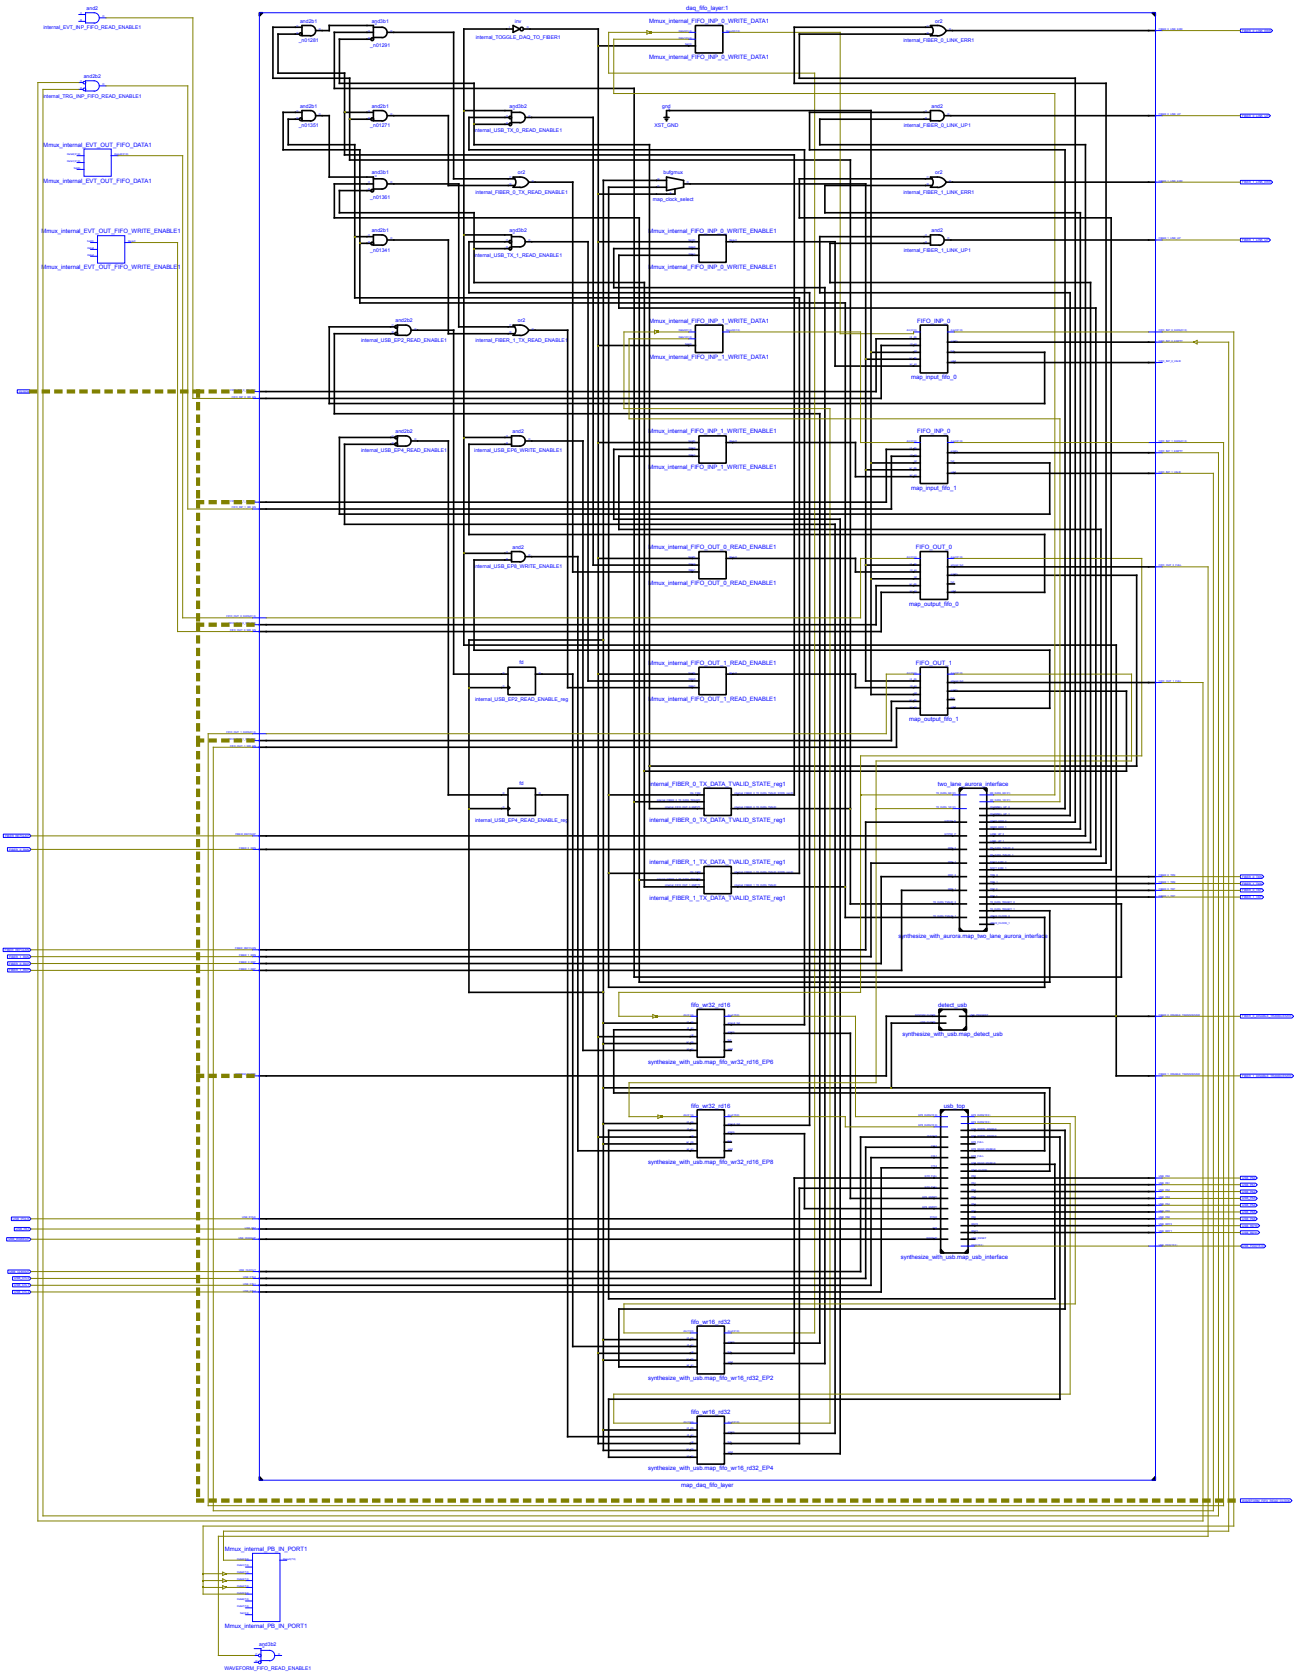
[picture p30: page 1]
and2b2; internal_TRG_INP_FIFO_READ_ENABLE1; Mmux_internal_EVT_OUT_FIFO_DATA1 Mmux_internal_EVT_OUT_FIFO_DATA1; Data0(31:0) Data1(31:0) Sel(0); Result(31:0); Mmux_internal_EVT_OUT_FIFO_WRITE_ENABLE1 Mmux_internal_EVT_OUT_FIFO_WRITE_ENABLE1; Sel(0) Data0 Data1; Result; and2b1; and3b1; internal_USB_EP2_READ_ENABLE1; internal_USB_EP4_READ_ENABLE1; inv; internal_TOGGLE_DAQ_TO_FIBER1; internal_USB_TX_0_READ_ENABLE1; internal_FIBER_0_TX_READ_ENABLE1; internal_FIBER_1_TX_READ_ENABLE1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

and2b1 | and3b2

G | and2

or2 I1 O | bufgmux map_clock_select S

or2 I1 O internal_FIBER_1_LINK_ERR1

I1 O Mmux_internal_FIFO_INP_0_WRITE_ENABLE1 Mmux_internal_FIFO_INP_0_WRITE_ENABLE1 Sel(0) Data0 Data1 Result

and2b1 | and3b2 internal_USB_TX_1_READ_ENABLE1 | and2 internal_FIBER_1_LINK_UP1

and2b2 | and2

Mmux_internal_FIFO_INP_1_WRITE_ENABLE1 Mmux_internal_FIFO_INP_1_WRITE_ENABLE1 Sel(0) Data0 Data1 Result | din(31:0) dout(31:0) empty

and2 | Mmux_internal_FIFO_OUT_0_READ_ENABLE1 Mmux_internal_FIFO_OUT_0_READ_ENABLE1 Sel(0) Data0 Data1 Result

FIFO_OUT_0_DATA(31:0)

FIFO_OUT_0_WR_CLK FIFO_OUT_0_WR_EN

Mmux_internal_FIFO_OUT_1_READ_ENABLE1 Mmux_internal_FIFO_OUT_1_READ_ENABLE1 Sel(0) Data0 Data1 Result

FIFO_OUT_1_WR_CLK

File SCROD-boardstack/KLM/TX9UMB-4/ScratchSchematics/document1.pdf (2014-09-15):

# timing_ctrl

# tmg_ctrl_ins

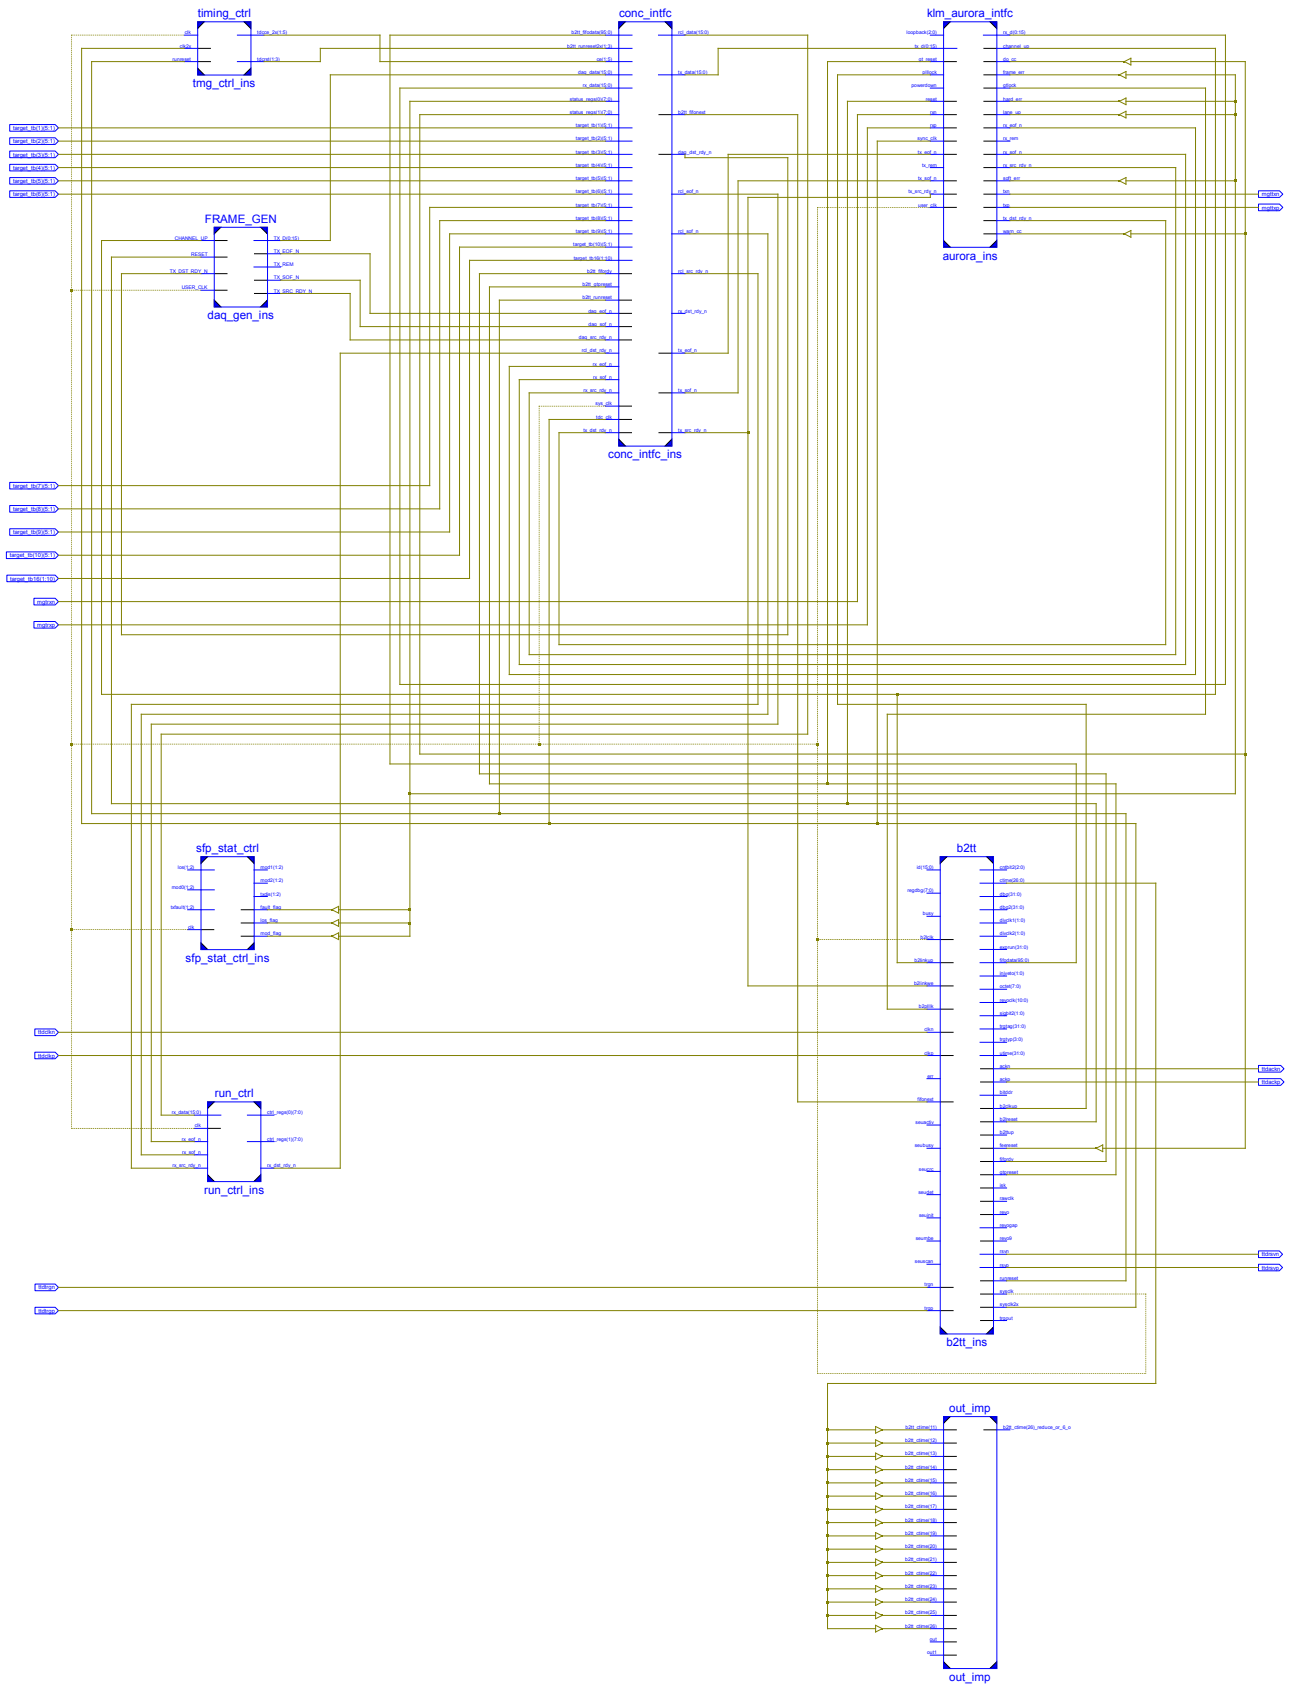
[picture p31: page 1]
clk; clk2x; runreset; tdcce_2x(1:5); tdcrst(1:3); FRAME_GEN; daq_gen_ins; CHANNEL_UP; RESET; TX_DST_RDY_N; USER_CLK; TX_EOF_N; TX_REM; TX_SOF_N; TX_SRC_RDY_N; sfp_stat_ctrl; sfp_stat_ctrl_ins; los(1:2); mod0(1:2); txfault(1:2); mod1(1:2); mod2(1:2); txdis(1:2); fault_flag; los_flag; mod_flag; run_ctrl; run_ctrl_ins; rx_data(15:0); rx_eof_n; rx_sof_n; rx_src_rdy_n; ctrl_regs(0)(7:0); ctrl_regs(1)(7:0); rx_dst_rdy_n; conc_intfc; conc_intfc_ins; b2tt_fifodata(95:0); b2tt_runreset2x(1:3)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

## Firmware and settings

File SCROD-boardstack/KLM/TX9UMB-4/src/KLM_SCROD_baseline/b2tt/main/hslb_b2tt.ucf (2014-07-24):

net clk_127     PERIOD = 7.8 ns;
net clk_s       PERIOD = 23.4 ns;

# VCCO_17 is connected to 3.3V, but iostandard=lvcmos25 is used
# to allow the use of LVDS in bank17

net f_ld<0>  loc=r31  | iostandard=lvttl;    # bank15
net f_ld<1>  loc=t30  | iostandard=lvttl;    # bank15
net f_ld<2>  loc=t31  | iostandard=lvttl;    # bank15
net f_ld<3>  loc=u30  | iostandard=lvttl;    # bank15
net f_ld<4>  loc=v30  | iostandard=lvcmos25; # bank17
net f_ld<5>  loc=w30  | iostandard=lvcmos25; # bank17
net f_ld<6>  loc=w31  | iostandard=lvcmos25; # bank17
net f_ld<7>  loc=y31  | iostandard=lvcmos25; # bank17

net f_la<0>  loc=aa30 | iostandard=lvcmos25; # bank17
net f_la<1>  loc=aa31 | iostandard=lvcmos25; # bank17
net f_la<2>  loc=ab30 | iostandard=lvcmos25; # bank17
net f_la<3>  loc=ab31 | iostandard=lvcmos25; # bank17
net f_la<4>  loc=ac30 | iostandard=lvcmos25; # bank17
net f_la<5>  loc=ad30 | iostandard=lvcmos25; # bank17
net f_la<6>  loc=ad31 | iostandard=lvcmos25; # bank17

net c_lwr    loc=aj32 | iostandard=lvttl;    # bank13
net c_csb    loc=ag32 | iostandard=lvttl;    # bank13

### f_ff<0>  loc=a33  | iostandard=lvttl;    # bank11
### f_ff<1>  loc=b32  | iostandard=lvttl;    # bank11
### f_ff<2>  loc=b33  | iostandard=lvttl;    # bank11
### f_ff<3>  loc=c32  | iostandard=lvttl;    # bank11
### f_ff<4>  loc=c33  | iostandard=lvttl;    # bank11
### f_ff<5>  loc=c34  | iostandard=lvttl;    # bank11
### f_ff<6>  loc=d32  | iostandard=lvttl;    # bank11
### f_ff<7>  loc=d34  | iostandard=lvttl;    # bank11
### f_ff<8>  loc=e32  | iostandard=lvttl;    # bank11
### f_ff<9>  loc=e33  | iostandard=lvttl;    # bank11
### f_ff<10> loc=e34  | iostandard=lvttl;    # bank11
### f_ff<11> loc=f33  | iostandard=lvttl;    # bank11
### f_ff<12> loc=f34  | iostandard=lvttl;    # bank11
### f_ff<13> loc=g32  | iostandard=lvttl;    # bank11
### f_ff<14> loc=g33  | iostandard=lvttl;    # bank11
### f_ff<15> loc=h32  | iostandard=lvttl;    # bank11
### f_ff<16> loc=h33  | iostandard=lvttl;    # bank11
### f_ff<17> loc=h34  | iostandard=lvttl;    # bank11
### f_ff<18> loc=j32  | iostandard=lvttl;    # bank11
### f_ff<19> loc=j34  | iostandard=lvttl;    # bank11
### f_ff<20> loc=k32  | iostandard=lvttl;    # bank11
### f_ff<21> loc=k33  | iostandard=lvttl;    # bank11
### f_ff<22> loc=k34  | iostandard=lvttl;    # bank11
### f_ff<23> loc=l33  | iostandard=lvttl;    # bank11
### f_ff<24> loc=l34  | iostandard=lvttl;    # bank11
### f_ff<25> loc=m32  | iostandard=lvttl;    # bank11
### f_ff<26> loc=m33  | iostandard=lvttl;    # bank11
### f_ff<27> loc=n32  | iostandard=lvttl;    # bank11
### f_ff<28> loc=n33  | iostandard=lvttl;    # bank11
### f_ff<29> loc=n34  | iostandard=lvttl;    # bank11
### f_ff<30> loc=p32  | iostandard=lvttl;    # bank11
### f_ff<31> loc=p34  | iostandard=lvttl;    # bank11

### f_frstb  loc=r32  | iostandard=lvttl;    # bank11
### f_fwenb  loc=t34  | iostandard=lvttl;    # bank11
### f_fwclk  loc=t33  | iostandard=lvttl;    # bank11
net f_nwff   loc=u31  | iostandard=lvttl;    # bank11
net f_fwful  loc=r34  | iostandard=lvttl;    # bank11

net f_tag<0> loc=j31  | iostandard=lvttl;    # bank15
net f_tag<1> loc=l30  | iostandard=lvttl;    # bank15
net f_tag<2> loc=l31  | iostandard=lvttl;    # bank15
net f_tag<3> loc=m30  | iostandard=lvttl;    # bank15
net f_tag<4> loc=m31  | iostandard=lvttl;    # bank15
net f_tag<5> loc=n30  | iostandard=lvttl;    # bank15
net f_tag<6> loc=p30  | iostandard=lvttl;    # bank15
net f_tag<7> loc=p31  | iostandard=lvttl;    # bank15

net f_typ<0> loc=g30  | iostandard=lvttl;    # bank15
net f_typ<1> loc=g31  | iostandard=lvttl;    # bank15
net f_typ<2> loc=h30  | iostandard=lvttl;    # bank15
net f_typ<3> loc=j30  | iostandard=lvttl;    # bank15

net f_abrt   loc=u32  | iostandard=lvttl;    # bank11
net f_iena   loc=f30  | iostandard=lvttl;    # bank15
net f_irstb  loc=e31  | iostandard=lvttl;    # bank15
net f_io     loc=f31  | iostandard=lvttl;    # bank15
net f_gate   loc=r33  | iostandard=lvttl;    # bank11
net f_bsy    loc=u33  | iostandard=lvttl;    # bank11

net f_trg_p  loc=aj31 | iostandard=lvds_25 | diff_term=yes; # bank17
net f_trg_n  loc=ak31 | iostandard=lvds_25 | diff_term=yes; # bank17
net f_rev_p  loc=aj30 | iostandard=lvds_25 | diff_term=yes; # bank17
net f_rev_n  loc=ah30 | iostandard=lvds_25 | diff_term=yes; # bank17
net f_rck_p  loc=ah29 | iostandard=lvds_25 | diff_term=yes; # bank17
net f_rck_n  loc=ag30 | iostandard=lvds_25 | diff_term=yes; # bank17
### f_rck_p  clock_dedicated_route = false;
net v_sck_p  loc=ag22 | iostandard=lvds_25;  # bank4 (no diff_term needed)
net v_sck_n  loc=ah22 | iostandard=lvds_25;  # bank4
### bclk_p   loc=ah20 | iostandard=lvds_25;  # bank4 (no diff_term needed)
### bclk_n   loc=ah19 | iostandard=lvds_25;  # bank4

# need to clarify which LED is where
### led1     loc=ac4  | iostandard=lvcmos25; # bank18 (RJ-45 upper, unused)
### led2     loc=ab6  | iostandard=lvcmos25; # bank18 (RJ-45 lower, unused)
net ledl     loc=e8   | iostandard=lvttl;    # bank20 (L700, panel top-left)
net ledr     loc=f8   | iostandard=lvttl;    # bank20 (L701, panel top-right)
### led5     loc=k8   | iostandard=lvttl;    # bank20 (L702, unused)
### led6     loc=k9   | iostandard=lvttl;    # bank20 (L703, unused)

net led<0>   loc=d10  | iostandard=lvttl;    # bank20 (L704, DS705-on-board)
net led<1>   loc=d11  | iostandard=lvttl;    # bank20 (L705, DS706-on-board)
net led<2>   loc=b12  | iostandard=lvttl;    # bank20 (L706, DS707-on-board)
net led<3>   loc=c12  | iostandard=lvttl;    # bank20 (L707, DS708-on-board)
net led<4>   loc=d12  | iostandard=lvttl;    # bank20 (L708, DS709-on-board)
net led<5>   loc=a13  | iostandard=lvttl;    # bank20 (L709, DS710-on-board)
net led<6>   loc=b13  | iostandard=lvttl;    # bank20 (L710, DS711-on-board)
net led<7>   loc=c13  | iostandard=lvttl;    # bank20 (L711, DS712-on-board)

net test<0>  loc=am11 | iostandard=lvcmos25; # bank22 (TEST700 at P701-1)
net test<1>  loc=ak11 | iostandard=lvcmos25; # bank22 (TEST701 at P701-3)
net test<2>  loc=al11 | iostandard=lvcmos25; # bank22 (TEST702 at P701-5)
net test<3>  loc=al10 | iostandard=lvcmos25; # bank22 (TEST703 at P701-7)
net test<4>  loc=aj11 | iostandard=lvcmos25; # bank22 (TEST704 at P701-9)
net test<5>  loc=aj10 | iostandard=lvcmos25; # bank22 (TEST705 at P701-11)
net test<6>  loc=ah10 | iostandard=lvcmos25; # bank22 (TEST706 at P701-13)
net test<7>  loc=ag10 | iostandard=lvcmos25; # bank22 (TEST707 at P701-15)

### clk_tp   loc=an13 | iostandard=lvds_25 | diff_term=yes; # bank22
### clk_tn   loc=am13 | iostandard=lvds_25 | diff_term=yes; # bank22

net r_ackb_p loc=ad4  | iostandard=lvds_25;  # bank18 (wrong polarity)
net r_ackb_n loc=ad5  | iostandard=lvds_25;  # bank18 (wrong polarity)
net r_rsv_p  loc=ac7  | iostandard=lvcmos25; # bank18
net r_rsv_n  loc=ad7  | iostandard=lvcmos25; # bank18
net r_trg_p  loc=ak7  | iostandard=lvds_25 | diff_term=yes; # bank18
net r_trg_n  loc=ak6  | iostandard=lvds_25 | diff_term=yes; # bank18
net r_clkb_p loc=ad6  | iostandard=lvds_25 | diff_term=yes; # bank18 (wrong)
net r_clkb_n loc=ae6  | iostandard=lvds_25 | diff_term=yes; # bank18 (polarity)
net r_clkb_p clock_dedicated_route = false;

net mode0    loc=f6   | iostandard=lvttl;    # bank12
net mode1    loc=e7   | iostandard=lvttl;    # bank12
net mode2    loc=f5   | iostandard=lvttl;    # bank12
net los      loc=g5   | iostandard=lvttl;    # bank12
net ratesel  loc=j5   | iostandard=lvttl;    # bank12
net txfault  loc=j6   | iostandard=lvttl;    # bank12
net txdis    loc=e6   | iostandard=lvttl;    # bank12

### mode10   loc=m6   | iostandard=lvttl | pullup=yes; # bank12
### mode11   loc=l5   | iostandard=lvttl | pullup=yes; # bank12
### mode12   loc=l4   | iostandard=lvttl | pullup=yes; # bank12
### los1     loc=n5   | iostandard=lvttl;    # bank12
### ratesel1 loc=n7   | iostandard=lvttl;    # bank12
### txfault1 loc=n8   | iostandard=lvttl;    # bank12
### txdis1   loc=k6   | iostandard=lvttl;    # bank12

# MGT bank 112 port 0 / RX:normal-polarity, TX:flipped-polarity

### r_clkopt_p loc=p4; # MGTREFCLKP_112, UCF is not needed
### r_clkopt_n loc=p3; # MGTREFCLKN_112, UCF is not needed
### rx_p     loc=n1;   # MGTRXP0_112, UCF is not needed
### rx_n     loc=p1;   # MGTRXN0_112, UCF is not needed
### tx_n     loc=m2;   # MGTTXP0_112, UCF is not needed (flipped-polarity)
### tx_p     loc=n2;   # MGTTXN0_112, UCF is not needed (flipped-polarity)
### rx_p1    loc=w1;   # MGTRXP0_114 unused
### rx_n1    loc=y1;   # MGTRXN0_114 unused
### tx_n1    loc=v2;   # MGTTXP0_114 unused (flipped-polarity)
### tx_p1    loc=w2;   # MGTTXN0_114 unused (flipped-polarity)

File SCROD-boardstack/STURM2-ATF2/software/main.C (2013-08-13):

#include <TApplication.h> 
#include <TGClient.h> 
#include "Riostream.h"
#include "USBdisplay.h" 
//////////////////////////////////////
using namespace std;
using std::cout;
using std::cin;
using std::endl;
void guitest(int verbose,int OffLineMode);
 //////////////////////////////////////
int main(int argc, char **argv)
{
  TApplication theApp("App", &argc, argv);
   if (gROOT->IsBatch()) {
      fprintf(stderr, "%s: cannot run in batch mode\n", argv[0]);
      return 1;
   }
   guitest(false,false);
   theApp.Run();
   return 0;
}
//////////////////////////////////////
void guitest(int verbose,int OffLineMode)
{
  bool verbose_check;
  bool OffLineMode_check;
  if(verbose == 1){
    verbose_check = true;
    cout << "verbose is true" << endl;
  }
  else{
    verbose_check = false;    
    cout << "verbose is false" << endl;
  }
  if(OffLineMode == 1){
    OffLineMode_check = true;
    cout << "OffLineMode is true" << endl;
  }
  else{
    OffLineMode_check = false;    
    cout << "OffLineMode is false" << endl;
  }
   new MainFrame(gClient->GetRoot(),verbose_check,OffLineMode_check);
}
//////////////////////////////////////

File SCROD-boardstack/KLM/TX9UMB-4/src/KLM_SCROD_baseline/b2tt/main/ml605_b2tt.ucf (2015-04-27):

# SP605 FMC + modified TB-FMCL-PH
#  ack_p:    TM21Rmod-2 CN4-12 S6-H10 # LA10_P (opposite polarity)
#  ack_n:    TM21Rmod-1 CN4-11 S6-H11 # LA10_N
#  trg_p:    TM21Rmod-3 CN4-8  S6-D4  # LA06_P (correct polarity)
#  trg_n:    TM21Rmod-6 CN4-7  S6-D5  # LA06_N
#  clk_p:    TM21Rmod-8 CN4-6  S6-C4  # LA05_P (opposite polarity)
#  clk_n:    TM21Rmod-7 CN4-5  S6-A4  # LA05_N
#
#  ext0_p:   TM21R-1 CN4-25   S6-AB10 # LA27_N (opposite polarity)
#  ext0_n:   TM21R-2 CN4-26   S6-AA10 # LA27_P
#  ext1_p:   TM21R-3 CN4-24   S6-U14  # LA26_P (not for standard LAN cable)
#  ext1_n:   TM21R-4 CN4-23   S6-U13  # LA26_N
#  ext2_n:   TM21R-5 CN4-22   S6-U9   # LA23_P (not for standard LAN cable)
#  ext2_p:   TM21R-6 CN4-21   S6-V9   # LA23_N
#  clkout_p: TM21R-7 CN4-19   S6-U12  # LA18_N (opposite polarity)
#  clkout_n: TM21R-8 CN4-20   S6-T12  # LA18_P

# ML605-J63 FMC_LPC + modified TB-FMCL-PH
#  ack_p:    TM21Rmod-2 CN4-12 V6-F30 # LA10_P (opposite polarity)
#  ack_n:    TM21Rmod-1 CN4-11 V6-G30 # LA10_N
#  trg_p:    TM21Rmod-3 CN4-8  V6-K33 # LA06_P (correct polarity)
#  trg_n:    TM21Rmod-6 CN4-7  V6-J34 # LA06_N
#  clk_p:    TM21Rmod-8 CN4-6  V6-H34 # LA05_P (opposite polarity)
#  clk_n:    TM21Rmod-7 CN4-5  V6-H33 # LA05_N
#
#  ext0_p:   TM21R-2 CN4-26   V6-R31  # LA27_P (opposite polarity)
#  ext0_n:   TM21R-1 CN4-25   V6-R32  # LA27_N
#  ext1_p:   TM21R-3 CN4-24   V6-L33  # LA26_P (not for standard LAN cable)
#  ext1_n:   TM21R-4 CN4-23   V6-M32  # LA26_N
#  ext2_n:   TM21R-5 CN4-22   V6-R28  # LA23_P (not for standard LAN cable)
#  ext2_p:   TM21R-6 CN4-21   V6-R27  # LA23_N
#  clkout_n: TM21R-8 CN4-20   V6-L29  # LA18_P (opposite polarity)
#  clkout_p: TM21R-7 CN4-19   V6-L30  # LA18_N

#
# SMA_GPIO_P - S6 A3
# SMA_GPIO_N - S6 B3
# 
# LED0 - DS3 - S6 D17
# LED1 - DS4 - S6 AB4
# LED2 - DS5 - S6 D21
# LED3 - DS6 - S6 W15
#
# USER_CLOCK(lclk) - S6 AB13

net ack_p loc=f30 | iostandard=lvds_25;
net ack_n loc=g30 | iostandard=lvds_25;
net trg_p loc=k33 | iostandard=lvds_25 | diff_term=true;
net trg_n loc=j34 | iostandard=lvds_25 | diff_term=true;
### rsv_p loc=xx  | iostandard=lvds_25;
### rsv_n loc=xx  | iostandard=lvds_25;
net clk_p loc=h34 | iostandard=lvds_25 | diff_term=true;
net clk_n loc=h33 | iostandard=lvds_25 | diff_term=true;
net clk_p clock_dedicated_route = false;
### clkout_p clock_dedicated_route = false;

net clk_127 period = 7.8 ns;
#net b2tt/clk_inv period = 7.8 ns;

net ext_p<0> loc=r31  | iostandard=lvcmos25;
net ext_n<0> loc=r32  | iostandard=lvcmos25;
net ext_p<1> loc=l33  | iostandard=lvcmos25;
net ext_n<1> loc=m32  | iostandard=lvcmos25;
net ext_p<2> loc=r28  | iostandard=lvcmos25;
net ext_n<2> loc=r27  | iostandard=lvcmos25;
### clkout_p loc=l29  | iostandard=lvds_25;
### clkout_n loc=l30  | iostandard=lvds_25;

# net user_clock loc=u23 | iostandard=lvcmos25;
net sma_gpio_p loc=v34 | iostandard=lvcmos25;
net sma_gpio_n loc=w34 | iostandard=lvcmos25;

net led<0> loc=ac22 | iostandard=lvcmos25;
net led<1> loc=ac24 | iostandard=lvcmos25;
net led<2> loc=ae22 | iostandard=lvcmos25;
net led<3> loc=ae23 | iostandard=lvcmos25;
net led<4> loc=ab23 | iostandard=lvcmos25;
net led<5> loc=ag23 | iostandard=lvcmos25;
net led<6> loc=ae24 | iostandard=lvcmos25;
net led<7> loc=ad24 | iostandard=lvcmos25;

### J62 header corresponds to LED

### pushsw<0>  loc = a19;   ## SW5 (N) pushbutton (active-high) lvcmos15
net pushsw<1>  loc = a18;   ## SW6 (S) pushbutton (active-high) lvcmos15
net pushsw<2>  loc = g17;   ## SW7 (E) pushbutton (active-high)
net pushsw<3>  loc = h17;   ## SW8 (W) pushbutton (active-high)
### pushsw<4>  loc = g26;   ## SW9 (C) pushbutton (active-high)

net dipsw<0>  loc = d22;    ## 1 on SW1 DIP switch (active-high)
net dipsw<1>  loc = c22;    ## 2 on SW1 DIP switch (active-high)
net dipsw<2>  loc = l21;    ## 3 on SW1 DIP switch (active-high)
net dipsw<3>  loc = l20;    ## 4 on SW1 DIP switch (active-high)
net dipsw<4>  loc = c18;    ## 5 on SW1 DIP switch (active-high)
net dipsw<5>  loc = b18;    ## 6 on SW1 DIP switch (active-high)
net dipsw<6>  loc = k22;    ## 7 on SW1 DIP switch (active-high)
net dipsw<7>  loc = k21;    ## 8 on SW1 DIP switch (active-high)

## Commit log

2011-06-29 Working version to test for shorts. To be used without a daughter card plugged in, for now. Only two interconnect connector's worth of signals can be probed at once, J1 and J2 or J3 and J4. The chang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
2011-07-09 Reads out 8 windows in one-shot/common-start mode. Includes a chipscope file with bias voltages that indicate proper settings for approximate use. The target sampling rate was 1 GSa/s. There's one pr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
2011-07-20 reworked aurora reset input signal timing; added state machine to generate 1MHz, 1kHz and 1Hz clock; added 9 second spill / 40 second recharge structure, along with exchanging one of the packet_gener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
2011-07-27 fixed the double-footer problem; changed chipscope inputs / outputs; added else case to data_generator to try to find double footer problem; reloaded chipscope project and that seemed to fix some qui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
2011-08-10 determined algorithm to guarantee fiber link comes up (as long as both sides assert the disable line on the transceiver) - verified with SCROD2SCROD; fixed mistake in pin constraint for tx_dis line i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
2011-08-10 Now receives clocks from Nakao-san's FTSW blocks and runs off of them. Sampling is tuned for 2.7 gigasamples/sec in both the chipscope file and in the code (SSP, SST, WR_STRB frequencies, etc.). In a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
2011-08-11 reworked fiber disable/reenable algorithm to guarantee power up (actually read datasheet this time); reworked main timing loop to give out 1kHz clock; clock spill/fill and fiber link reset state mach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
2011-08-13 Replaced trunk with current version of sampling, with FTSW receiver firmware.
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2011-09-01 added quarter_event_builder and packet_builder, enabled first word fall through on quarter event fifo (fixes problem where last word of last packet would show up as first word of current packet), add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
2011-09-04 fixed checksum calculation; added more time for aurora startup over 50m cable
2011-09-10 added quarter_event_builder and packet_builder, enabled first word fall through on quarter event fifo (fixes problem whe re last word of last packet would show up as first word of current packet), ad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
2011-09-28 modularized chipscope (although the buttons have been broken for a couple commits)
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2011-10-03 Added trigger scalers and trigger stream functionality, although admittedly with only limited testing, since it's difficult to do thorough scans in chipscope. The monitor header pins for output have 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
2011-10-24 added commands to set start and end windows; added some missing connections between upper and lower levels that were found by reading the warning messages; added a couple default values for things th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
2011-11-05 Modified the LTC2637 interface so that the intended DAC values are registered before embarking on the update, so that they don't change in the middle of your IIC commands. Also modified the Board_Sta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
2011-11-05 Added housekeeping packet to the data stream. Checked it minimally to ensure that the temperature was correct and the right number of DAC values appeared nonzero in a test with a couple of daughter c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
2011-11-07 Committing changes to Wilkinson feedback stuff. These are mid-debugging changes, so there are issues with this firmware at the moment where some slots seem to give metastable or totally unstable feed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
2011-11-22 Modified Wilkinson feedback so that the target DAC values now have an associated 'valid' flag. The DAC state machine clock also now comes to the Wilkinson feedback blocks, so that the DAC values are 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
2011-11-29 Added skeleton support for the sampling rate feedback. Unfortunately, instantiating the actual feedback loop + carry chain causes map to fail with no explicit errors reported. This part is currently 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
2011-12-02 Added a number of changes: 1) Added sampling rate feedback, which appears to be working, though it hasn't been stringently tested for stability. 2) Added a signal to indicate whether FTSW has been st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
2011-12-05 Tweaked trigger stream a bit to make it continue after the trigger is received. Bit 2 (starting from 0) now seems to correspond to the last 32-sample window. Bit 9 then is the first 32 sample window.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
2012-03-23 initial add of 3D models of iTOP and fDIRC assemblies (SolidWorks 2012)
    [1206.inductor.SLDPRT, 2mm-connector-male-pin-surface-mount.3.SLDPRT, 2mm-connector-male-pin-surface-mount.pair.1.SLDPRT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]
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2012-04-05 took some more mTC measurements; added power connector to fDIRC front board
    [H8500-front.SLDASM, H8500-front.components-back.SLDASM, H8500-front.components-front.SLDASM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]
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2012-12-06 New version of SCROD firmware with new DAQ interface. This version runs on local clock only for now, though it is destined to be merged w with FTSW receiver functionality, and may be further merged w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
    [command_interpreter.psm, picoblaze_registers_and_memory.xlsx, register_map.xlsx]
2013-01-11 added new carrier02 revB; modified a few things here and there; added STEP files for easy file interchange
    [IRS2_DC.revB2.16.heatsink.STEP, IRS2_DC.revB2.4.SLDASM, IRS2_DC.revB2.4.heatsink.STEP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]
2013-01-11 added carrier02 to boardstack; changed carriers to have mates between surfaces instead of being fixed at locations in 3-space
    [IRS2_DC.revB2.SLDASM, SCROD.SLDASM, board-stack.common.SLDASM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]
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2013-01-12 added power connector to carrier02; fixed positions of 100/120 pin connectors
    [IRS2_DC.revB2.SLDASM, board-interconnects.100-and-120-pin.9mm.SLDPRT, board-stack.common.SLDASM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]
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2013-01-16 actually imported PCB shape this time for the carrier02, so the model should be precise
    [board-stack.common.SLDASM, carrier02.revB.PCB.SLDPRT, carrier02.revB.SLDASM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]
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2013-01-23 added Gerard's HV SL10 module; adjusted spacing on front-back; added center-of-slot planes to each PCB; adjusted boardstack mating to be based on these and be 10.78 mm; adjusted carrier0/interconnect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
    [SCROD.SLDASM, SCROD.revA2.SLDPRT, SL10-HV-module.revA.IU.PCB.SLDPRT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]
2013-01-23 repaired error in model; added alignment axis to parts
    [connector.2mm.09-pin.female.surface-mount.SLDASM, connector.2mm.09-pin.male.through-hole.chopped-off.SLDASM, connector.2mm.16-pin.female.SLDPRT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]
2013-01-23 added alignment axes to some connectors; fixed alignment error between front-front and front-back
    [connector.2mm.09-pin.female.surface-mount.SLDASM, connector.2mm.09-pin.male.through-hole.chopped-off.SLDASM, front-back.SLDASM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]
2013-01-23 minor changes to make more accurate model of HV module; added exported HV module STEP file
    [SL10-HV-module.revA.IU.bottom-plate.SLDPRT, SL10-HV.SLDASM, SL10-HV.STEP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]
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2013-01-27 updated model to reflect PCB designs more accurately (alignment of connectors relative to board edges) on front-front and front-back; grabbed new shape of submitted carrier13 revB
    [SCROD.SLDASM, SL10-HV-module.revA.IU.PCB.SLDPRT, SL10-HV.SLDASM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]
2013-01-30 added individual components for SCROD and updated locations for SCROD revA2; added some detail to power input connector; added monitor header part; added ASIC part
    [14-pin.2mm.jtag-header.right-angle.SLDPRT, 5mm-by-7mm.oscillator.SLDPRT, 6-pin-0.1-inch-right-angle.SLDPRT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]
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2013-02-06 Changes to accommodate remote clocking (using CLK_FIN only, FTSW version not yet implemented). Added command interpreter ROM file to project so that you don't have to assemble it yourself (picoblaze 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
    [register_map.xlsx]
2013-02-11 added preliminary interconnect revC; added MMCX board-edge cutout connector; modified optical table slightly; added pin puller jigs for 16 pin and 22 pin connectors
    [16pin-2mm-pin-puller.SLDASM, 16pin-2mm-pin-puller.SLDDRW, 16pin-2mm-pin-puller.SLDPRT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]
2013-02-14 organized files; retired some content; made a duplicate of SCROD revA2 to try to come up with a mockup of a SCROD revB
    [14-pin.2mm.jtag-header.right-angle.SLDPRT, 2mm-connector-male-pin-surface-mount.3.SLDPRT, 2mm-connector-male-pin-surface-mount.pair.1.SLDPRT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]
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2013-03-10 moved one SCROD mounting hole to correct position
    [SCROD.SLDASM, SCROD.revA2.SLDPRT, board-stack.common.SLDASM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]
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2013-03-11 Added support for I2C devices (all except the VadjN/P external DACs). Expanded write registers to 512 and read registers to 768. Starting remapping but haven't finished yet. Check the register_map in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
    [boardstack-i2c-addresses-and-busses.xls, command_interpreter.psm, register_map.xlsx]
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2013-03-12 Updating working register map so that software can begin to be updated...
    [register_map.xlsx]
2013-03-12 Many additions: added multi-ASIC DAC support, added monitoring of Wilkinsons, added many startup features for the picoblaze, includingg setting registers for the ASIC DAC buffer biases that keep the 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
    [command_interpreter.psm, register_map.xlsx]
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2013-03-13 Attempting to add VadjP/N external DAC support. It only works right now for rows 0 and 2...
    [register_map.xlsx]
2013-03-14 Implemented RCO feedback with a simple, move-one-count-at-a-time loop. The RCO monitor has been changed from Luca's original to the same as the one that reads out the Wilkinson monitor counter. Regis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
    [register_map.xlsx]
2013-03-14 Added some missing files for IRS3B support.
    [register_map.xlsx]
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2013-03-20 Reverted counter to Luca's original version, since I believe the Wilkinson-style counter has an aliasing problem at input rates higher than ~25 MHz. Also switched the feedback loop being used back to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
2013-03-22 Found typo that was causing event number and SCROD ID word to be swapped in waveform packets.
    [command_interpreter.psm]
2013-03-24 Incorporated Luca's changing to sampling blocks. Including new register assignments for selecting sampling phases (PHAB) in register 379. Added monitor pins as well, as per Luca's usage.
    [register_map.xlsx]
2013-03-24 Added the following features: monitor header pins now let you monitor RCOSSX and MONTIMING, with ASIC selectable by register 380. Counter has been added to read register 610 that reports the number o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
    [register_map.xlsx]
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2013-03-25 Re-added location constraint for FTSW PLL. Added some monitoring to debug sampling state machine.
    [register_map.xlsx]
2013-03-25 Commited changes to chipscope project to monitor SDR section, including checking state of sampling block. Found a dangling signal to sampling block. now the same MONTIMING signal that is selected for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
    [register_map.xlsx]
2013-03-25 Commited changes to chipscope project to monitor SDR section, including checking state of sampling block. Found a dangling signal to sampling block. now the same MONTIMING signal that is selected for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
    [register_map.xlsx]
2013-03-25 Added Luca's suggested modification to the sampling block to fix the synchronization.
    [register_map.xlsx]
2013-03-27 Page 4 of the register map has been updated for increased clarity on meaning of various signals.
    [register_map.xlsx]
2013-03-29 A number of changes have been made: CLKx4SST has been removed in favor of CLKx2SST to make the timing margins easier for the firmware to infer automatically. The CE that was previously used divide CL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
    [register_map.xlsx]
2013-03-29 Fixes to ROI block to account for the change in trigger memory address depth. Minor changes to register map for new monitoring pin features.
    [register_map.xlsx]
2013-03-29 Added an extra bit to register 379 to allow toggling between the two possibilities for the LSB of the write address. Added a read register at 611 for firmware revision. This is controlled by a small 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
    [register_map.xlsx]
2013-03-31 Added first stab at WBIAS/Trigger width monitoring and feedback. Added extra MUX functionality to MON2 to allow looking at different bits of the write address on that pin, as an alternative to lookin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
    [register_map.xlsx]
2013-04-03 fixed typo in ucf file in order to get I2C bus on interconnect revC to work
2013-04-04 Fix to sampling block to avoid readout instabilities (LAST_ALLOWED_ADDRESS was changing in the middle of ROI and digitizer operation. Now it's stopped after sampling ceases.) Change to readout addres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
    [command_interpreter.psm, register_map.xlsx]
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2013-05-16 Fixed a pin mapping error on the trigger bits in the UCF. Row 3 column 3 channel 5 was swapped with row 1 column 3 channel 5. Updated the firmware version register. Reverting away from r341 change to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
2013-10-08 potential final iTOP boardstack design; changed from cardcage to thermal wall structure; removed interconnect; changed connector heights; revamped SCROD and carrier boards entirely; missing pogo plat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
    [14-pin.2mm.jtag-header.right-angle.SLDPRT, 5mm-by-7mm.oscillator.SLDPRT, 6-pin-0.1-inch-right-angle.SLDPRT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]
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2013-10-14 changed pitch of signal pogo pins to 1.8 mm; added detail to carrier board to provide keepout for HV caps on front board; shortened thermal spacers to 88 mm
    [SCROD-and-carriers-with-walls.SLDASM, SCROD-and-carriers-with-walls.new-carrier-shape.SLDDRW, SCROD-and-carriers.SLDASM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]
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2013-10-14 J-curve shaped carrier North end and extra HV clearance
    [SCROD-and-carriers-with-walls.SLDASM, SCROD-and-carriers.SLDASM, board-spacers.SLDPRT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]
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2013-11-07 changed remote clock source IO for SCROD revA3 DIP switch (the jumper on c02 will no longer function\!)
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2014-02-12 edited power supply voltages / currents for intermediate short boardstack (one SCROD, one interconnect, one carrier02)
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2014-03-02 Implemented buffer FIFO and readout flow control module, fixes the USB data dropping at the cost of readout speed
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2014-12-15 Pedcalc only working with single averaging. C&T calculation implemented and is reported with the new package structure through the USB. - WIP some bugs to be worked out
    [compile.cfg, library.cfg, projlib.cfg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]
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2015-04-27 BK: Fix b2tt multiple-driver issue.
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
